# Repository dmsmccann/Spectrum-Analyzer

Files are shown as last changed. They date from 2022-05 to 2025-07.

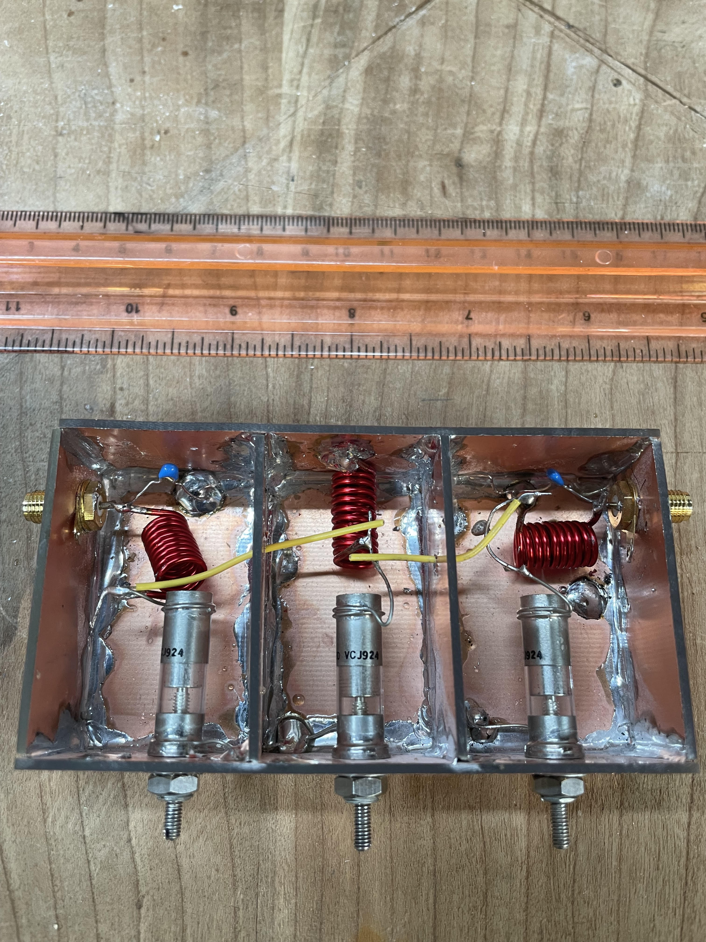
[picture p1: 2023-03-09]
110mhz-filter image.jpg

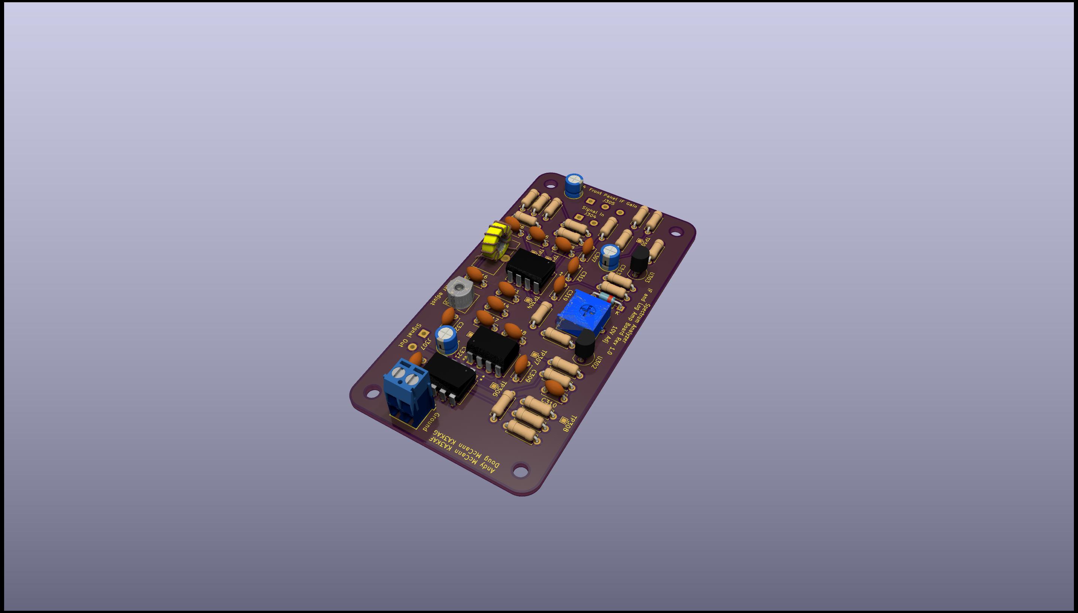
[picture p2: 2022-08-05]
if-and-log-amp/if-and-log-amp/if-and-log-amp.jpg

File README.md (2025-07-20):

# W7ZOI Spectrum Analyzer

## KiCad Implementation with modifications by Andy McCann KA3KAF and Doug McCann KA3KAG

## Overview

This repository contains a complete KiCad implementation of the famous W7ZOI Spectrum Analyzer design, originally published in QST magazine. The W7ZOI spectrum analyzer is a well-regarded amateur radio test instrument design that provides a cost-effective solution for RF spectrum analysis.

## Project Description

The W7ZOI Spectrum Analyzer is a superheterodyne spectrum analyzer designed for amateur radio applications. It provides frequency analysis capabilities across the HF and VHF bands, making it an invaluable tool for antenna analysis, filter characterization, and general RF measurements.

### Key Features

- **Frequency Range**: Covers HF through VHF bands
- **Modular Design**: Hierarchical schematic organization for easy understanding and modification
- **Complete Implementation**: Includes all necessary subsystems:
  - VCO and 1st Mixer
  - 110 MHz / 7 MHz Filter sections
  - IF and Log Amplifier
  - 2nd Mixer and 2nd LO
  - Resolution Filters
  - Timebase circuitry
  - 15V Power Supply
  - 2dB Divider
  - 70 MHz Low-pass Filter

## Repository Structure

```text
├── hierarchical-schematic/     # Main hierarchical schematic files
├── 110mhz/                    # 110 MHz filter module
├── 15v-supply/                # Power supply module
├── 2db-div/                   # 2dB divider module
├── 2ndmixer-2ndlo/           # 2nd mixer and LO module
├── 70mhz-lpf/                # 70 MHz low-pass filter
├── 7mhz-crystal-oscillator/  # 7 MHz crystal oscillator
├── if-and-log-amp/           # IF and log amplifier
├── resolution-filters/        # Resolution filter bank
├── timebase/                 # Timebase generation
├── tracking-generator/        # Tracking generator module
├── vco-1stmixer/             # VCO and 1st mixer
├── literature/               # Reference documentation and articles
├── images/                   # Project images and diagrams
└── experimental-data/        # Test data and measurements
```

## Hardware Modules

### Core RF Path

- **VCO and 1st Mixer**: Frequency conversion front-end
- **110 MHz Filter**: First IF filtering
- **7 MHz Crystal Oscillator**: Local oscillator reference
- **2nd Mixer and LO**: Second frequency conversion
- **IF and Log Amplifier**: Signal conditioning and logarithmic response

### Support Circuits

- **15V Power Supply**: Clean, regulated power for all modules
- **Resolution Filters**: Selectable bandwidth filters
- **70 MHz Low-pass Filter**: Anti-aliasing and spurious suppression
- **2dB Divider**: Signal distribution
- **Timebase**: Sweep generation and timing

### Optional Modules

- **Tracking Generator**: Signal source for swept measurements
- **Two-tone Test**: Distortion analysis capability

## Documentation

The `literature/` directory contains extensive reference material including:

- Original QST articles (September 1998, November 1999, June 2001)
- Construction notes and updates
- Filter design references
- Technical papers on spectrum analysis
- Modification and improvement documentation

## Getting Started

### Prerequisites

- KiCad 6.0 or later
- Basic understanding of RF circuit design
- Amateur radio license (for legal operation)

### Opening the Project

1. Clone this repository
2. Open KiCad
3. Load the main project file: `hierarchical-schematic/W7ZOI Spectrum Analyzer.kicad_pro`

### Project Files

- **Schematic**: Hierarchical design with individual module schematics
- **PCB Layout**: Complete board layout for professional fabrication
- **3D Models**: Custom component models for visualization
- **BOM**: Bill of materials with part specifications

## Modifications and Improvements

This implementation includes several improvements over the original design:

- Updated component selections for current availability
- Improved PCB layout with better ground planes
- Enhanced power supply regulation
- Modernized connector choices
- Detailed silkscreen labeling

## Building the Analyzer

Refer to the documentation in the `literature/` directory for detailed construction information. The original QST articles provide comprehensive building instructions, alignment procedures, and performance specifications.

## Contributing

Contributions are welcome! Please feel free to submit issues, improvements, or additional documentation. When contributing:

1. Follow KiCad best practices for schematic and PCB design
2. Document any changes thoroughly
3. Test modifications before submitting
4. Update relevant documentation

## License

This project is based on the original W7ZOI design published in QST magazine. Please respect copyright and amateur radio regulations in your use of these designs.

## Authors and Acknowledgments

- **Original Design**: Wes Hayward (W7ZOI) and Terry White (VE3DTE)
- **KiCad Implementation**: Andy McCann (KA3KAF) and Doug McCann (KA3KAG)
- **Published in**: QST Magazine, September 1998 and subsequent articles

## References

- QST Magazine, September 1998: "A Spectrum Analyzer for the Radio Amateur"
- QST Magazine, November 1999: Part 2 and updates
- QST Magazine, June 2001: Additional modifications and tracking generator
- Various technical papers in the `literature/` directory

---

*This is an amateur radio project intended for educational and experimental use. Please ensure compliance with your local amateur radio regulations.*

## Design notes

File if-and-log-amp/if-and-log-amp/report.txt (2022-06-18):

Info: Processing symbol 'C304:Capacitor_THT:CP_Axial_L11.0mm_D6.0mm_P18.00mm_Horizontal'.
Info: Processing symbol 'C310:Capacitor_THT:C_Radial_D4.0mm_H5.0mm_P1.50mm'.
Info: Processing symbol 'R306:Resistor_THT:R_Axial_DIN0207_L6.3mm_D2.5mm_P7.62mm_Horizontal'.
Info: Processing symbol 'C315:if-log-amp:BFC280832659'.
Info: Processing symbol 'D301:Diode_THT:D_DO-35_SOD27_P7.62mm_Horizontal'.
Info: Processing symbol 'C313:Capacitor_THT:CP_Axial_L11.0mm_D6.0mm_P18.00mm_Horizontal'.
Info: Processing symbol 'C319:Capacitor_THT:C_Radial_D4.0mm_H5.0mm_P1.50mm'.
Info: Processing symbol 'R305:Resistor_THT:R_Axial_DIN0207_L6.3mm_D2.5mm_P7.62mm_Horizontal'.
Info: Processing symbol 'C322:Capacitor_THT:C_Radial_D4.0mm_H5.0mm_P1.50mm'.
Info: Processing symbol 'C308:Capacitor_THT:C_Radial_D4.0mm_H5.0mm_P1.50mm'.
Info: Processing symbol 'C305:Capacitor_THT:C_Radial_D4.0mm_H5.0mm_P1.50mm'.
Info: Processing symbol 'L301:Inductor_THT:L_Toroid_Horizontal_D12.7mm_P20.00mm_Diameter14-5mm_Amidon-T50'.
Info: Processing symbol 'C311:Capacitor_THT:C_Radial_D4.0mm_H5.0mm_P1.50mm'.
Info: Processing symbol 'R303:Resistor_THT:R_Axial_DIN0207_L6.3mm_D2.5mm_P7.62mm_Horizontal'.
Info: Processing symbol 'C321:Capacitor_THT:C_Radial_D4.0mm_H5.0mm_P1.50mm'.
Info: Processing symbol 'R308:Resistor_THT:R_Axial_DIN0207_L6.3mm_D2.5mm_P7.62mm_Horizontal'.
Info: Processing symbol 'C316:Capacitor_THT:C_Radial_D4.0mm_H5.0mm_P1.50mm'.
Info: Processing symbol 'C314:Capacitor_THT:C_Radial_D4.0mm_H5.0mm_P1.50mm'.
Info: Processing symbol 'C318:Capacitor_THT:C_Radial_D4.0mm_H5.0mm_P1.50mm'.
Info: Processing symbol 'C309:Capacitor_THT:C_Radial_D4.0mm_H5.0mm_P1.50mm'.
Info: Processing symbol 'C306:Capacitor_THT:C_Radial_D4.0mm_H5.0mm_P1.50mm'.
Info: Processing symbol 'R302:Resistor_THT:R_Axial_DIN0207_L6.3mm_D2.5mm_P7.62mm_Horizontal'.
Info: Processing symbol 'R304:Resistor_THT:R_Axial_DIN0207_L6.3mm_D2.5mm_P7.62mm_Horizontal'.
Info: Processing symbol 'C312:Capacitor_THT:C_Radial_D4.0mm_H5.0mm_P1.50mm'.
Info: Processing symbol 'R301:Resistor_THT:R_Axial_DIN0207_L6.3mm_D2.5mm_P7.62mm_Horizontal'.
Info: Processing symbol 'C320:Capacitor_THT:C_Radial_D4.0mm_H5.0mm_P1.50mm'.
Info: Processing symbol 'R307:Resistor_THT:R_Axial_DIN0207_L6.3mm_D2.5mm_P7.62mm_Horizontal'.
Info: Processing symbol 'J301:if-log-amp:TE_5-1634503-1'.
Info: Processing symbol 'C317:Capacitor_THT:C_Radial_D4.0mm_H5.0mm_P1.50mm'.
Info: Processing symbol 'C307:Capacitor_THT:C_Radial_D4.0mm_H5.0mm_P1.50mm'.
Info: Processing symbol 'R309:Resistor_THT:R_Axial_DIN0207_L6.3mm_D2.5mm_P7.62mm_Horizontal'.
Info: Processing symbol 'R310:Resistor_THT:R_Axial_DIN0207_L6.3mm_D2.5mm_P7.62mm_Horizontal'.
Info: Processing symbol 'R311:Resistor_THT:R_Axial_DIN0207_L6.3mm_D2.5mm_P7.62mm_Horizontal'.
Info: Processing symbol 'R312:Resistor_THT:R_Axial_DIN0207_L6.3mm_D2.5mm_P7.62mm_Horizontal'.
Info: Processing symbol 'R313:Resistor_THT:R_Axial_DIN0207_L6.3mm_D2.5mm_P7.62mm_Horizontal'.
Info: Processing symbol 'R314:Resistor_THT:R_Axial_DIN0207_L6.3mm_D2.5mm_P7.62mm_Horizontal'.
Info: Processing symbol 'R315:Resistor_THT:R_Axial_DIN0207_L6.3mm_D2.5mm_P7.62mm_Horizontal'.
Info: Processing symbol 'R316:Resistor_THT:R_Axial_DIN0207_L6.3mm_D2.5mm_P7.62mm_Horizontal'.
Info: Processing symbol 'R317:Resistor_THT:R_Axial_DIN0207_L6.3mm_D2.5mm_P7.62mm_Horizontal'.
Info: Processing symbol 'R318:Resistor_THT:R_Axial_DIN0207_L6.3mm_D2.5mm_P7.62mm_Horizontal'.
Info: Processing symbol 'R319:Resistor_THT:R_Axial_DIN0207_L6.3mm_D2.5mm_P7.62mm_Horizontal'.
Info: Processing symbol 'R320:Resistor_THT:R_Axial_DIN0207_L6.3mm_D2.5mm_P7.62mm_Horizontal'.
Info: Processing symbol 'R321:Resistor_THT:R_Axial_DIN0207_L6.3mm_D2.5mm_P7.62mm_Horizontal'.
Info: Processing symbol 'RV302:Potentiometer_THT:Potentiometer_Bourns_3386X_Horizontal'.
Info: Processing symbol 'U301:if-log-amp:AD603AQ'.
Info: Processing symbol 'U302:Package_TO_SOT_THT:TO-92_Inline'.
Info: Processing symbol 'U303:Package_TO_SOT_THT:TO-92_Inline'.
Info: Processing symbol 'U304:if-log-amp:AD8307AN'.
Info: Processing symbol 'U305:if-log-amp:CA3140EZ'.
Changed REF** reference designator to C306.
Changed C306 value from C_Radial_D4.0mm_H5.0mm_P1.50mm to .1u.
Updated C306 symbol association from  to /9820123e-ee0b-406e-85c4-628830c0a33b.
Updated C306 properties.
Add net Net-(C306-Pad1).
Connected C306 pin 1 to Net-(C306-Pad1).
Connected C306 pin 2 to GND.
Added C307 (footprint 'Capacitor_THT:C_Radial_D4.0mm_H5.0mm_P1.50mm').
Changed REF** reference designator to C307.
Changed C307 value from C_Radial_D4.0mm_H5.0mm_P1.50mm to .1u.
Updated C307 symbol association from  to /5ba19575-6efd-4422-b1e1-564235bc68c0.
Updated C307 properties.
Add net Net-(C307-Pad1).
Connected C307 pin 1 to Net-(C307-Pad1).
Connected C307 pin 2 to GND.
Added C308 (footprint 'Capacitor_THT:C_Radial_D4.0mm_H5.0mm_P1.50mm').
Changed REF** reference designator to C308.
Changed C308 value from C_Radial_D4.0mm_H5.0mm_P1.50mm to .1u.
Updated C308 symbol association from  to /a3178939-5806-4853-8ab0-3b5b0e2adea2.
Updated C308 properties.
Add net Net-(C308-Pad1).
Connected C308 pin 1 to Net-(C308-Pad1).
Connected C308 pin 2 to GND.
Added C309 (footprint 'Capacitor_THT:C_Radial_D4.0mm_H5.0mm_P1.50mm').
Changed REF** reference designator to C309.
Changed C309 value from C_Radial_D4.0mm_H5.0mm_P1.50mm to .1u.
Updated C309 symbol association from  to /5166ee21-16cc-47d4-a438-2c0e2aa8959c.
Updated C309 properties.
Add net +5.
Connected C309 pin 1 to +5.
Connected C309 pin 2 to GND.
Added C310 (footprint 'Capacitor_THT:C_Radial_D4.0mm_H5.0mm_P1.50mm').
Changed REF** reference designator to C310.
Changed C310 value from C_Radial_D4.0mm_H5.0mm_P1.50mm to .22u.
Updated C310 symbol association from  to /51520694-f144-46ec-abc9-3b4b099a121b.
Updated C310 properties.
Add net Net-(C310-Pad1).
Connected C310 pin 1 to Net-(C310-Pad1).
Connected C310 pin 2 to GND.
Added C311 (footprint 'Capacitor_THT:C_Radial_D4.0mm_H5.0mm_P1.50mm').
Changed REF** reference designator to C311.
Changed C311 value from C_Radial_D4.0mm_H5.0mm_P1.50mm to 18u.
Updated C311 symbol association from  to /b12b094c-4aa1-4993-91f7-74934ef5d33a.
Updated C311 properties.
Add net Net-(C311-Pad1).
Connected C311 pin 1 to Net-(C311-Pad1).
Connected C311 pin 2 to GND.
Added C312 (footprint 'Capacitor_THT:C_Radial_D4.0mm_H5.0mm_P1.50mm').
Changed REF** reference designator to C312.
Changed C312 value from C_Radial_D4.0mm_H5.0mm_P1.50mm to .1u.
Updated C312 symbol association from  to /dd6e314d-05ac-4fb8-8556-fc394b83fd81.
Updated C312 properties.
Connected C312 pin 1 to GND.
Add net Net-(C312-Pad2).
Connected C312 pin 2 to Net-(C312-Pad2).
Added C313 (footprint 'Capacitor_THT:CP_Axial_L11.0mm_D6.0mm_P18.00mm_Horizontal').
Changed REF** reference designator to C313.
Changed C313 value from CP_Axial_L11.0mm_D6.0mm_P18.00mm_Horizontal to 22u.
Updated C313 symbol association from  to /bab3fc61-7ffc-43fd-b7e1-a49971a5fd5e.
Updated C313 properties.
Add net +10.
Connected C313 pin 1 to +10.
Connected C313 pin 2 to GND.
Added C314 (footprint 'Capacitor_THT:C_Radial_D4.0mm_H5.0mm_P1.50mm').
Changed REF** reference designator to C314.
Changed C314 value from C_Radial_D4.0mm_H5.0mm_P1.50mm to 5.6p.
Updated C314 symbol association from  to /91d7fb34-034b-427e-b533-f5cd3e05cc45.
Updated C314 properties.
Add net Net-(C314-Pad1).
Connected C314 pin 1 to Net-(C314-Pad1).
Add net Net-(C314-Pad2).
Connected C314 pin 2 to Net-(C314-Pad2).
Added C315 (footprint 'if-log-amp:BFC280832659').
Changed REF** reference designator to C315.
Changed C315 value from BFC280832659_VIS to 50p.
Updated C315 symbol association from  to /6da294e0-d0ea-4520-9eae-214e4e104da5.
Updated C315 properties.
Connected C315 pin 1 to Net-(C314-Pad2).
Connected C315 pin 2 to GND.
Added C316 (footprint 'Capacitor_THT:C_Radial_D4.0mm_H5.0mm_P1.50mm').
Changed REF** reference designator to C316.
Changed C316 value from C_Radial_D4.0mm_H5.0mm_P1.50mm to 220p.
Updated C316 symbol association from  to /aa7337a7-5d79-4c08-a459-a9e6ac935626.
Updated C316 properties.
Connected C316 pin 1 to Net-(C314-Pad2).
Connected C316 pin 2 to GND.
Added C317 (footprint 'Capacitor_THT:C_Radial_D4.0mm_H5.0mm_P1.50mm').
Changed REF** reference designator to C317.
Changed C317 value from C_Radial_D4.0mm_H5.0mm_P1.50mm to 5.6p.
Updated C317 symbol association from  to /78209a31-876f-4c56-841c-74e6cb8fd1d6.
Updated C317 properties.
Connected C317 pin 1 to Net-(C314-Pad2).
Add net Net-(C317-Pad2).
Connected C317 pin 2 to Net-(C317-Pad2).
Added C318 (footprint 'Capacitor_THT:C_Radial_D4.0mm_H5.0mm_P1.50mm').
Changed REF** reference designator to C318.
Changed C318 value from C_Radial_D4.0mm_H5.0mm_P1.50mm to .1u.
Updated C318 symbol association from  to /23123e42-75d0-43b0-9621-e0f69246e803.
Updated C318 properties.
Add net Net-(C318-Pad1).
Connected C318 pin 1 to Net-(C318-Pad1).
Connected C318 pin 2 to GND.
Added C319 (footprint 'Capacitor_THT:C_Radial_D4.0mm_H5.0mm_P1.50mm').
Changed REF** reference designator to C319.
Changed C319 value from C_Radial_D4.0mm_H5.0mm_P1.50mm to .1u.
Updated C319 symbol association from  to /1d204aa6-a518-43b9-a5b1-23f9a215d4d4.
Updated C319 properties.
Add net Net-(C319-Pad1).
Connected C319 pin 1 to Net-(C319-Pad1).
Connected C319 pin 2 to GND.
Added C320 (footprint 'Capacitor_THT:C_Radial_D4.0mm_H5.0mm_P1.50mm').
Changed REF** reference designator to C320.
Changed C320 value from C_Radial_D4.0mm_H5.0mm_P1.50mm to .1u.
Updated C320 symbol association from  to /7d99c491-33ce-40dc-acc4-86f4b22e23c1.
Updated C320 properties.
Connected C320 pin 1 to GND.
Add net Net-(C320-Pad2).
Connected C320 pin 2 to Net-(C320-Pad2).
Added C321 (footprint 'Capacitor_THT:C_Radial_D4.0mm_H5.0mm_P1.50mm').
Changed REF** reference designator to C321.
Changed C321 value from C_Radial_D4.0mm_H5.0mm_P1.50mm to .001u.
Updated C321 symbol association from  to /1d1828e0-ef6a-4d62-86f7-04de80195c59.
Updated C321 properties.
Add net Net-(C321-Pad1).
Connected C321 pin 1 to Net-(C321-Pad1).
Connected C321 pin 2 to GND.
Added C322 (footprint 'Capacitor_THT:C_Radial_D4.0mm_H5.0mm_P1.50mm').
Changed REF** reference designator to C322.
Changed C322 value from C_Radial_D4.0mm_H5.0mm_P1.50mm to .1u.
Updated C322 symbol association from  to /1928ea0f-1556-47b4-a373-051ec2056356.
Updated C322 properties.
Connected C322 pin 1 to GND.
Add net Net-(C322-Pad2).
Connected C322 pin 2 to Net-(C322-Pad2).
Added D301 (footprint 'Diode_THT:D_DO-35_SOD27_P7.62mm_Horizontal').
Changed REF** reference designator to D301.
Changed D301 value from D_DO-35_SOD27_P7.62mm_Horizontal to 1N4152.
Updated D301 symbol association from  to /c2bdd96b-ae16-41e0-9c01-22c8cd929bb9.
Updated D301 properties.
Connected D301 pin 1 to Net-(C319-Pad1).
Connected D301 pin 2 to +10.
Added J301 (footprint 'if-log-amp:TE_5-1634503-1').
Changed REF** reference designator to J301.
Changed J301 value from TE_5-1634503-1 to Conn_Coaxial.
Updated J301 symbol association from  to /6987431d-46da-4786-8718-591cfd165b0a.
Updated J301 properties.
Connected J301 pin 1 to Net-(C305-Pad1).
Connected J301 pin 2 to GND.
Added L301 (footprint 'Inductor_THT:L_Toroid_Horizontal_D12.7mm_P20.00mm_Diameter14-5mm_Amidon-T50').
Changed REF** reference designator to L301.
Changed L301 value from L_Toroid_Horizontal_D12.7mm_P20.00mm_Diameter14-5mm_Amidon-T50 to 1.05u.
Updated L301 symbol association from  to /697a2a42-69fd-436b-8fcf-3eb612b271b7.
Updated L301 properties.
Connected L301 pin 1 to GND.
Connected L301 pin 2 to Net-(C314-Pad2).
Added R301 (footprint 'Resistor_THT:R_Axial_DIN0207_L6.3mm_D2.5mm_P7.62mm_Horizontal').
Changed REF** reference designator to R301.
Changed R301 value from R_Axial_DIN0207_L6.3mm_D2.5mm_P7.62mm_Horizontal to 2.2k.
Updated R301 symbol association from  to /1a9c0a71-bdd3-4d66-8773-86c965feed0c.
Updated R301 properties.
Connected R301 pin 1 to +10.
Connected R301 pin 2 to Net-(C304-Pad1).
Added R302 (footprint 'Resistor_THT:R_Axial_DIN0207_L6.3mm_D2.5mm_P7.62mm_Horizontal').
Changed REF** reference designator to R302.
Changed R302 value from R_Axial_DIN0207_L6.3mm_D2.5mm_P7.62mm_Horizontal to 2.2k.
Updated R302 symbol association from  to /1576052f-7341-4649-961a-6fa44acd4add.
Updated R302 properties.
Connected R302 pin 1 to Net-(C304-Pad1).
Connected R302 pin 2 to GND.
Added R303 (footprint 'Resistor_THT:R_Axial_DIN0207_L6.3mm_D2.5mm_P7.62mm_Horizontal').
Changed REF** reference designator to R303.
Changed R303 value from R_Axial_DIN0207_L6.3mm_D2.5mm_P7.62mm_Horizontal to 100.
Updated R303 symbol association from  to /e2d92c44-d5f1-4abb-8fbb-b5f1dcb76fd8.
Updated R303 properties.
Connected R303 pin 1 to Net-(C305-Pad1).
Connected R303 pin 2 to GND.
Added R304 (footprint 'Resistor_THT:R_Axial_DIN0207_L6.3mm_D2.5mm_P7.62mm_Horizontal').
Changed REF** reference designator to R304.
Changed R304 value from R_Axial_DIN0207_L6.3mm_D2.5mm_P7.62mm_Horizontal to 680.
Updated R304 symbol association from  to /f7ed73da-c6e3-4daa-953c-e3cc3a1f7346.
Updated R304 properties.
Connected R304 pin 1 to +10.
Add net Net-(C301-Pad3).
Connected R304 pin 2 to Net-(C301-Pad3).
Added R305 (footprint 'Resistor_THT:R_Axial_DIN0207_L6.3mm_D2.5mm_P7.62mm_Horizontal').
Changed REF** reference designator to R305.
Changed R305 value from R_Axial_DIN0207_L6.3mm_D2.5mm_P7.62mm_Horizontal to 510.
Updated R305 symbol association from  to /50f57d44-dd7d-4fad-a1cd-c5c75ef37e61.
Updated R305 properties.
Connected R305 pin 1 to Net-(C301-Pad3).
Add net Net-(C303-Pad3).
Connected R305 pin 2 to Net-(C303-Pad3).
Added R306 (footprint 'Resistor_THT:R_Axial_DIN0207_L6.3mm_D2.5mm_P7.62mm_Horizontal').
Changed REF** reference designator to R306.
Changed R306 value from R_Axial_DIN0207_L6.3mm_D2.5mm_P7.62mm_Horizontal to 1k.
Updated R306 symbol association from  to /9a7b9e44-1c46-43e8-8a39-bcc40d29da37.
Updated R306 properties.
Connected R306 pin 1 to Net-(C303-Pad3).
Connected R306 pin 2 to GND.
Added R307 (footprint 'Resistor_THT:R_Axial_DIN0207_L6.3mm_D2.5mm_P7.62mm_Horizontal').
Changed REF** reference designator to R307.
Changed R307 value from R_Axial_DIN0207_L6.3mm_D2.5mm_P7.62mm_Horizontal to 51.
Updated R307 symbol association from  to /ac964def-301e-4952-bb3b-cd9cbd1eebb9.
Updated R307 properties.
Connected R307 pin 1 to Net-(C304-Pad1).
Connected R307 pin 2 to Net-(C306-Pad1).
Added R308 (footprint 'Resistor_THT:R_Axial_DIN0207_L6.3mm_D2.5mm_P7.62mm_Horizontal').
Changed REF** reference designator to R308.
Changed R308 value from R_Axial_DIN0207_L6.3mm_D2.5mm_P7.62mm_Horizontal to 2.2k.
Updated R308 symbol association from  to /bc663e7e-08a9-4a6b-8220-6d0f3194a366.
Updated R308 properties.
Connected R308 pin 1 to Net-(C307-Pad1).
Add net Net-(C302-Pad3).
Connected R308 pin 2 to Net-(C302-Pad3).
Added C304 (footprint 'Capacitor_THT:CP_Axial_L11.0mm_D6.0mm_P18.00mm_Horizontal').
Added R309 (footprint 'Resistor_THT:R_Axial_DIN0207_L6.3mm_D2.5mm_P7.62mm_Horizontal').
Changed REF** reference designator to R309.
Changed R309 value from R_Axial_DIN0207_L6.3mm_D2.5mm_P7.62mm_Horizontal to 4.3k.
Updated R309 symbol association from  to /c254d62d-da71-4878-93ec-01c9a953e41b.
Updated R309 properties.
Connected R309 pin 1 to Net-(C308-Pad1).
Add net V+10.
Connected R309 pin 2 to V+10.
Changed REF** reference designator to C304.
Added R310 (footprint 'Resistor_THT:R_Axial_DIN0207_L6.3mm_D2.5mm_P7.62mm_Horizontal').
Changed REF** reference designator to R310.
Changed R310 value from R_Axial_DIN0207_L6.3mm_D2.5mm_P7.62mm_Horizontal to 5.6k.
Updated R310 symbol association from  to /50f3f762-3ffd-4bea-9880-dd80edaf4b44.
Updated R310 properties.
Connected R310 pin 1 to V+10.
Connected R310 pin 2 to GND.
Changed C304 value from CP_Axial_L11.0mm_D6.0mm_P18.00mm_Horizontal to 100u.
Added R311 (footprint 'Resistor_THT:R_Axial_DIN0207_L6.3mm_D2.5mm_P7.62mm_Horizontal').
Changed REF** reference designator to R311.
Changed R311 value from R_Axial_DIN0207_L6.3mm_D2.5mm_P7.62mm_Horizontal to 10.
Updated R311 symbol association from  to /2807793f-2348-49f9-9dc3-4463159e5569.
Updated R311 properties.
Add net +15.
Connected R311 pin 1 to +15.
Connected R311 pin 2 to Net-(C310-Pad1).
Updated C304 symbol association from  to /64110ddc-ff1e-47ec-ab85-a28e7bae22d6.
Added R312 (footprint 'Resistor_THT:R_Axial_DIN0207_L6.3mm_D2.5mm_P7.62mm_Horizontal').
Changed REF** reference designator to R312.
Changed R312 value from R_Axial_DIN0207_L6.3mm_D2.5mm_P7.62mm_Horizontal to 10.
Updated R312 symbol association from  to /64b3d758-146d-498c-8e36-a7162573fa48.
Updated R312 properties.
Connected R312 pin 1 to +10.
Connected R312 pin 2 to Net-(C312-Pad2).
Updated C304 properties.
Added R313 (footprint 'Resistor_THT:R_Axial_DIN0207_L6.3mm_D2.5mm_P7.62mm_Horizontal').
Changed REF** reference designator to R313.
Changed R313 value from R_Axial_DIN0207_L6.3mm_D2.5mm_P7.62mm_Horizontal to 1k.
Updated R313 symbol association from  to /badbf28d-7dcc-468c-b51f-6cc1547b9546.
Updated R313 properties.
Add net Net-(R313-Pad1).
Connected R313 pin 1 to Net-(R313-Pad1).
Connected R313 pin 2 to Net-(C314-Pad1).
Add net Net-(C304-Pad1).
Added R314 (footprint 'Resistor_THT:R_Axial_DIN0207_L6.3mm_D2.5mm_P7.62mm_Horizontal').
Changed REF** reference designator to R314.
Changed R314 value from R_Axial_DIN0207_L6.3mm_D2.5mm_P7.62mm_Horizontal to 220.
Updated R314 symbol association from  to /c792d8d9-4817-4d6f-a57e-3c117c43a497.
Updated R314 properties.
Connected R314 pin 1 to +10.
Add net Net-(R314-Pad2).
Connected R314 pin 2 to Net-(R314-Pad2).
Connected C304 pin 1 to Net-(C304-Pad1).
Added R315 (footprint 'Resistor_THT:R_Axial_DIN0207_L6.3mm_D2.5mm_P7.62mm_Horizontal').
Changed REF** reference designator to R315.
Changed R315 value from R_Axial_DIN0207_L6.3mm_D2.5mm_P7.62mm_Horizontal to 1.5k.
Updated R315 symbol association from  to /faaa4eb1-3a85-4ffb-8e62-4408e03c107e.
Updated R315 properties.
Connected R315 pin 1 to Net-(R314-Pad2).
Add net Net-(R315-Pad2).
Connected R315 pin 2 to Net-(R315-Pad2).
Add net GND.
Added R316 (footprint 'Resistor_THT:R_Axial_DIN0207_L6.3mm_D2.5mm_P7.62mm_Horizontal').
Changed REF** reference designator to R316.
Changed R316 value from R_Axial_DIN0207_L6.3mm_D2.5mm_P7.62mm_Horizontal to 10.
Updated R316 symbol association from  to /e4b4dd5e-42a4-4627-8586-9eebeb529b8b.
Updated R316 properties.
Connected R316 pin 1 to +15.
Connected R316 pin 2 to Net-(C319-Pad1).
Connected C304 pin 2 to GND.
Added R317 (footprint 'Resistor_THT:R_Axial_DIN0207_L6.3mm_D2.5mm_P7.62mm_Horizontal').
Changed REF** reference designator to R317.
Changed R317 value from R_Axial_DIN0207_L6.3mm_D2.5mm_P7.62mm_Horizontal to 10.
Updated R317 symbol association from  to /9759ad16-ddc1-4e8a-bc93-f83048114bb5.
Updated R317 properties.
Connected R317 pin 1 to +5.
Connected R317 pin 2 to Net-(C318-Pad1).
Added C305 (footprint 'Capacitor_THT:C_Radial_D4.0mm_H5.0mm_P1.50mm').
Added R318 (footprint 'Resistor_THT:R_Axial_DIN0207_L6.3mm_D2.5mm_P7.62mm_Horizontal').
Changed REF** reference designator to R318.
Changed R318 value from R_Axial_DIN0207_L6.3mm_D2.5mm_P7.62mm_Horizontal to 680.
Updated R318 symbol association from  to /9e5623f9-783d-4878-97fe-cbfa33a06396.
Updated R318 properties.
Add net Net-(R318-Pad1).
Connected R318 pin 1 to Net-(R318-Pad1).
Connected R318 pin 2 to GND.
Changed REF** reference designator to C305.
Added R319 (footprint 'Resistor_THT:R_Axial_DIN0207_L6.3mm_D2.5mm_P7.62mm_Horizontal').
Changed REF** reference designator to R319.
Changed R319 value from R_Axial_DIN0207_L6.3mm_D2.5mm_P7.62mm_Horizontal to 51.
Updated R319 symbol association from  to /f31196ed-79cf-40fd-816f-a4b56947f2d0.
Updated R319 properties.
Connected R319 pin 1 to Net-(C322-Pad2).
Add net Net-(C324-Pad1).
Connected R319 pin 2 to Net-(C324-Pad1).
Changed C305 value from C_Radial_D4.0mm_H5.0mm_P1.50mm to .1u.
Added R320 (footprint 'Resistor_THT:R_Axial_DIN0207_L6.3mm_D2.5mm_P7.62mm_Horizontal').
Changed REF** reference designator to R320.
Changed R320 value from R_Axial_DIN0207_L6.3mm_D2.5mm_P7.62mm_Horizontal to 2.2k.
Updated R320 symbol association from  to /1e3aa0e9-23c7-4a4f-8055-3fc31c319208.
Updated R320 properties.
Add net Net-(R320-Pad1).
Connected R320 pin 1 to Net-(R320-Pad1).
Connected R320 pin 2 to Net-(R318-Pad1).
Updated C305 symbol association from  to /bb16a516-4131-4a51-bbea-b711bad6e2cf.
Added R321 (footprint 'Resistor_THT:R_Axial_DIN0207_L6.3mm_D2.5mm_P7.62mm_Horizontal').
Changed REF** reference designator to R321.
Changed R321 value from R_Axial_DIN0207_L6.3mm_D2.5mm_P7.62mm_Horizontal to 1k.
Updated R321 symbol association from  to /7746434b-c9c9-48c3-a08d-6e02730ecb43.
Updated R321 properties.
Connected R321 pin 1 to Net-(R320-Pad1).
Add net Net-(C323-Pad1).
Connected R321 pin 2 to Net-(C323-Pad1).
Updated C305 properties.
Added RV302 (footprint 'Potentiometer_THT:Potentiometer_Bourns_3386X_Horizontal').
Changed REF** reference designator to RV302.
Changed RV302 value from Potentiometer_Bourns_3386X_Horizontal to 100.
Updated RV302 symbol association from  to /0c71b5d8-a695-40fb-820d-59a5cec04f71.
Updated RV302 properties.
Connected RV302 pin 1 to Net-(R315-Pad2).
Connected RV302 pin 2 to GND.
Connected RV302 pin 3 to GND.
Add net Net-(C305-Pad1).
Added U301 (footprint 'if-log-amp:AD603AQ').
Changed REF** reference designator to U301.
Changed U301 value from Q_8_ADI to AD603AQ.
Updated U301 symbol association from  to /ebc7df2e-7b88-42e7-bc28-d43ddb17abe3.
Updated U301 properties.
Connected U301 pin 1 to Net-(C307-Pad1).
Connected U301 pin 2 to Net-(C308-Pad1).
Connected U301 pin 3 to Net-(C305-Pad2).
Connected U301 pin 4 to Net-(C306-Pad1).
Connected U301 pin 5 to Net-(C311-Pad1).
Connected U301 pin 6 to GND.
Connected U301 pin 7 to Net-(R313-Pad1).
Connected U301 pin 8 to Net-(C312-Pad2).
Connected C305 pin 1 to Net-(C305-Pad1).
Added U302 (footprint 'Package_TO_SOT_THT:TO-92_Inline').
Changed REF** reference designator to U302.
Changed U302 value from TO-92_Inline to L78L05_TO92.
Updated U302 symbol association from  to /df898859-dbc3-490a-8ee4-b0eb9fd23504.
Updated U302 properties.
Connected U302 pin 1 to +5.
Connected U302 pin 2 to GND.
Connected U302 pin 3 to Net-(C310-Pad1).
Add net Net-(C305-Pad2).
Added U303 (footprint 'Package_TO_SOT_THT:TO-92_Inline').
Changed REF** reference designator to U303.
Changed U303 value from TO-92_Inline to LM317L_TO92.
Updated U303 symbol association from  to /b5f5179d-051c-4d34-be04-3c4219daac93.
Updated U303 properties.
Connected U303 pin 1 to Net-(R314-Pad2).
Connected U303 pin 2 to +10.
Connected U303 pin 3 to Net-(C319-Pad1).
Connected C305 pin 2 to Net-(C305-Pad2).
Added U304 (footprint 'if-log-amp:AD8307AN').
Changed REF** reference designator to U304.
Changed U304 value from N_8_ADI to AD8307AN.
Updated U304 symbol association from  to /c814aa21-9c46-4566-a094-0e8d80cc6be7.
Updated U304 properties.
Connected U304 pin 1 to Net-(C320-Pad2).
Connected U304 pin 2 to GND.
Add net unconnected-(U304-Pad3).
Connected U304 pin 3 to unconnected-(U304-Pad3).
Connected U304 pin 4 to Net-(C321-Pad1).
Add net unconnected-(U304-Pad5).
Connected U304 pin 5 to unconnected-(U304-Pad5).
Connected U304 pin 6 to Net-(C318-Pad1).
Connected U304 pin 7 to Net-(C318-Pad1).
Connected U304 pin 8 to Net-(C317-Pad2).
Added C306 (footprint 'Capacitor_THT:C_Radial_D4.0mm_H5.0mm_P1.50mm').
Added U305 (footprint 'if-log-amp:CA3140EZ').
Changed REF** reference designator to U305.
Changed U305 value from PDIP8_7P11X10P16_REN to CA3140.
Updated U305 symbol association from  to /136266f2-a71e-4a9b-ac1e-bb1da15a76c1.
Updated U305 properties.
Connected U305 pin 1 to GND.
Connected U305 pin 2 to Net-(R318-Pad1).
Connected U305 pin 3 to Net-(C321-Pad1).
Add net unconnected-(U305-Pad4).
Connected U305 pin 4 to unconnected-(U305-Pad4).
Add net unconnected-(U305-Pad5).
Connected U305 pin 5 to unconnected-(U305-Pad5).
Connected U305 pin 6 to Net-(R320-Pad1).
Connected U305 pin 7 to Net-(C322-Pad2).
Add net unconnected-(U305-Pad8).
Connected U305 pin 8 to unconnected-(U305-Pad8).
Warning: No net found for symbol C315 pin 3.
Warning: No net found for symbol J301 pin 5.
Warning: No net found for symbol J301 pin 3.
Warning: No net found for symbol J301 pin 4.

Info: Total warnings: 0, errors: 0.

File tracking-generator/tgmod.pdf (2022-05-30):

3/18/2021 | tgmod

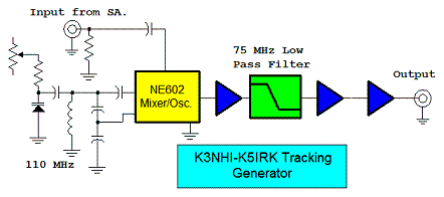
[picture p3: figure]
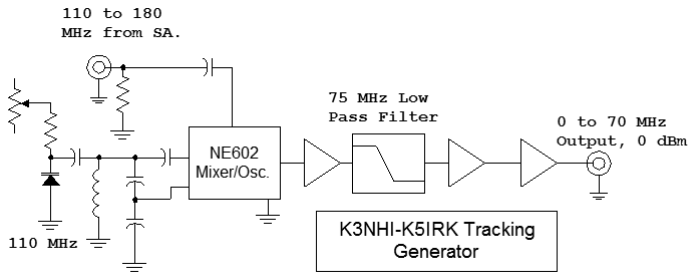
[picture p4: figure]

w7zoi.net/tgmod.html | 1/6

# Tracking Generator Modifications (31August06, 5Jan07, Major Update

### 2April2010 )

w7zoi, April, 2010

Bob Kopski, K3NHI, and John Lawson, K5IRK, have come up with a Simple Tracking Generator (STG) to go with the QST Spectrum Analyzer that K7TAU and I presented in the August/September 1998 issue of QST. Our original tracking generator circuit appeared in the November, 1999 QST. We used a high level mixer for that design. In retrospect, that was not really required. We had generated a power of +6 dBm, but then attenuated it through a pad to reach the desired output level of 0 dBm. A normal diode ring mixer would have done as well. Our original design used a crystal controlled 5th overtone oscillator. Although ideal, crystal control is not mandatory for the wide analyzer bandwidths available in our analyzer. A more detailed block diagram is shown below.

Bob and John did several things to simplify the overall design. First, they eliminated crystal control in the 110 MHz oscillator. Instead, an LC circuit was used. Their mixer was the popular NE602 (or 612) and they employed the built-in oscillator on the chip. A trimmer capacitor sets the frequency. A varactor diode is controlled by a front panel pot for exact adjustment. This is necessary, for there will be some thermal drift, although it is not severe. It is useful to use a high quality trimmer capacitor in the circuit. Bob used a home made one in his version of the TG while John used a commercially available part. Multiple turns for the adjustment are worthwhile.

The mixer in this analyzer is the Gilbert-Cell integral to the NE602. This mixer works with lower levels than are normally used with diode rings, so the signal levels throughout the system are smaller. The signal that is extracted from the SA must be attenuated before it can be used as an input to the Gilbert Cell. The output from the NE602 is applied directly to an amplifier with a very low input impedance. This operates like the upper transistor in a cascode connection, eliminating the attenuation characteristics of the normal NE602 output capacitance, serving to extend bandwidth.

The post mixer amplifier has a 50 Ohm output impedance that serves well to drive the low pass filter that eliminates the image component. The SMT low pass shown below in this note is recommended. If commercial SMT inductors cannot be found, a designer/builder could wind inductors in the threads of a machine screw. A coil winding program to facilitate this is found in the "experiments and designs" section of this web site. The home coils should be small and spaced at least a coil diameter or length from each other. They should be measured before insertion in the circuit.

The amplifier topology that Bob and John used in the STG consists of a common base stage with a cascade follower. This circuit is quite robust with excellent bandwidth.

The low pass filter drives a two stage amplifier with a 50 Ohm input impedance. This provides enough gain to generate an output close to 0 dBm. An exact output power value is not really needed. The detailed schematic for the STG is shown below:

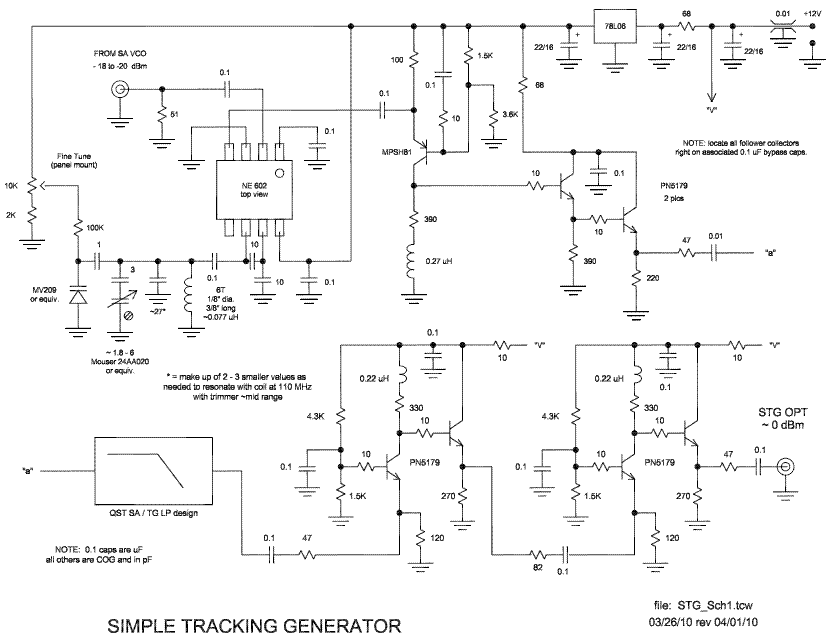
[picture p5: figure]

Although this tracking generator is much simpler than the original, it can still be a challenging project. The tracking generator is much like the transmitter portion of a familiar amateur radio transceiver. When the "receiver" portion of the system tunes, or sweeps to a new frequency, the transmitter tracks right along with it. However, there is one major difference, one that explains the potential difficulty in the measurement project. Unlike the usual communications transceiver, the two parts of a SA/TG pair must both operate at full performance at the same time! Good shielding is mandatory, as is effective bypassing and decoupling. One of the things discovered by Ed, KG4ARN (see info below) was that high quality feed through capacitors are worthwhile. The unit that he suggested is a Spectrum Control model 1201-066. This "bolt in the wall" pi filter is more than a mere capacitor and has a specified attenuation of 68 dB at 100 MHz. The inexpensive parts, like some "good buys" that I got on eBay, are only specified for 45 dB or so. Ed had measured some of the caps he was using as only offering 30 dB attenuation at 100 MHz. The good parts mentioned are available from Mouser for about $6 each. It may be necessary to use these parts in a couple of the VHF parts of the SA as well as in the supply line powering the tracking generator board. A tightly shielded box is mandatory for the TG. Good shielding is equally important for the sections of the spectrum analyzer.

Much more information on the new TG is provided by Bob and John on the EMRFD Yahoo Group in the "files" section as "K3NHI_K5IRK_STG". Bob's analyzer is one that tunes from DC to 100 MHz with a first IF near 150 MHz. John's is more of a carbon copy of the QST design. John found no measurable difference between his STG and the original TG design. But high quality feedthrough capacitors are important in both. Many thanks to both Bob and John for their efforts to generate a great new design.

## Most of the material that follows

applies to the original tracking generator.

Comments that apply to the STG are in red.

An email in 2006 from Ed Milcarsky, KG4ARN, dealt with a couple of problems with the tracking generator. First, he was seeing a "baseline rise" when the tracking generator was powered, but disconnected. Baseline rise is a phenomenon where the normal noise floor at the bottom of the of the screen increases uniformly across the screen. This degrades the minimum signal that can be detected, which then compromises the dynamic range that can be achieved with the spectrum analyzer --tracking generator combination. Baseline rise usually occurs when a non-swept signal at the analyzer IF gets into the IF and eventually to the log detector. In this case, the Baseline rise would come from energy at 10 MHz (unlikely) or at 110 (most probable) MHz. The other problem that Ed saw was excess energy at high frequency (above 70 MHz) coming from the tracking generator output. Ed didn't say how he measured this. He speculated that there may have been problems related to a poor high frequency termination. To fix this, Ed modified the block diagram of the tracking generator.

The figure below shows the changes that Ed made. The top part of the figure (A) shows the original block diagram while the diagram below that in (B) shows the modification that Ed did. He moved the 6 dB pad to directly follow the mixer. This will then guarantee a reasonable termination for all high and low frequency mixer products. The pad is followed by the low pass filter. Ed elected to use a Mini-Circuits PLP-70 filter in this slot. (Hey, why not. Everything else in the TG is from Mini-Circuits.) These details are not nearly as important with Kopski and Lawson's STG, for the Gilbert Cell mixer is not prone to the problems with termination sensitivity and signal reflection that we enjoy with diode rings.

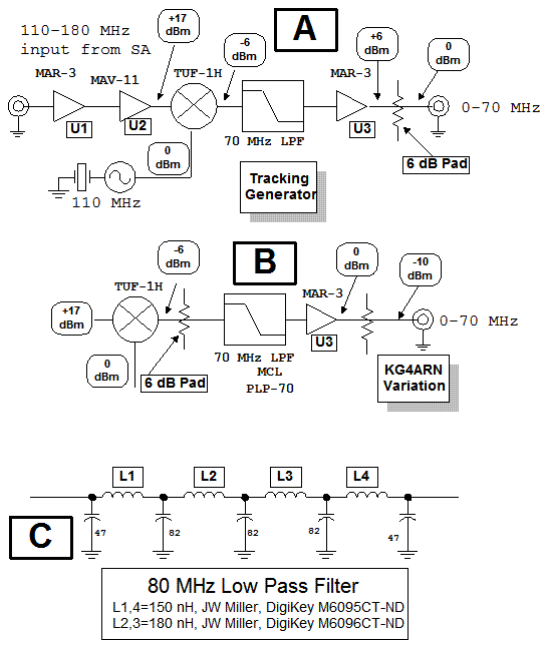
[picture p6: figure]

The note I got from Ed indicated that he pulled the output directly from U3 with no pad at the output. This is probably fine for most applications. The available output power should be around 0 dBm. For critical applications where it is important to have a very clean output impedance, it might be useful to include a 10 dB pad (100 Ohm parallel resistors with 68 Ohms series) in the output as I have shown the part B of the figure above. This is up to the experimenter/builder. The amplifiers used in the STG have well defined impedances at both input and output, without the interactions that are found in amplifiers with heavy parallel feedback.

Ed still had some anomalous behavior after the changes to the block diagram. He finally solved the last baseline rise and related problems by placing the 110 MHz LO in a separate box with high quality feedthrough capacitors. John Lawson had a similar experience.

Part C of the figure shows a SMT filter that should be suitable for the output of the tracking generator or for the front end of the analyzer itself. The inductors are by JW Miller and are 1210 sized parts. A calculated response for this circuit is shown below.

The red curve shows

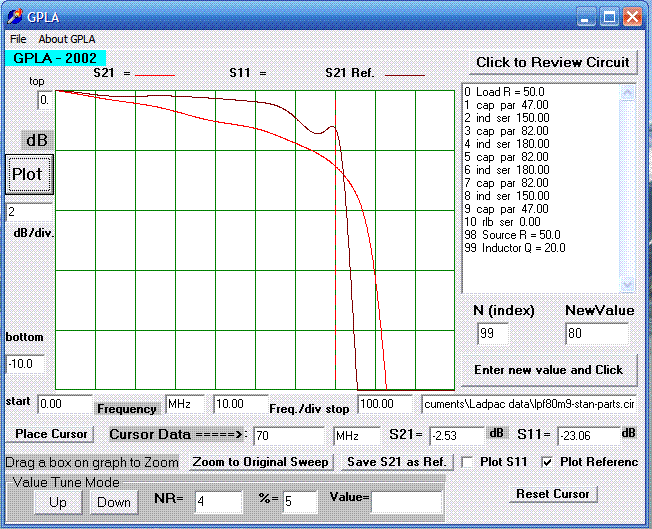
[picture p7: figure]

the response of the filter while the brown line is the response of the original low pass circuit. The new filter is assumed to use inductors with Qu=20 while I assumed Qu=80 for the original filter. The filter used in the spectrum analyzer and then repeated for the tracking generator was designed to use identical inductors, which is the origin of the ripple. There are minor ripples in the new filter, which started as a 0.1 dB Chebyshev design. The present ripples can be observed by setting Q to a very high value instead of the present 20. The Chebyshev passband shape disappeared when the original design values were perturbed so standard values could be used. The ripple is virtually gone in the final filter shape, a result of the loss. The loss is not out of hand though -- it is 2.5 dB at 70 MHz, assuming Qu=20. Note that the plots shown are obtained over a restricted 10 dB range. This SMT design is the filter that I would recommend for use in the STG.

We encourage builders to give some SMT a try. This low pass filter is a place where it really makes sense, for it improves the performance with lower parasitic inductance in the shunt capacitors. The virtues of SMT go beyond component density. It is unfortunate that so many radio amateurs approach SMT with fear, for it is not that difficult once suitable optical enhancements are in place.

Many thanks to Ed, KG4ARN, for telling us about his refinements. -------------------------------------------------------------------------------------------- Update -- January, 2007.

I finally got around to building the SMT low pass filter in 2007. The schematic is that shown above in part C of the figure showing KG4ARN's modifications. (These coils are no longer available from either Mouser or Digi-Key in 2010! Rats! ) I have built similar filters with lower Q inductors. They work, but the filter response drops by a couple of dB near the cutoff.

This is a photo of the completed filter. The above breadboard

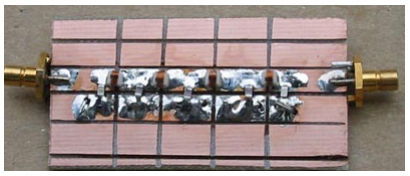
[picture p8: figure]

has two wire vias for each capacitor ground. The capacitors are size 0805, 5% C0G manufactured by AVX. I used SMB coaxial connectors to facilitate measurement.

This photo shows the measured filter response. The gentle passband loss in

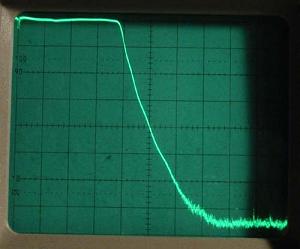
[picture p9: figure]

the simulation above is not evident, suggesting that the inductor Q may be higher than the value of 20 used with the simulation. The vertical divisions are 10 dB per division while the horizontal is 20 MHz per division (total span of 200 MHz.)

A wider 500 MHz total span showed two response peaks above 200 MHz, both still more than 60 dB below the peak low pass response. Modeling suggests that these come from series inductance in the chip capacitors and mutual inductance in the form of long ground leads between the capacitors.

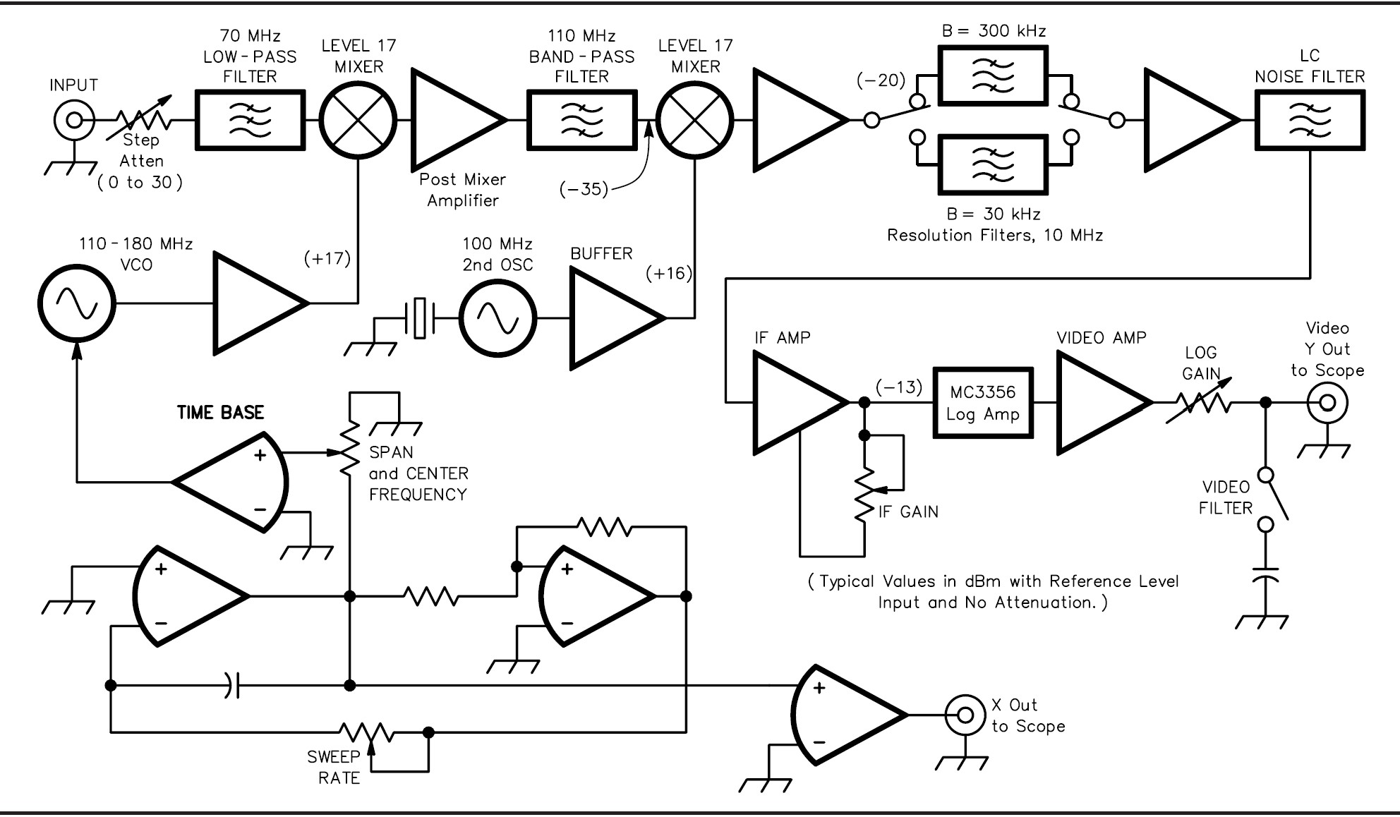
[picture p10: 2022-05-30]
hierarchical-schematic/Block Diagram for Spectrum Analyzer.jpg

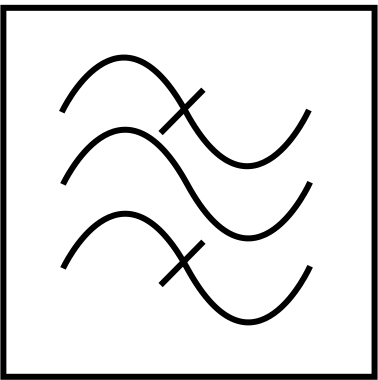
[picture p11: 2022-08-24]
Band-pass_filter_symbol.svg.png

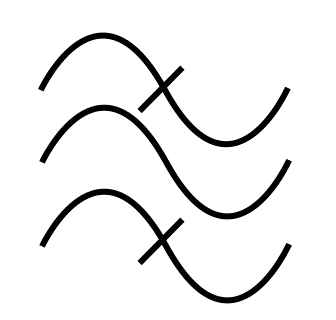
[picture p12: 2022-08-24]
filter.gif

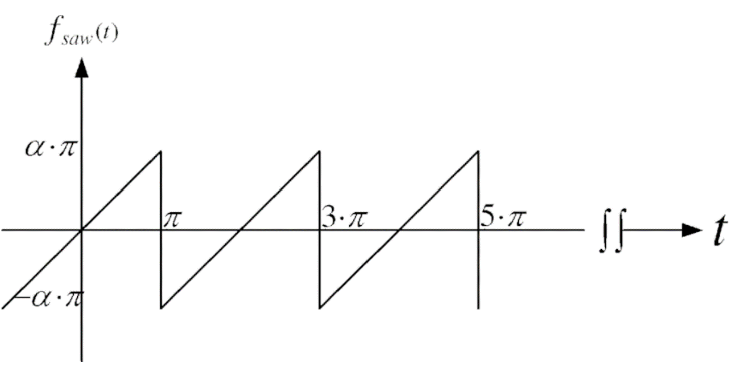
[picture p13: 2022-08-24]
Screenshot 2022-08-23 142335.gif

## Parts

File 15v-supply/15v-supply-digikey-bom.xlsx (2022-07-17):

Index | Manufacturer Part Number | Manufacturer Name | Description | Attrition % | Requested Quantity 1 | Pack Quantity 1 | Pack Type 1 | Digi-Key Part Number 1 | Unit Price 1 | Extended Price 1 | Minimum Order Quantity 1 | Customer Reference
1 | 167K30 | Hammond Manufacturing | PWR XFMR LAMINATED 45VA CHAS MT |  | 1 | 1 | Bulk | HM4466-ND | 43.62000 | $43.62 | 1 | T901
2 | UVR1H682MRD6 | Nichicon | CAP ALUM 6800UF 20% 50V RADIAL |  | 4 | 4 | Bulk | 493-1118-ND | 4.35000 | $17.40 | 1 | C902, C903, C910, C911
3 | 1N5060TR | Vishay General Semiconductor - Diodes Division | DIODE AVALANCHE 400V 2A SOD57 |  | 4 | 4 | Cut Tape (CT) | 1N5060CT-ND | 0.64000 | $2.56 | 1 | D901, D902, D903, D904
4 | 0ADKC0500-BE | Bel Fuse Inc. | FUSE CERAMIC 0.5A 600VAC/500VDC |  | 1 | 1 | Bulk | 507-2106-ND | 1.93000 | $1.93 | 1 | F901
5 | QYX1H103JTP3TA | Nichicon | CAP FILM 10000PF 5% 50VDC RADIAL |  | 4 | 4 | Cut Tape (CT) | 493-14708-1-ND | 0.44000 | $1.76 | 1 | C906, C907, C908, C909
6 | CFR-50JT-52-2K2 | YAGEO | RES 2.2K OHM 5% 1/2W AXIAL |  | 2 | 2 | Cut Tape (CT) | 13-CFR-50JT-52-2K2CT-ND | 0.11000 | $0.22 | 1 | R901, R902
7 | MC7915BTG | onsemi | IC REG LINEAR -15V 1A TO220AB |  | 1 | 1 | Tube | MC7915BTGOS-ND | 0.85000 | $0.85 | 1 | U902
8 | 691103110003 | Würth Elektronik | TERM BLK 3POS SIDE ENT 3.5MM PCB |  | 2 | 2 | Box | 732-2746-ND | 1.17000 | $2.34 | 1 | J901, J902
9 | IEC-A-1 | Adam Tech | RECEPTACLE, INLET POWER OUTLET |  | 1 | 1 | Tray | 2057-IEC-A-1-ND | 1.19000 | $1.19 | 1 | P901
10 | 0031.5001 | SCHURTER Inc. | FUSE BLOCK CART 600V 10A CHASSIS |  | 1 | 1 | Bulk | 486-1988-ND | 1.96000 | $1.96 | 1 | F901
11 | V5629G | Assmann WSW Components | HEATSINK ALUM ANOD |  | 2 | 2 | Bulk | AE10822-ND | 0.69000 | $1.38 | 1 | U901, U902
12 | 199D685X9035DYV1E3 | Vishay Sprague | CAP TANT 6.8UF 10% 35V RADIAL |  | 2 | 2 | Bulk | 199D685X9035DYV1E3-ND | 2.23000 | $4.46 | 1 | C904, C905
13 | LM7815CT/NOPB | Texas Instruments | IC REG LINEAR 15V 1A TO220-3 |  | 1 | 1 | Tube | 296-44418-5-ND | 1.97000 | $1.97 | 1 | U901
14 | FK20X7R2E224K | TDK Corporation | CAP CER 0.22UF 250V X7R RADIAL |  | 1 | 1 | Bulk | 445-FK20X7R2E224K-ND | 0.70000 | $0.70 | 1 | C901
15 | LM7915CT/NOPB | Texas Instruments | IC REG LINEAR -15V 1.5A TO220-3 |  | 1 | 1 | Tube | LM7915CT/NOPB-ND | 1.64000 | $1.64 | 1 | U902
16 | 471NS03268540 | Würth Elektronik | WS-RSTV ROCKER SWITCH ILLUMINATE |  | 1 | 1 | Tray | 732-471NS03268540-ND | 4.75000 | $4.75 | 1 | SW901
17 | 4708 | Keystone Electronics | HEX NUT 0.217" STEEL M3 |  | 2 | 2 | Bulk | 36-4708-ND | 0.18000 | $0.36 | 1
18 | MPMS 003 0020 PH | B&F Fastener Supply | MACH SCREW PAN HEAD PHILLIPS M3 |  | 100 | 100 | Bulk | H745-ND | 0.12590 | $12.59 | 100

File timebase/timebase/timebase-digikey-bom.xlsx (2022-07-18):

Index | Manufacturer Part Number | Manufacturer Name | Description | Attrition % | Requested Quantity 1 | Pack Quantity 1 | Pack Type 1 | Digi-Key Part Number 1 | Unit Price 1 | Extended Price 1 | Minimum Order Quantity 1 | Customer Reference
1 | CK06BX105K | KEMET | CAP CER 1UF 50V BX RADIAL |  | 1 | 1 | Bag | 1001-2031-ND | 4.91000 | $4.91 | 1 | C401
2 | LM358P | Texas Instruments | IC OPAMP GP 2 CIRCUIT 8DIP |  | 3 | 3 | Tube | 296-1395-5-ND | 0.49000 | $1.47 | 1 | U401, 402, 403
3 | 1N4735A | onsemi | DIODE ZENER 6.2V 1W DO41 |  | 2 | 2 | Bulk | 1N4735AFS-ND | 0.30000 | $0.60 | 1 | D403, 406
4 | CFR-25JT-52-390R | YAGEO | RES 390 OHM 5% 1/4W AXIAL |  | 1 | 1 | Cut Tape (CT) | 13-CFR-25JT-52-390RCT-ND | 0.10000 | $0.10 | 1 | R416
5 | CFR-25JB-52-12K | YAGEO | RES 12K OHM 5% 1/4W AXIAL |  | 1 | 1 | Bulk | 12KQBK-ND | 0.10000 | $0.10 | 1 | R411
6 | CFR-25JB-52-15K | YAGEO | RES 15K OHM 5% 1/4W AXIAL |  | 3 | 3 | Bulk | 15KQBK-ND | 0.10000 | $0.30 | 1 | R412, 415, 426
7 | CFR-25JB-52-22R | YAGEO | RES 22 OHM 5% 1/4W AXIAL |  | 2 | 2 | Bulk | 22QBK-ND | 0.10000 | $0.20 | 1 | R427, R428
8 | 3296W-1-502RLF | Bourns Inc. | TRIMMER 5K OHM 0.5W PC PIN TOP |  | 2 | 2 | Cut Tape (CT) | 3296W-1-502RLFCT-ND | 3.78000 | $7.56 | 1 | R420, 424
9 | CFR-25JB-52-56K | YAGEO | RES 56K OHM 5% 1/4W AXIAL |  | 1 | 1 | Bulk | 56KQBK-ND | 0.10000 | $0.10 | 1 | R401
10 | CFR-25JB-52-240K | YAGEO | RES 240K OHM 5% 1/4W AXIAL |  | 25 | 25 | Bulk | 240KQBK-ND | 0.04680 | $1.17 | 1 | R422
11 | 691137710002 | Würth Elektronik | TERM BLK 2POS SIDE ENTRY 5MM PCB |  | 2 | 2 | Box | 732-10955-ND | 0.41000 | $0.82 | 1 | J402, J404
12 | 226CKH050M | Cornell Dubilier / Illinois Capacitor | CAP ALUM 22UF 20% 50V RADIAL |  | 1 | 1 | Bulk | 1572-1383-ND | 0.26000 | $0.26 | 1 | C402, 403
13 | 107CKE025MEM | Cornell Dubilier / Illinois Capacitor | CAP ALUM 100UF 20% 25V RADIAL |  | 1 | 1 | Bulk | 1572-1039-ND | 0.38000 | $0.38 | 1 | C404, 405, 406
14 | 1N4148 | SMC Diode Solutions | DIODE GEN PURP 75V 300MA DO35 |  | 1 | 1 | Cut Tape (CT) | 1655-1N4148CT-ND | 0.13000 | $0.13 | 1 | D401, 402, 404, 405, 408
15 | 0733910060 | Molex | CONN SMA RCPT STR 50 OHM PCB |  | 2 | 2 | Tray | WM5543-ND | 3.88000 | $7.76 | 1 | J402, 404
16 | 502-0308 | NTE Electronics, Inc | POT 10K OHM 1/5W LINEAR |  | 3 | 3 | Bag | 2368-502-0308-ND | 1.44000 | $4.32 | 1 | R3, R4, R6
17 | 502-0305 | NTE Electronics, Inc | POT 5K OHM 1/5W LINEAR |  | 1 | 1 | Bag | 2368-502-0305-ND | 1.08000 | $1.08 | 1 | R5
18 | CFR-25JT-52-680K | YAGEO | RES 680K OHM 5% 1/4W AXIAL |  | 1 | 1 | Cut Tape (CT) | 13-CFR-25JT-52-680KCT-ND | 0.10000 | $0.10 | 1 | R402
19 | CFR-25JB-52-100R | YAGEO | RES 100 OHM 5% 1/4W AXIAL |  | 2 | 2 | Bulk | 100QBK-ND | 0.10000 | $0.20 | 1 | R403, 404
20 | CFR-25JB-52-2K2 | YAGEO | RES 2.2K OHM 5% 1/4W AXIAL |  | 4 | 4 | Bulk | 2.2KQBK-ND | 0.10000 | $0.40 | 1 | R405, 406, 409, 410
21 | CFR-25JB-52-4K7 | YAGEO | RES 4.7K OHM 5% 1/4W AXIAL |  | 1 | 1 | Bulk | 4.7KQBK-ND | 0.10000 | $0.10 | 1 | R407
22 | CFR-25JB-52-1K | YAGEO | RES 1K OHM 5% 1/4W AXIAL |  | 1 | 1 | Bulk | 1.0KQBK-ND | 0.10000 | $0.10 | 1 | R408
23 | CFR-25JB-52-10K | YAGEO | RES 10K OHM 5% 1/4W AXIAL |  | 6 | 6 | Bulk | 10KQBK-ND | 0.10000 | $0.60 | 1 | R413, 414, 418, 419, 423, 425
24 | CFR-25JB-52-51R | YAGEO | RES 51 OHM 5% 1/4W AXIAL |  | 1 | 1 | Bulk | 51QBK-ND | 0.10000 | $0.10 | 1 | R417
25 | CFR-25JB-52-6K8 | YAGEO | RES 6.8K OHM 5% 1/4W AXIAL |  | 1 | 1 | Bulk | 6.8KQBK-ND | 0.10000 | $0.10 | 1 | R421
26 | CFR-25JB-52-470R | YAGEO | RES 470 OHM 5% 1/4W AXIAL |  | 1 | 1 | Bulk | 470QBK-ND | 0.10000 | $0.10 | 1 | R429

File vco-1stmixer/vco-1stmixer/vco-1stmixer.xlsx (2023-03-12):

Index | Manufacturer Part Number | Manufacturer Name | Description | Attrition % | Requested Quantity 1 | Pack Quantity 1 | Pack Type 1 | Digi-Key Part Number 1 | Unit Price 1 | Extended Price 1 | Minimum Order Quantity 1 | Customer Reference
1 | 0022284028 | Molex | CONN HEADER VERT 2POS 2.54MM |  | 1 | 1 | Bulk | 900-0022284028-ND | 0.29000 | $0.29 | 1 | JP105
2 | DSS1NB32A102Q91A | Murata Electronics | FILTER LC(T) 1000PF TH |  | 6 | 6 | Cut Tape (CT) | 490-9795-1-ND | 0.28000 | $1.68 | 1 | C104, C105, C106, C108, C109, C110,
3 | 691137710002 | Würth Elektronik | TERM BLK 2POS SIDE ENTRY 5MM PCB |  | 1 | 1 | Box | 732-10955-ND | 0.41000 | $0.41 | 1 | J105
4 | C315C103K5R5TA | KEMET | CAP CER 10000PF 50V X7R RADIAL |  | 2 | 2 | Bulk | 399-4148-ND | 0.24000 | $0.48 | 1 | C101, C107,
5 | C315C104M5U5TA7301 | KEMET | CAP CER 0.1UF 50V Z5U RADIAL |  | 1 | 1 | Cut Tape (CT) | 399-14010-1-ND | 0.22000 | $0.22 | 1 | C102,
6 | CFR-25JB-52-150R | YAGEO | RES 150 OHM 5% 1/4W AXIAL |  | 5 | 5 | Bulk | 150QBK-ND | 0.10000 | $0.50 | 1 | R101, R102, R104, R106, R110,
7 | CFR-25JB-52-36R | YAGEO | RES 36 OHM 5% 1/4W AXIAL |  | 2 | 2 | Bulk | 36QBK-ND | 0.10000 | $0.20 | 1 | R103, R108,
8 | CFR-25JB-52-220R | YAGEO | RES 220 OHM 5% 1/4W AXIAL |  | 4 | 4 | Bulk | 220QBK-ND | 0.10000 | $0.40 | 1 | R107, R109, R114, R116,
9 | CFR-25JB-52-47R | YAGEO | RES 47 OHM 5% 1/4W AXIAL |  | 1 | 1 | Bulk | 47QBK-ND | 0.10000 | $0.10 | 1 | R113,
10 | CFR-25JB-52-1K5 | YAGEO | RES 1.5K OHM 5% 1/4W AXIAL |  | 1 | 1 | Bulk | 1.5KQBK-ND | 0.10000 | $0.10 | 1 | R105,
11 | CFR-25JB-52-33R | YAGEO | RES 33 OHM 5% 1/4W AXIAL |  | 1 | 1 | Bulk | 33QBK-ND | 0.10000 | $0.10 | 1 | R111,
12 | CFR-25JB-52-22R | YAGEO | RES 22 OHM 5% 1/4W AXIAL |  | 1 | 1 | Bulk | 22QBK-ND | 0.10000 | $0.10 | 1 | R112,
13 | CFR-25JB-52-470R | YAGEO | RES 470 OHM 5% 1/4W AXIAL |  | 1 | 1 | Bulk | 470QBK-ND | 0.10000 | $0.10 | 1 | R115,

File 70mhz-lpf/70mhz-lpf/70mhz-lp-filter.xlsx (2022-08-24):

Index | Manufacturer Part Number | Manufacturer Name | Description | Attrition % | Requested Quantity 1 | Pack Quantity 1 | Pack Type 1 | Digi-Key Part Number 1 | Unit Price 1 | Extended Price 1 | Minimum Order Quantity 1 | Customer Reference
1 | LQW18ANR15J00D | Murata Electronics | FIXED IND 150NH 160MA 1.5OHM SMD |  | 2 | 2 | Cut Tape (CT) | 490-6924-1-ND | 0.16000 | $0.32 | 1 | L701, L704
2 | LQW18ANR18J00D | Murata Electronics | FIXED IND 180NH 140MA 2.2OHM SMD |  | 2 | 2 | Cut Tape (CT) | 490-6928-1-ND | 0.16000 | $0.32 | 1 | L702, L703
3 | 500X14N470MV4T | Johanson Dielectrics Inc. | CAP CER 47PF 50V C0G/NP0 0603 |  | 2 | 2 | Cut Tape (CT) | 709-1003-1-ND | 0.36000 | $0.72 | 1 | C701, C705
4 | 0603N820J500CT | Walsin Technology Corporation | CAP CER 82PF 50V C0G/NP0 0603 |  | 2 | 2 | Cut Tape (CT) | 1292-1547-1-ND | 0.10000 | $0.20 | 1 | C702, C703

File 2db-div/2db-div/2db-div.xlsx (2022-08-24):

Index | Manufacturer Part Number | Manufacturer Name | Description | Attrition % | Requested Quantity 1 | Pack Quantity 1 | Pack Type 1 | Digi-Key Part Number 1 | Unit Price 1 | Extended Price 1 | Minimum Order Quantity 1 | Customer Reference
1 | 3362P-1-103LF | Bourns Inc. | TRIMMER 10K OHM 0.5W PC PIN TOP |  | 2 | 2 | Tube | 3362P-103LF-ND | 1.03000 | $2.06 | 1 | R1006, R012
2 | 691137710002 | Würth Elektronik | TERM BLK 2POS SIDE ENTRY 5MM PCB |  | 2 | 2 | Box | 732-10955-ND | 0.41000 | $0.82 | 1 | J1001, J1003
3 | MC1458P | Texas Instruments | IC OPAMP GP 2 CIRCUIT 8DIP |  | 1 | 1 | Tube | 296-1403-5-ND | 0.60000 | $0.60 | 1 | U1001
4 | 35ZLH100MEFC6.3X11 | Rubycon | CAP ALUM 100UF 20% 35V RADIAL |  | 1 | 1 | Bulk | 1189-1300-ND | 0.38000 | $0.38 | 1 | C1001, C1002
5 | 1N4148TA | onsemi | DIODE GEN PURP 100V 200MA DO35 |  | 1 | 1 | Cut Tape (CT) | 1N4148TACT-ND | 0.10000 | $0.10 | 1 | D1001
6 | C320C104K5R5TA | KEMET | CAP CER 0.1UF 50V X7R RADIAL |  | 1 | 1 | Bulk | 399-4264-ND | 0.23000 | $0.23 | 1 | C1003
7 | FG26X7S2A335KRT00 | TDK Corporation | CAP CER 3.3UF 100V X7S RADIAL |  | 1 | 1 | Bulk | 445-FG26X7S2A335KRT00-ND | 0.86000 | $0.86 | 1 | C1004
8 | ANT11SECQE | CIT Relay and Switch | SWITCH TOGGLE SPDT PC MNT SEAL |  | 1 | 1 | Bulk | 2449-ANT11SECQE-ND | 1.69000 | $1.69 | 1 | SW1
9 | ANT13SECQE | CIT Relay and Switch | SWITCH TOGGLE SPDT, ON-OFF-ON FU |  | 1 | 1 | Bulk | 2449-ANT13SECQE-ND | 1.81000 | $1.81 | 1 | SW2
10 | CFR-25JB-52-43R | YAGEO | RES 43 OHM 5% 1/4W AXIAL |  | 2 | 2 | Bulk | 43QBK-ND | 0.10000 | $0.20 | 1 | R1001, R1002
11 | CFR-25JT-52-20K | YAGEO | RES 20K OHM 5% 1/4W AXIAL |  | 4 | 4 | Cut Tape (CT) | 13-CFR-25JT-52-20KCT-ND | 0.10000 | $0.40 | 1 | R1003, R1004, R1008, R1009
12 | CFR-25JB-52-10K | YAGEO | RES 10K OHM 5% 1/4W AXIAL |  | 1 | 1 | Bulk | 10KQBK-ND | 0.10000 | $0.10 | 1 | R1007
13 | MFR-25FBF52-249K | YAGEO | RES 249K OHM 1% 1/4W AXIAL |  | 1 | 1 | Bulk | 249KXBK-ND | 0.10000 | $0.10 | 1 | R1010
14 | MFR-25FBF52-4K99 | YAGEO | RES 4.99K OHM 1% 1/4W AXIAL |  | 1 | 1 | Bulk | 4.99KXBK-ND | 0.10000 | $0.10 | 1 | R1011
15 | CFR-25JB-52-1K | YAGEO | RES 1K OHM 5% 1/4W AXIAL |  | 1 | 1 | Bulk | 1.0KQBK-ND | 0.10000 | $0.10 | 1 | R1013
16 | MFR-25FBF52-40K2 | YAGEO | RES 40.2K OHM 1% 1/4W AXIAL |  | 1 | 1 | Bulk | 40.2KXBK-ND | 0.10000 | $0.10 | 1 | R1005

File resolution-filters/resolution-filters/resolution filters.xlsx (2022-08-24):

Index | Manufacturer Part Number | Manufacturer Name | Description | Attrition % | Requested Quantity 1 | Pack Quantity 1 | Pack Type 1 | Digi-Key Part Number 1 | Unit Price 1 | Extended Price 1 | Minimum Order Quantity 1 | Customer Reference
1 | 691137710002 | Würth Elektronik | TERM BLK 2POS SIDE ENTRY 5MM PCB |  | 1 | 1 | Box | 732-10955-ND | 0.41000 | $0.41 | 1 | J502
2 | GKG10015 | EW Electronics | CAP TRIMMER 3-10PF 100V TH |  | 6 | 6 | Bulk | 2447-GKG10015-ND | 0.92000 | $5.52 | 1 | C505, C508, C511, C513, C516, C518
3 | GKG60015 | EW Electronics | CAP TRIMMER 12-60PF 100V TH |  | 4 | 4 | Bulk | 2447-GKG60015-ND | 0.92000 | $3.68 | 1 | C504, C510, C515, C520
4 | ECS-10.7-7.5B | ECS Inc. | MONO XTAL 10.7MHZ 4P 2PC 2.5DB |  | 2 | 2 | Bulk | X702-ND | 10.09000 | $20.18 | 1 | Y501, 502, 503, 504
5 | DSS1NB32A472Q91A | Murata Electronics | FILTER LC(T) 4700PF TH |  | 1 | 1 | Cut Tape (CT) | 490-9799-1-ND | 0.28000 | $0.28 | 1 | C503
6 | FG28C0G1H3R3CNT06 | TDK Corporation | CAP CER 3.3PF 50V C0G RADIAL |  | 1 | 1 | Cut Tape (CT) | 445-173498-1-ND | 0.28000 | $0.28 | 1 | C514
7 | K181J15C0GF5TL2 | Vishay Beyschlag/Draloric/BC Components | CAP CER 180PF 50V C0G/NP0 RADIAL |  | 1 | 1 | Cut Tape (CT) | BC1016CT-ND | 0.27000 | $0.27 | 1 | C512, C517
8 | C317C569D5G5TA | KEMET | CAP CER 5.6PF 50V C0G/NP0 RADIAL |  | 2 | 2 | Bulk | 399-C317C569D5G5TA-ND | 0.54000 | $1.08 | 1 | C509, C519
9 | K104K15X7RF5TL2 | Vishay Beyschlag/Draloric/BC Components | CAP CER 0.1UF 50V X7R RADIAL |  | 2 | 2 | Cut Tape (CT) | BC1084CT-ND | 0.24000 | $0.48 | 1 | C506, C521
10 | K121J15C0GF5TL2 | Vishay Beyschlag/Draloric/BC Components | CAP CER 120PF 50V C0G/NP0 RADIAL |  | 1 | 1 | Cut Tape (CT) | BC1014CT-ND | 0.27000 | $0.27 | 1 | C502, C507, C522, C524
11 | K560J15C0GF5TL2 | Vishay Beyschlag/Draloric/BC Components | CAP CER 56PF 50V C0G/NP0 RADIAL |  | 2 | 2 | Cut Tape (CT) | BC1010CT-ND | 0.28000 | $0.56 | 1 | C501, C523
12 | G5V-1-2 DC12 | Omron Electronics Inc-EMC Div | RELAY GEN PURPOSE SPDT 1A 12VDC |  | 2 | 2 | Tube | Z3823-ND | 2.95000 | $5.90 | 1 | K501, K502
13 | CFR-25JB-52-150R | YAGEO | RES 150 OHM 5% 1/4W AXIAL |  | 2 | 2 | Bulk | 150QBK-ND | 0.10000 | $0.20 | 1 | R501, R503
14 | CFR-25JB-52-270R | YAGEO | RES 270 OHM 5% 1/4W AXIAL |  | 2 | 2 | Bulk | 270QBK-ND | 0.10000 | $0.20 | 1 | R504, R508
15 | CFR-25JB-52-2K2 | YAGEO | RES 2.2K OHM 5% 1/4W AXIAL |  | 1 | 1 | Bulk | 2.2KQBK-ND | 0.10000 | $0.10 | 1 | R506
16 | CFR-25JB-52-9K1 | YAGEO | RES 9.1K OHM 5% 1/4W AXIAL |  | 2 | 2 | Bulk | 9.1KQBK-ND | 0.10000 | $0.20 | 1 | R505, R507
17 | CFR-25JB-52-36R | YAGEO | RES 36 OHM 5% 1/4W AXIAL |  | 1 | 1 | Bulk | 36QBK-ND | 0.10000 | $0.10 | 1 | R502
18 | M2011S3A1W03 | NKK Switches | SWITCH TOGGLE SPST 6A 125V |  | 1 | 1 | Bulk | M2011S3A1W03-ND | 3.76000 | $3.76 | 1 | SW501
19 | 22SNSP.125 | Remington Industries | 22SNSP.125 MAGNET WIRE, ENAMELED |  | 1 | 1 | Bag | 2328-22SNSP.125-ND | 11.16000 | $11.16 | 1
20 | 30SNSP.125 | Remington Industries | 30SNSP.125 MAGNET WIRE, ENAMELED |  | 1 | 1 | Bag | 2328-30SNSP.125-ND | 11.26000 | $11.26 | 1
21 | 1N4148 | onsemi | DIODE GEN PURP 100V 200MA DO35 |  | 2 | 2 | Bulk | 1N4148FS-ND | 0.10000 | $0.20 | 1 | D501, D502
22 | ZOR-25-B-52-0R | YAGEO | RES 0 OHM JUMPER 1/4W AXIAL |  | 1 | 1 | Bulk | 0.0QBK-ND | 0.15000 | $0.15 | 1 | R510
23 | CFR-25JB-52-10M | YAGEO | RES 10M OHM 5% 1/4W AXIAL |  | 2 | 2 | Bulk | 10MQBK-ND | 0.10000 | $0.20 | 1 | R509, R511

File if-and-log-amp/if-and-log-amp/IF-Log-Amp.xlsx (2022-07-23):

Index | Manufacturer Part Number | Manufacturer Name | Description | Attrition % | Requested Quantity 1 | Pack Quantity 1 | Pack Type 1 | Digi-Key Part Number 1 | Unit Price 1 | Extended Price 1 | Minimum Order Quantity 1 | Customer Reference
1 | CA3140EZ | Renesas Electronics America Inc | IC OPAMP GP 1 CIRCUIT 8DIP |  | 1 | 1 | Tube | CA3140EZ-ND | 3.46000 | $3.46 | 1 | U305
2 | AD8307ANZ | Analog Devices Inc. | IC LOGARITHMIC AMPLIFIER 8DIP |  | 1 | 1 | Tube | AD8307ANZ-ND | 15.12000 | $15.12 | 1 | U304
3 | L78L05ACZTR | STMicroelectronics | IC REG LINEAR 5V 100MA TO92-3 |  | 1 | 1 | Cut Tape (CT) | 497-1184-1-ND | 0.52000 | $0.52 | 1 | U302
4 | 3386G-1-101LF | Bourns Inc. | TRIMMER 100 OHM 0.5W PC PIN TOP |  | 1 | 1 | Tube | 3386G-1-101LF-ND | 1.73000 | $1.73 | 1 | RV302
5 | GKG60015 | EW Electronics | CAP TRIMMER 12-60PF 100V TH |  | 10 | 10 | Bulk | 2447-GKG60015-ND | 0.80400 | $8.04 | 1 | C315
6 | 0733910060 | Molex | CONN SMA RCPT STR 50 OHM PCB |  | 2 | 2 | Tray | WM5543-ND | 3.88000 | $7.76 | 1 | J301, 306
7 | LM317LBZRPG | onsemi | IC REG LINEAR POS ADJ 100MA TO92 |  | 1 | 1 | Cut Tape (CT) | LM317LBZRPGOSCT-ND | 0.67000 | $0.67 | 1 | U303
8 | C317C569D5G5TA | KEMET | CAP CER 5.6PF 50V C0G/NP0 RADIAL |  | 2 | 2 | Bulk | 399-C317C569D5G5TA-ND | 0.54000 | $1.08 | 1 | C314, C317
9 | 107CKE025MEM | Cornell Dubilier / Illinois Capacitor | CAP ALUM 100UF 20% 25V RADIAL |  | 1 | 1 | Bulk | 1572-1039-ND | 0.38000 | $0.38 | 1 | C304
10 | C315C103J3G5TA | KEMET | CAP CER 10000PF 25V C0G/NP0 RAD |  | 1 | 1 | Bulk | C315C103J3G5TA-ND | 0.56000 | $0.56 | 1 | C305
11 | FK18X5R1E224K | TDK Corporation | CAP CER 0.22UF 25V X5R RADIAL |  | 1 | 1 | Bulk | 445-8411-ND | 0.37000 | $0.37 | 1 | C310
12 | 25MS722MEFC5X7 | Rubycon | CAP ALUM 22UF 20% 25V RADIAL |  | 1 | 1 | Bulk | 25MS722MEFC5X7-ND | 0.27000 | $0.27 | 1 | C313
13 | FK18C0G1H181J | TDK Corporation | CAP CER 180PF 50V C0G RADIAL |  | 1 | 1 | Bulk | 445-4774-ND | 0.32000 | $0.32 | 1 | C316
14 | C320C102K3G5TA | KEMET | CAP CER RAD 1NF 25V C0G 10% |  | 1 | 1 | Bulk | C320C102K3G5TA-ND | 0.41000 | $0.41 | 1 | C321
15 | 1N4150-1 | Microchip Technology | DIODE GEN PURP 50V 200MA DO35 |  | 1 | 1 | Bulk | 1N4150-1-ND | 0.96000 | $0.96 | 1 | D301
16 | FK24X5R1E335KR000 | TDK Corporation | CAP CER 3.3UF 25V X5R RADIAL |  | 1 | 1 | Bulk | 445-FK24X5R1E335KR000-ND | 0.54000 | $0.54 | 1 | C326
17 | C315C104M5U5TA | KEMET | CAP CER 0.1UF 50V Z5U RADIAL |  | 1 | 1 | Bulk | 399-4151-ND | 0.22000 | $0.22 | 1 | C325
18 | 502-0308 | NTE Electronics, Inc | POT 10K OHM 1/5W LINEAR |  | 1 | 1 | Bag | 2368-502-0308-ND | 1.44000 | $1.44 | 1 | RV301, 303
19 | FG18C0G1H180JNT00 | TDK Corporation | CAP CER 18PF 50V C0G RADIAL |  | 1 | 1 | Bulk | 445-181734-ND | 0.28000 | $0.28 | 1 | C311
20 | C315C104M5U5TA | KEMET | CAP CER 0.1UF 50V Z5U RADIAL |  | 1 | 1 | Bulk | 399-4151-ND | 0.22000 | $0.22 | 1 | > C306-C309, C312, C318-C320, C322
21 | CFR-25JB-52-100R | YAGEO | RES 100 OHM 5% 1/4W AXIAL |  | 1 | 1 | Bulk | 100QBK-ND | 0.10000 | $0.10 | 1 | R303
22 | CFR-25JB-52-680R | YAGEO | RES 680 OHM 5% 1/4W AXIAL |  | 1 | 1 | Bulk | 680QBK-ND | 0.10000 | $0.10 | 1 | R304, 318
23 | CFR-25JB-52-510R | YAGEO | RES 510 OHM 5% 1/4W AXIAL |  | 1 | 1 | Bulk | 510QBK-ND | 0.10000 | $0.10 | 1 | R305
24 | CFR-25JB-52-1K | YAGEO | RES 1K OHM 5% 1/4W AXIAL |  | 1 | 1 | Bulk | 1.0KQBK-ND | 0.10000 | $0.10 | 1 | R306, 313, 321
25 | RC14JT51R0 | Stackpole Electronics Inc | RES 51 OHM 5% 1/4W AXIAL |  | 1 | 1 | Cut Tape (CT) | RC14JT51R0CT-ND | 0.54000 | $0.54 | 1 | R307, 319
26 | CFR-25JB-52-2K2 | YAGEO | RES 2.2K OHM 5% 1/4W AXIAL |  | 1 | 1 | Bulk | 2.2KQBK-ND | 0.10000 | $0.10 | 1 | R301, 302, 308, 320
27 | CFR-25JB-52-4K3 | YAGEO | RES 4.3K OHM 5% 1/4W AXIAL |  | 1 | 1 | Bulk | 4.3KQBK-ND | 0.10000 | $0.10 | 1 | R309
28 | CFR-25JB-52-5K6 | YAGEO | RES 5.6K OHM 5% 1/4W AXIAL |  | 1 | 1 | Bulk | 5.6KQBK-ND | 0.10000 | $0.10 | 1 | R310
29 | CFR-25JB-52-10R | YAGEO | RES 10 OHM 5% 1/4W AXIAL |  | 1 | 1 | Bulk | 10QBK-ND | 0.10000 | $0.10 | 1 | R311, 312, 316, 317
30 | CFR-25JB-52-220R | YAGEO | RES 220 OHM 5% 1/4W AXIAL |  | 1 | 1 | Bulk | 220QBK-ND | 0.10000 | $0.10 | 1 | R314
31 | CFR-25JB-52-1K5 | YAGEO | RES 1.5K OHM 5% 1/4W AXIAL |  | 1 | 1 | Bulk | 1.5KQBK-ND | 0.10000 | $0.10 | 1 | R315

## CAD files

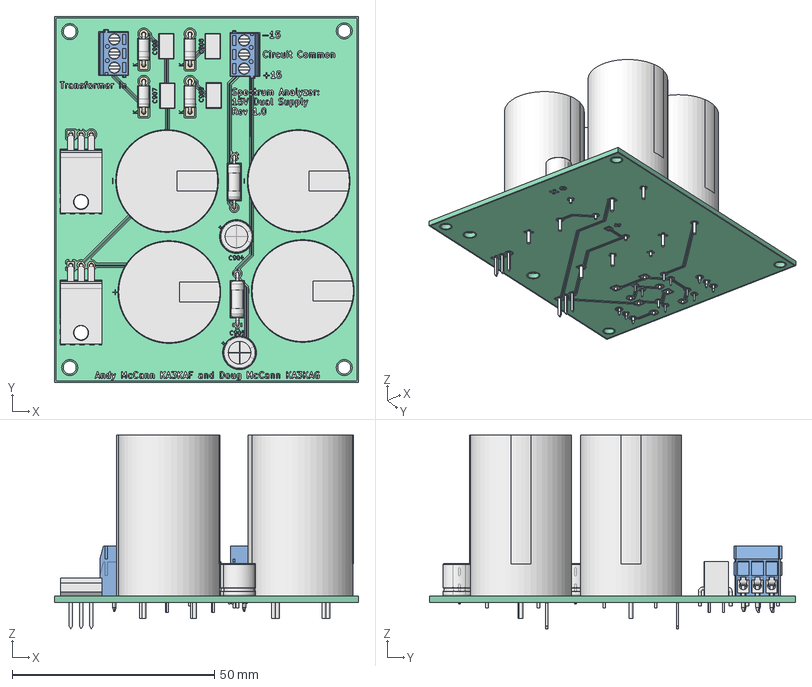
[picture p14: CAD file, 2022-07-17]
15v-supply/15v-supply-models/15v-supply-3D/15v-supply-board.FCStd
75.2 x 90.4 x 47.9 mm
Pcb_7b02
topPads_7b02
topTracks_7b02
topZones_7b02
botPads_7b02
botTracks_7b02
botZones_7b02
topSilks_5a83
D901_D_DO-41_SOD81_P7.62mm_Horizontal_0f7420698e15 x 4
R902_R_Axial_DIN0309_L90mm_D32mm_P1270mm_Horizontal_656395d6a1e4 x 2
C904_CP_Radial_D80mm_P350mm_be9362f17a2f x 2
U902_TO-220-3_Horizontal_TabUp_336c31f2f8c4 x 4

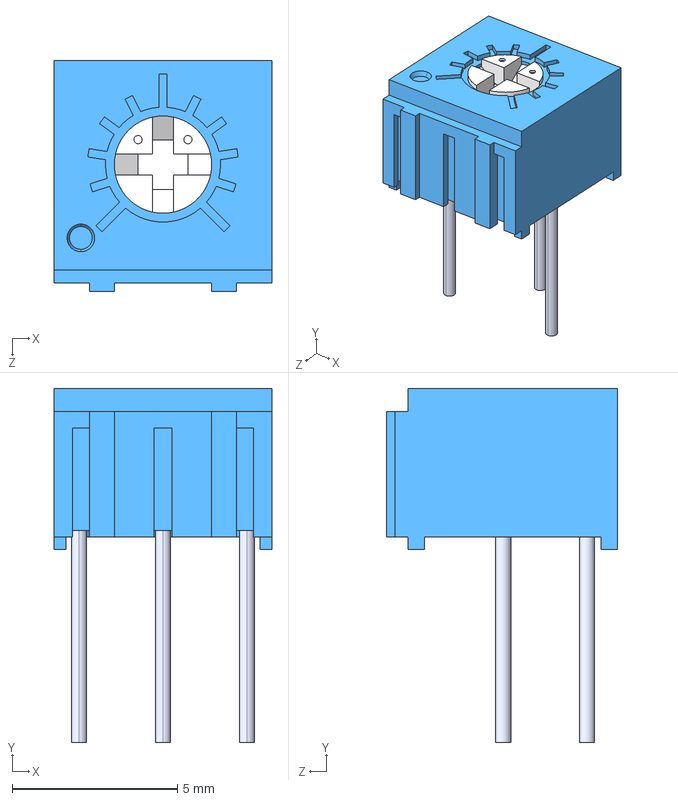
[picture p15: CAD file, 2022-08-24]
2db-div/2db-div/2db-div-models/2db-div-3D/3362P-1-103LF.step
6.60 x 10.7 x 6.99 mm

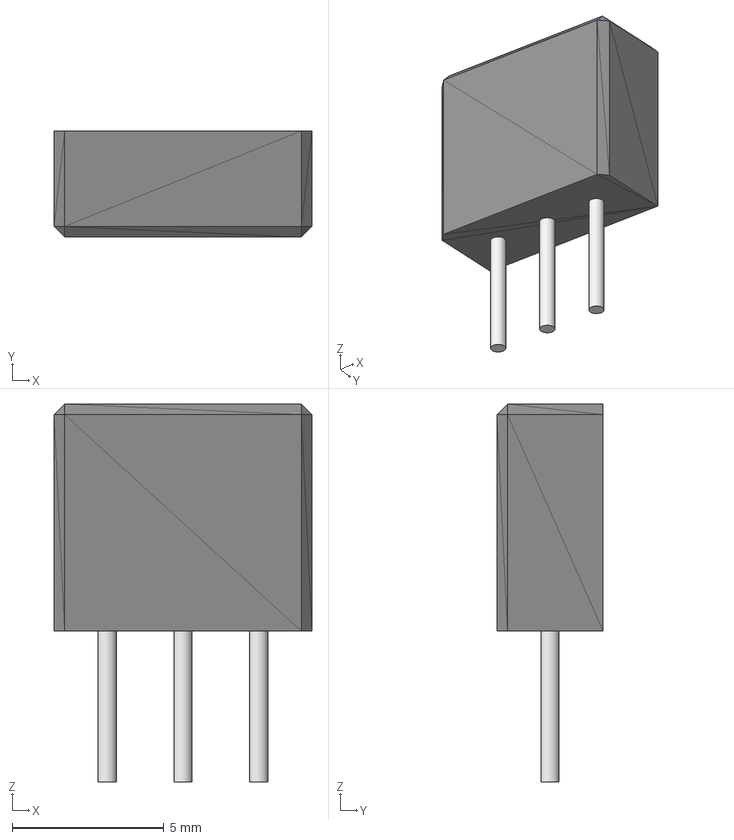
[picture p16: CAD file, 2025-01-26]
hierarchical-schematic/spectrum-analyzer-models/DSS1N_MUR.step
8.51 x 3.51 x 12.5 mm

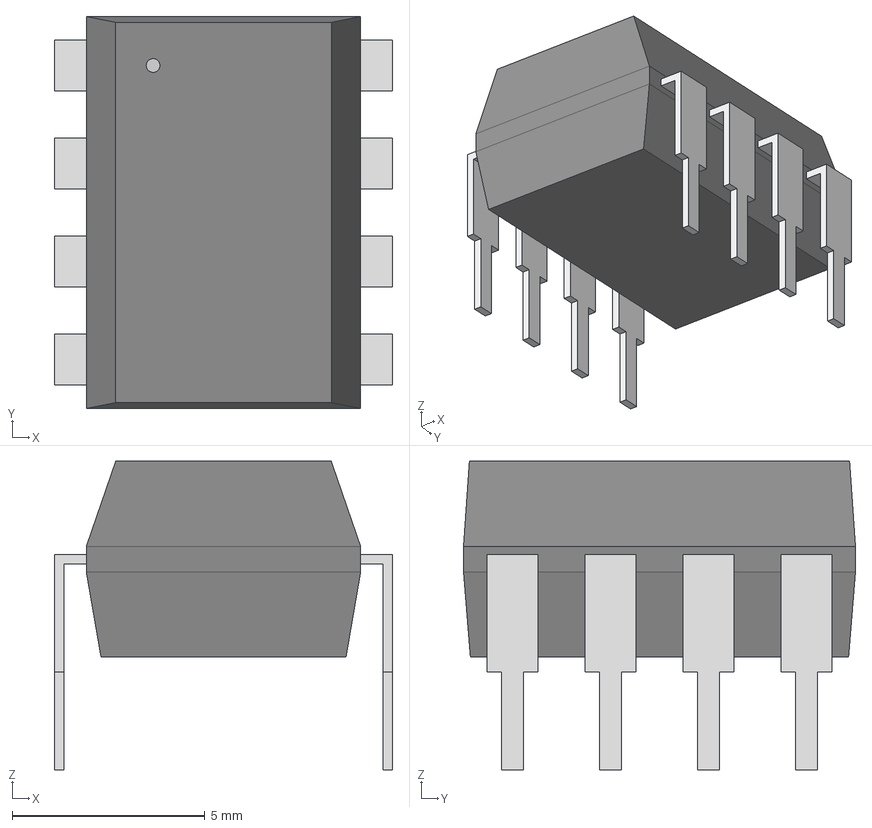
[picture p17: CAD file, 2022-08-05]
if-and-log-amp/if-and-log-amp/if-log-amp-models/if-log-amp-3D/CA3140EZ.step
8.76 x 10.2 x 8.00 mm

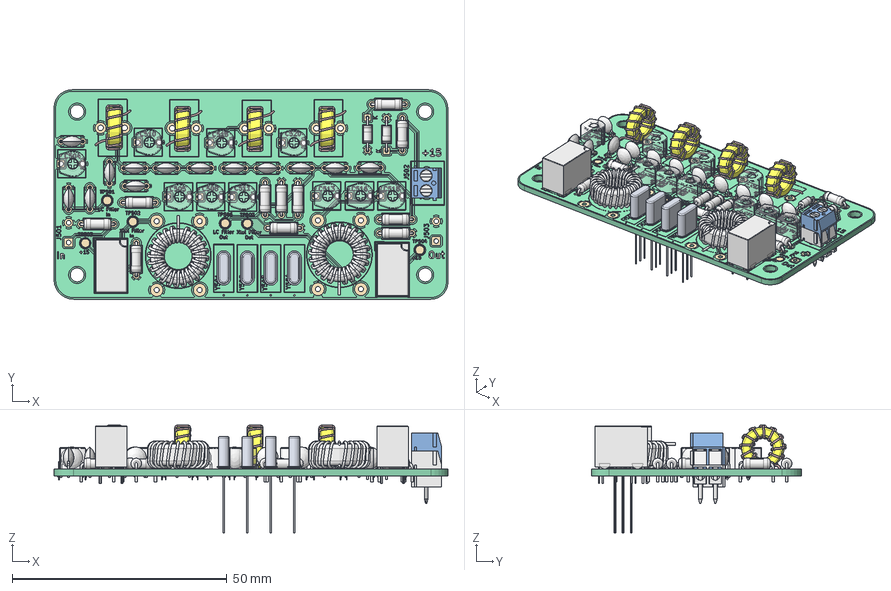
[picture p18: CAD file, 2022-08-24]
resolution-filters/resolution-filters/resolution-filters-models/resolution-filters-3D/resolution-filters.FCStd
91.7 x 48.8 x 25.1 mm
Pcb_9a4e
topPads_9a4e
topTracks_9a4e
topZones_9a4e
botPads_9a4e
botTracks_9a4e
botZones_9a4e
botSilks_1b10
topSilks_16c4
C513_Trimmer Cap - Brown_fa101f9de910 x 20
T37-6 IND x 8
T37-6 IND001 x 8
T37-6 IND002 x 8
T37-6 IND003 x 8
R509_R_Axial_DIN0207_L63mm_D25mm_P762mm_Horizontal_29629d9bf234 x 11
C506_C_Disc_D50mm_W25mm_P500mm_f2b36a464e24 x 13
UM-1 x 8
UM-002 x 8
UM-003 x 8
UM-004 x 8
UM-005 x 8
UM-006 x 8
L_Tor_13x8x5_3a_cp x 4
L_Tor_13x8x5_3a_cp001 x 4
D_DO-35_SOD27_P7.62mm_Horizontal x 2
D_DO-35_SOD27_P7.62mm_Horizontal001 x 2
K501_Relay_SPDT_Omron_G5V-1_adee48805411 x 2

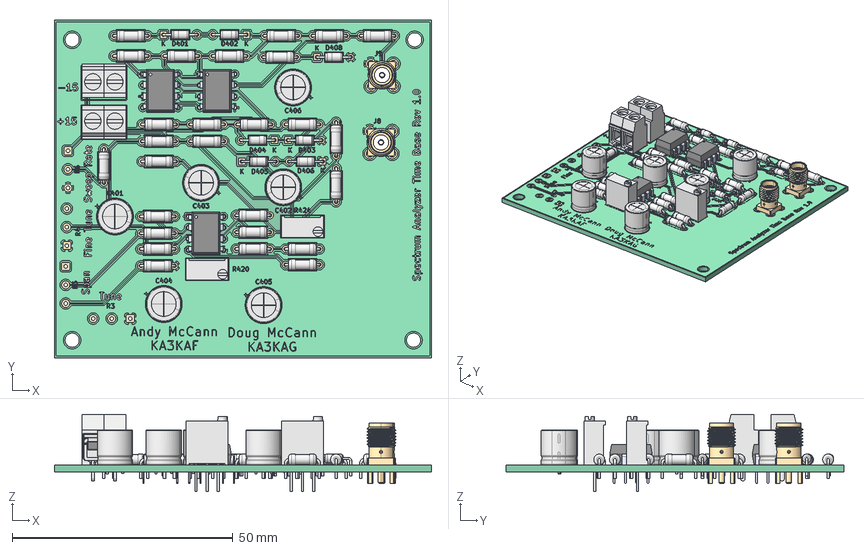
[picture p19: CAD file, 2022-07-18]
timebase/timebase/timebase-models/timebase-3D/Timebase.FCStd
85.3 x 76.5 x 17.5 mm
Pcb_758f
topPads_758f
topTracks_758f
topZones_758f
botPads_758f
botTracks_758f
botZones_758f
topSilks_611a
R426_R_Axial_DIN0207_L63mm_D25mm_P762mm_Horizontal_96b38c16849e x 27
D_DO-35_SOD27_P7.62mm_Horizontal x 7
D_DO-35_SOD27_P7.62mm_Horizontal001 x 7
C405_CP_Radial_D80mm_P350mm_98bf3544fc31 x 6
OPA347PA x 3
OPA347PA001 x 3
OPA347PA002 x 3
OPA347PA003 x 3
OPA347PA004 x 3
OPA347PA005 x 3
OPA347PA006 x 3
OPA347PA007 x 3
OPA347PA008 x 3
OPA347PA009 x 3
R424_Potentiometer_Bourns_3296W_Vertical_5014a80db3f9 x 2

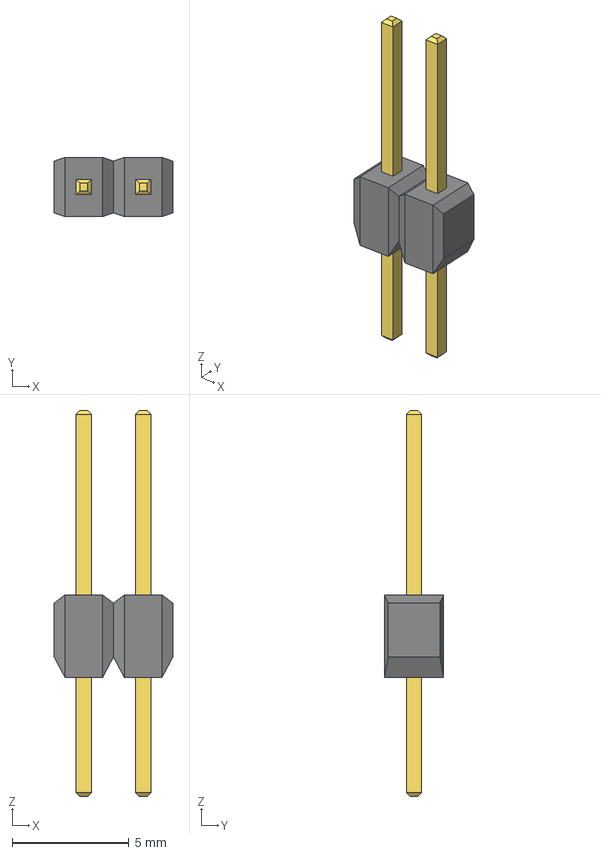
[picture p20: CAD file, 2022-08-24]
vco-1stmixer/vco-1stmixer/vco-1stmixer-models/vco-1stmixer-3D/22-28-4028_MOL.step
5.08 x 2.54 x 16.5 mm

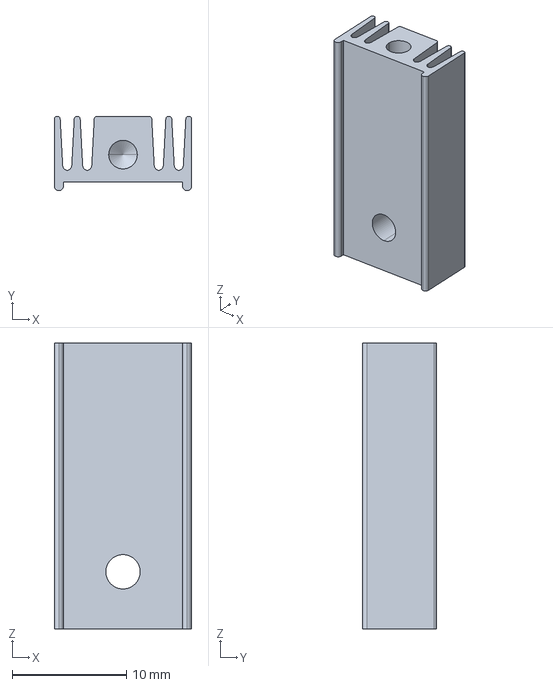
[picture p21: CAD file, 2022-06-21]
15v-supply/15v-supply-models/15v-supply-3D/v5629g.stp
12.0 x 6.50 x 25.0 mm

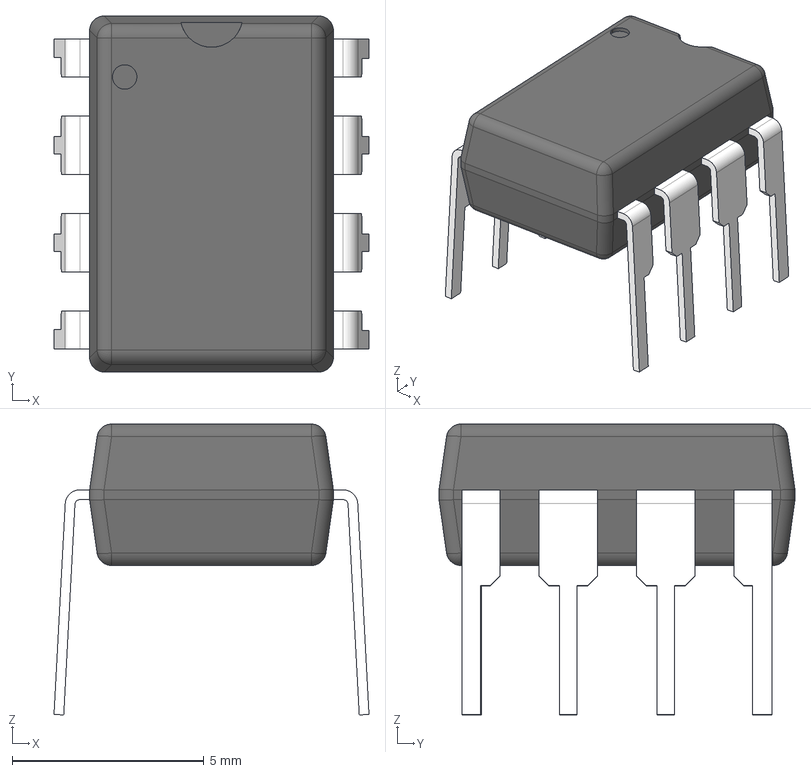
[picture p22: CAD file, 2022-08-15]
2db-div/2db-div/2db-div-models/2db-div-3D/P0008A.stp
8.20 x 9.27 x 7.58 mm
BODY_P0008A
LEAD_P0008A x 4
LD_LHALF_P0008A x 2
LD_RHALF_P0008A x 2

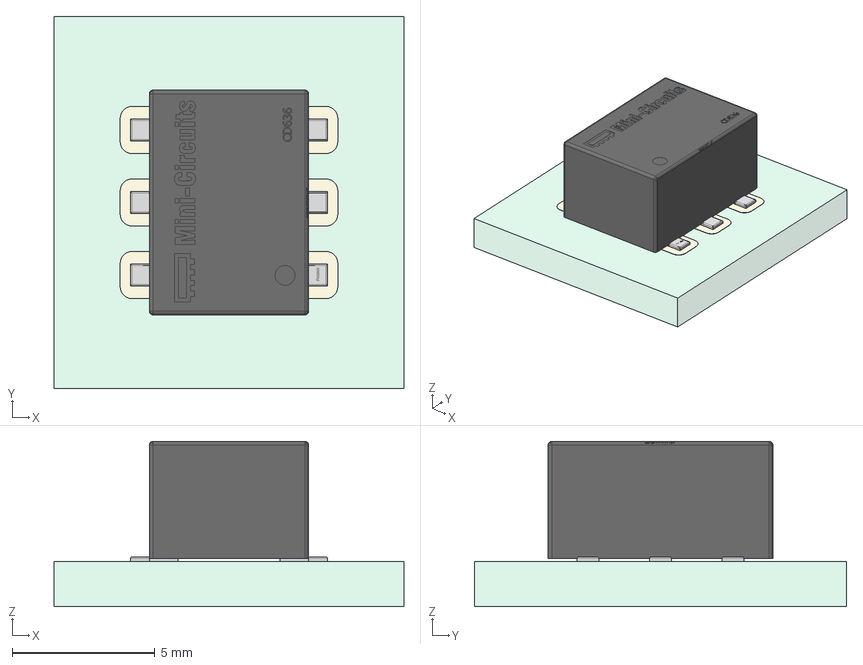
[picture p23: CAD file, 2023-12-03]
hierarchical-schematic/spectrum-analyzer-models/ADE-1H.FCStd
12.3 x 13.0 x 5.79 mm
topPads
PCB
03D4CB5E-4555-4F52-902A-12C7E0F8DAF3
03D4CB5E-4555-4F52-902A-12C7E0F8DAF004
03D4CB5E-4555-4F52-902A-12C7E0F8DAF005
03D4CB5E-4555-4F52-902A-12C7E0F8DAF006
03D4CB5E-4555-4F52-902A-12C7E0F8DAF007
03D4CB5E-4555-4F52-902A-12C7E0F8DAF008
03D4CB5E-4555-4F52-902A-12C7E0F8DAF009
03D4CB5E-4555-4F52-902A-12C7E0F8DAF010
03D4CB5E-4555-4F52-902A-12C7E0F8DAF011
03D4CB5E-4555-4F52-902A-12C7E0F8DAF012
03D4CB5E-4555-4F52-902A-12C7E0F8DAF013

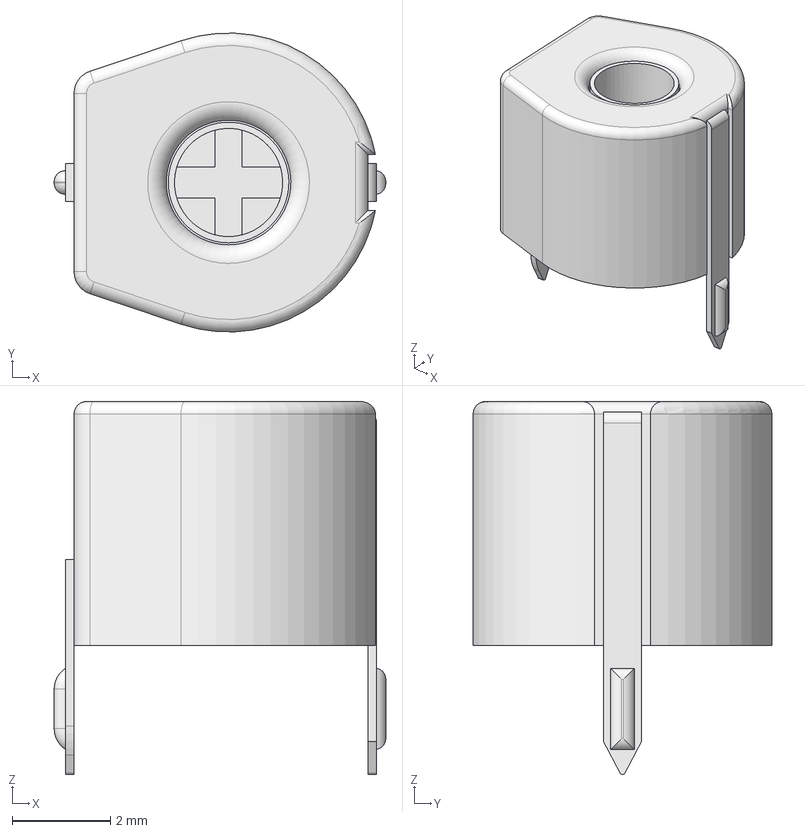
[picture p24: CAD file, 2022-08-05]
if-and-log-amp/if-and-log-amp/if-log-amp-models/if-log-amp-3D/Trimmer Cap - Brown.step
6.76 x 6.09 x 7.61 mm

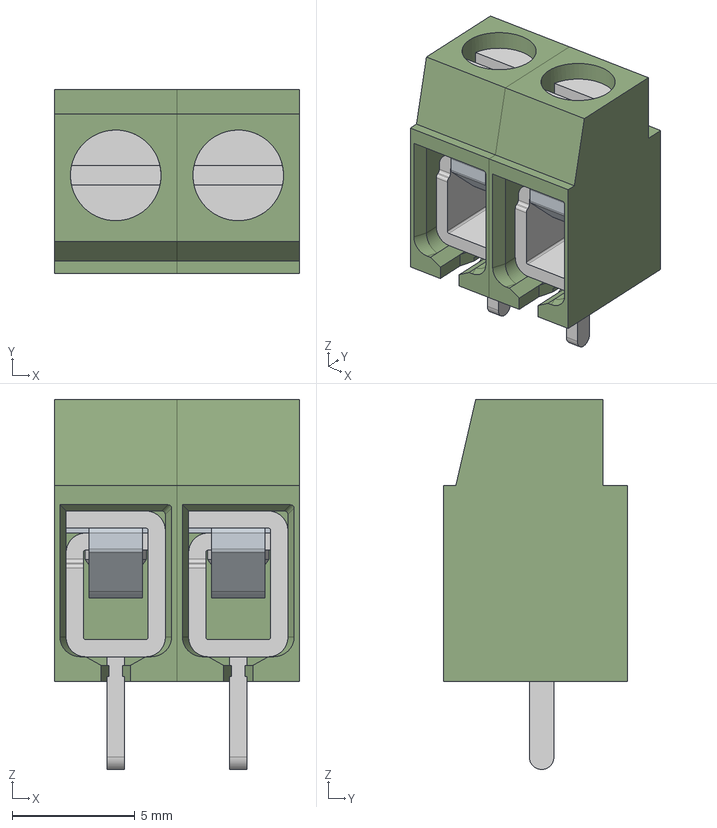
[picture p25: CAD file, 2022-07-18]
timebase/timebase/timebase-models/timebase-3D/terminal-block.step
10.00 x 7.50 x 15.1 mm

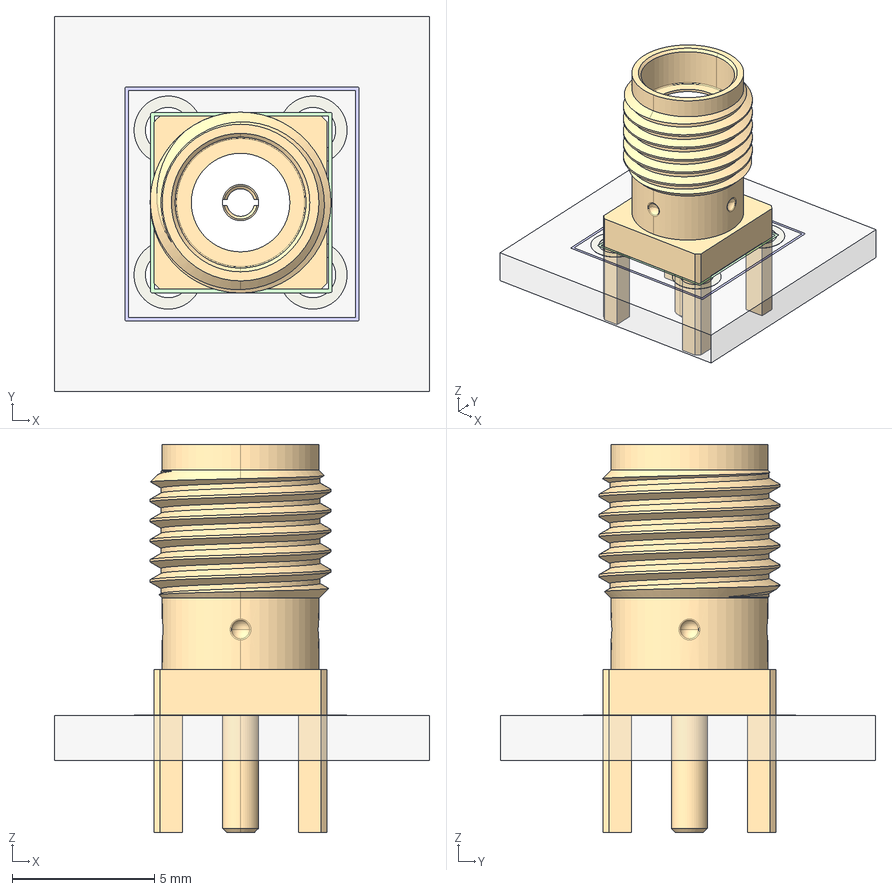
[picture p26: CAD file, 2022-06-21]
15v-supply/15v-supply-models/15v-supply-3D/molex-sma.FCStd
13.2 x 13.2 x 13.6 mm
FCrtYd
FFab
TopPads
BotPads
PTHs
Pcb

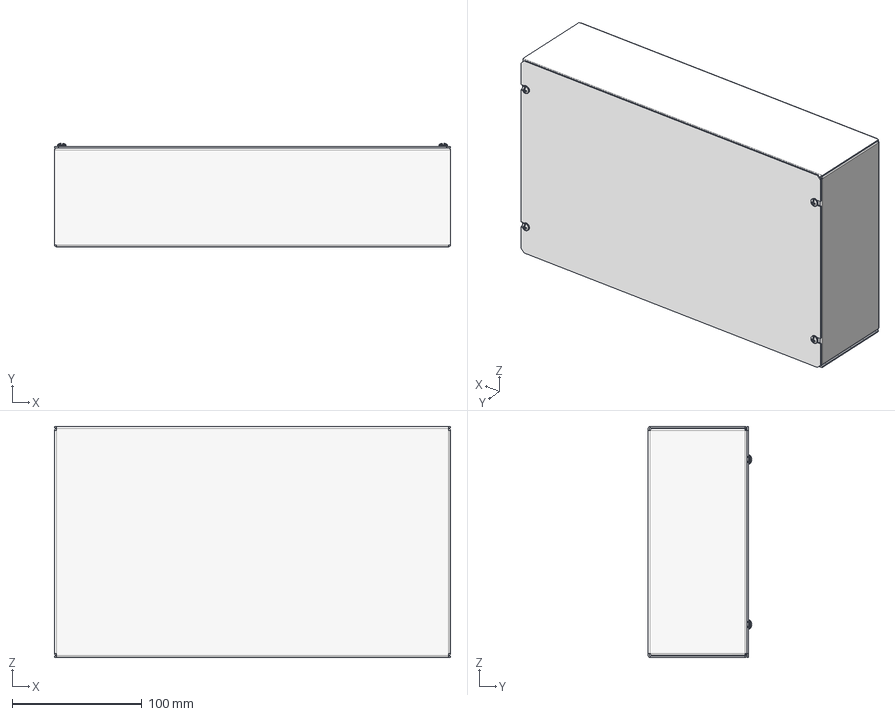
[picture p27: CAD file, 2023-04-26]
hierarchical-schematic/spectrum-analyzer-models/1444-1273.stp
304.8 x 79.7 x 177.8 mm
6-32 (SC18394) x 4

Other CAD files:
resolution-filters/resolution-filters/resolution-filters-models/resolution-filters-3D/Trimmer Cap - Brown.step
if-and-log-amp/if-and-log-amp/if-log-amp-models/if-log-amp-3D/terminal-block.FCStd
resolution-filters/resolution-filters/resolution-filters-models/resolution-filters-3D/UM-007.step
15v-supply/15v-supply-models/15v-supply-3D/CAP_QYX_3P5X6X8P5_NCH.step
15v-supply/15v-supply-F_Silkscreen.dxf
15v-supply/15v-supply-models/15v-supply-3D/1N5060-SOD-57_BYT62-BY203.stp
15v-supply/15v-supply-models/15v-supply-3D/6800u-U1-BBB_NCH.step
15v-supply/15v-supply-models/15v-supply-3D/691103110003_1.step
15v-supply/15v-supply-models/15v-supply-3D/7915-TO220-3_ONS.step
15v-supply/15v-supply-models/15v-supply-3D/fuse-holder.stp
15v-supply/15v-supply-models/15v-supply-3D/panel switch.stp
15v-supply/15v-supply-models/15v-supply-3D/terminal-block-691103110003.step
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

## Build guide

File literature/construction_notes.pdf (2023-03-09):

General Notes Regarding Construction of the Kanga US Spectrum Analyzer

This kit is really more of a “Parts for a Project” than a “Heathkit Style” step by step kit. If that is not what you were expecting, pack the kit right back up and send it back to me for a refund!

The kit as provided only includes the PC boards and board mounted parts along with the pots and feedthru capacitors. A block diagram of the SA along with schematics, Board layouts, and a parts list for each module is included. No detailed instructions are provided. You will need to provide the hookup wire, connectors that are used between the modules and on the front panel, hardware, +/- 15 volts, and the knobs for the front panel. You will also need to provide the inter-stage shielding that is necessary for good performance of the Spectrum Analyzer. That is critical to the final overall performance of the Analyzer.

Several hundred Spectrum Analyzer “kits” were sold several years ago before the flood that shut Kanga down for a period of time, and there are probably several hundred different versions that have been built. There is no “correct” way to build it. You will need to lay it out, construct it, test it a stage at a time, and get it all going as a system. Shielding and proper interconnections are critical to the final overall performance of the unit. Kanga supplies an optional set of die cast boxes that can be used to shield each of the modules, or you can supply your own, or build your own from materials as different as PC board or aluminum sheet.

The SA requires plus and minus 15 volts dc to operate. I bought a couple of cheap 15 volt open frame supplies form MPJA: http://www.mpja.com/Power-Supplies/departments/1/
and used them to provide the power. They mounted internally in the finished SA. You will need an ON/OFF switch – mine had no ON/OFF switch – it was unplugged when I wanted to turn it off!

W7ZOI's web page ( http://W7ZOI.net/tech.html )provides a lot of background material that is useful when you are building the SA, and will be useful if you decide to modify it when you are done building. SA's using this basic design have been built that go up to 1 GHz or more.

I have set up a Yahoo group to provide tech support for anyone building the SA. It is moderated (to keep out the spammers), so you will need to get “approval” before you can start posting to the group. Go to yahoogroups.com and search on KangaSA.

Other links that will be helpful when building the SA include:

http://www.kangaus.com/spectrum_analyzer.htm
http://www.minicircuits.com

A few notes on the individual modules are below.

Time Base Generator -

When completed check that the wave forms produced by the module are as expected. Check out W7ZOI's web page (http://w7zoi.net/SA_Oct08.pdf) if you are unsure of what to expect. It is the one board that does not have to be shielded in the final unit. As you can see from my photos, I mounted it on the top of the box that contains the IF/LOG Amp.

VCO -

The POS-200 is mounted so that the letters “MCL” stamped on the case are above the ”MCL” printed on the PC Board. The dots stamped on the top of the MAV-11 mmic's are mounted towards the dots printed on the PC Board. The ADE1- H mixer is mounted so that the dot on the top of the chip goes over the dot printed on the PC Board.

When completed you can connect the Time Base Generator to it and be sure the frequency output is in the correct range and has the correct amplitude.

IF/Log Amp -

The Toroidal transformer in the first stage is mounted on the PC Board so that the wires from the 8 turn winding go into the square pads. The two turn winding wires are soldered in the round pads.

The IF/Log amp should be built and tested in stages. The final amplifier (CA3140) can be built and tested with a dc signal fed into the input. The gain of the stage should be about 4.25, that is, if a 1 volt signal is applied to the input, 4.25 volts should appear at the output. Then the AD8307 stage should be built and tested. You should apply a 10.7 MHz signal to the input and vary it between +10dBm and -70dBm. The output of the 8307 should vary between about 2.3 volts (+10dBm in) and .25 volts (-70 dBm in). The output of the CA3140 stage should be between a bit less that 10 volts (+10dBm in) and 1 volt (-70dBm in). Peak the LC filter at the input of the 8307 at 10.7 Mhz.

The AD603 should have about 5.5 volts on Pin 2. The DC voltage on pin 1 should vary between about 4.5 and 6.8 volts giving a gain range of about -10 db to about +30 db through the stage at 10.7 MHz. The single transistor amplifier at the front end of the board will have a gain of about 9 db at 10.7 MHz.

Resolution Bandwidth Filter -

The large winding on the two toroidal transformers goes in the two pads farthest from the relays on the board. The small winding uses the two holes closest to the relays.

The Resolution BW Filter should be fairly straight forward – peak the trim caps with a 10.7 MHz signal.

Second Mixer and Second Local Oscillator -

There have been some circuit changes to the Second LO since the original article was written, but alignment is still the same. Replace the 100 MHz crystal with a 100 ohm resistor (tack solder it in place) and peak the trim cap for 100 MHz. The pull out the resistor and put in the crystal, and assuming the voltage levels are right, you will be good to go!

The dot stamped on the top of the MAV-11 mmic is mounted towards the dots printed on the PC Board. The ADE1- H mixer is mounted so that the dot on the top of the chip goes over the dot printed on the PC Board.

110.7 MHz Band Pass Filter -

The 110.7 MHz BP Filter has been changed since the original article was published. Check out the W7ZOI Web page for details on the upgrade. No PC board is supplied for the 110.7 MHz BP filter. It is constructed on scraps of un-etched copper-clad PC board. The PC board material can be used to make the shields between the sections of the filter, or brass flashing purchase from a local hobby shop can be used. Once it is constructed and aligned, a top cover of PC material or brass can be soldered in place. Good shielding is needed here. Go to: http://w7zoi.net/mixed-bag/mixed_bag.html for details on building the filter.

### 70 MHz Low Pass Filter -

The 70 MHz LPF has been re-designed to use a PC board and SMT parts. Be sure you get the right SMT parts in the right places on the PC board, button it up in a shielded box, and run a quick check to be sure it is working as expected – i.e. a flat response below 70 MHz and roll off above 70 MHz.

Interconnection Between the Modules -

The first SA I built several years ago (before the flood!) used RCA Phono Plugs just to prove it could be done. It worked just fine. W7ZOI's web page has a good writeup on

their use.

The second SA I built used BNC connectors for interconnections. They worked fairly well, but took up a lot of room in the SA. The next one I build will use SMA connectors and smaller coax.

You could even build the SA using no connectors. W7ZOI has info on his web page about feeding the signals thru the shields between the modules to the correct signals (and only the correct signals) get to the right place!

Enough feedthru capacitors are provided so that all the power connections to each module can be properly bypassed. The Pot connected to the IF/LOG Amp should also use three feedthru caps to get the leads in and out of the module.

Final Assembly -

It can not be stressed enough that the SA needs to be built in stages, and each stage aligned and tested separately before it is placed in the final unit. Be sure each stage is working properly before connecting the next stage!

Final Comments -

When you decided to build the SA, you committed to doing a big project. The Kanga US kit is not a kit in the Heathkit tradition, but is more of a “project” that you will be building. Each one built will be different from all the others, but the design is solid and has been proven by several hundred successful builds already out there. Many people have modified and expanded/improved on the design. It is hoped that you will also do the same and incorporate your own improvements to the design based on the parts and materials you have available when you do the project.

If you have trouble, questions, or suggestions, post them to the Yahoo Group, or send me an e-mail directly (n8et@woh.rr.com) and I will do my best to help you. Keep in mind that this summer I will be gone from about July 1 through August 15 on our sailboat in the Northern Great Lakes. If you are really need to talk with me during that time – check 40 cw in the evenings!

Sometime this fall I hope to have a Tracking Generator Kit available to go with the SA. The prototype has been built and is working.

Have fun building!

73 – Bill – N8ET – Kanga US

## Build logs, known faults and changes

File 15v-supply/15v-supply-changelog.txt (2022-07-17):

confirm c10 and c11 are c904 and 905 and then update the annotation - done
digikey bom uses 25V rated caps - schematic says 35V - conform - done
account for the heat sink in the layout - done

c904 and c905 footprints indicate polarized caps - they are, so done
determine proper fuse rating - done
re-route board due to error in diode pin outs
use larger footprints for passives
Indiate on silkscreen which output on terminal block is +15 out

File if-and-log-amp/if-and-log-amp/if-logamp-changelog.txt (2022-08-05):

change footprints for polar caps - done
L301 vertical? - done
ft caps need ground point - done
eliminate coax pcb [do same timebase] - done
ground hole to ground box to board - done ** RECONSIDER THIS ** - removed
move the silkscreen pin 1 markers to outsie of the footprint body so visible after IC mounting - done
pin 4 of CA3140 must be grounded. - done
pin 1 of CA3140 should be a no-connect - done
J305 will be a little better if flipped so that the ground is toward outside of the board - removed and replaced with feedthrough cap fp 
cap leads should be 5mm apart -done 
changer "j" solder holes to "C" to reflect connection of feedthrough caps - label to indicate hot is not connected - done except silkscreen - might eliminate hole
make c311 polarized, negative terminal to ground - done
schematic - switched output coax and feedthrough cap so feedthrough cap is before ouput connector - done
doublecheck order of pot caps to make sure pin 2 is in middle
fix footprints for non polar caps

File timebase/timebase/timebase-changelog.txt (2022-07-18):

Add asterisks to indicate location of pin 1 for op amps - done
Replace J401 and J402 with wire solder points - or screw terminal - done
Add board name and revision to silk - done
Star pin 1 for leads to pots? - no need
Switch capacitor footprints to be vertical - or orient all with "+" the same way - done
Update coax connector to be amphenol 112404 - done
change board mounting holes - done
switch diode footprints to be all the same way - no need

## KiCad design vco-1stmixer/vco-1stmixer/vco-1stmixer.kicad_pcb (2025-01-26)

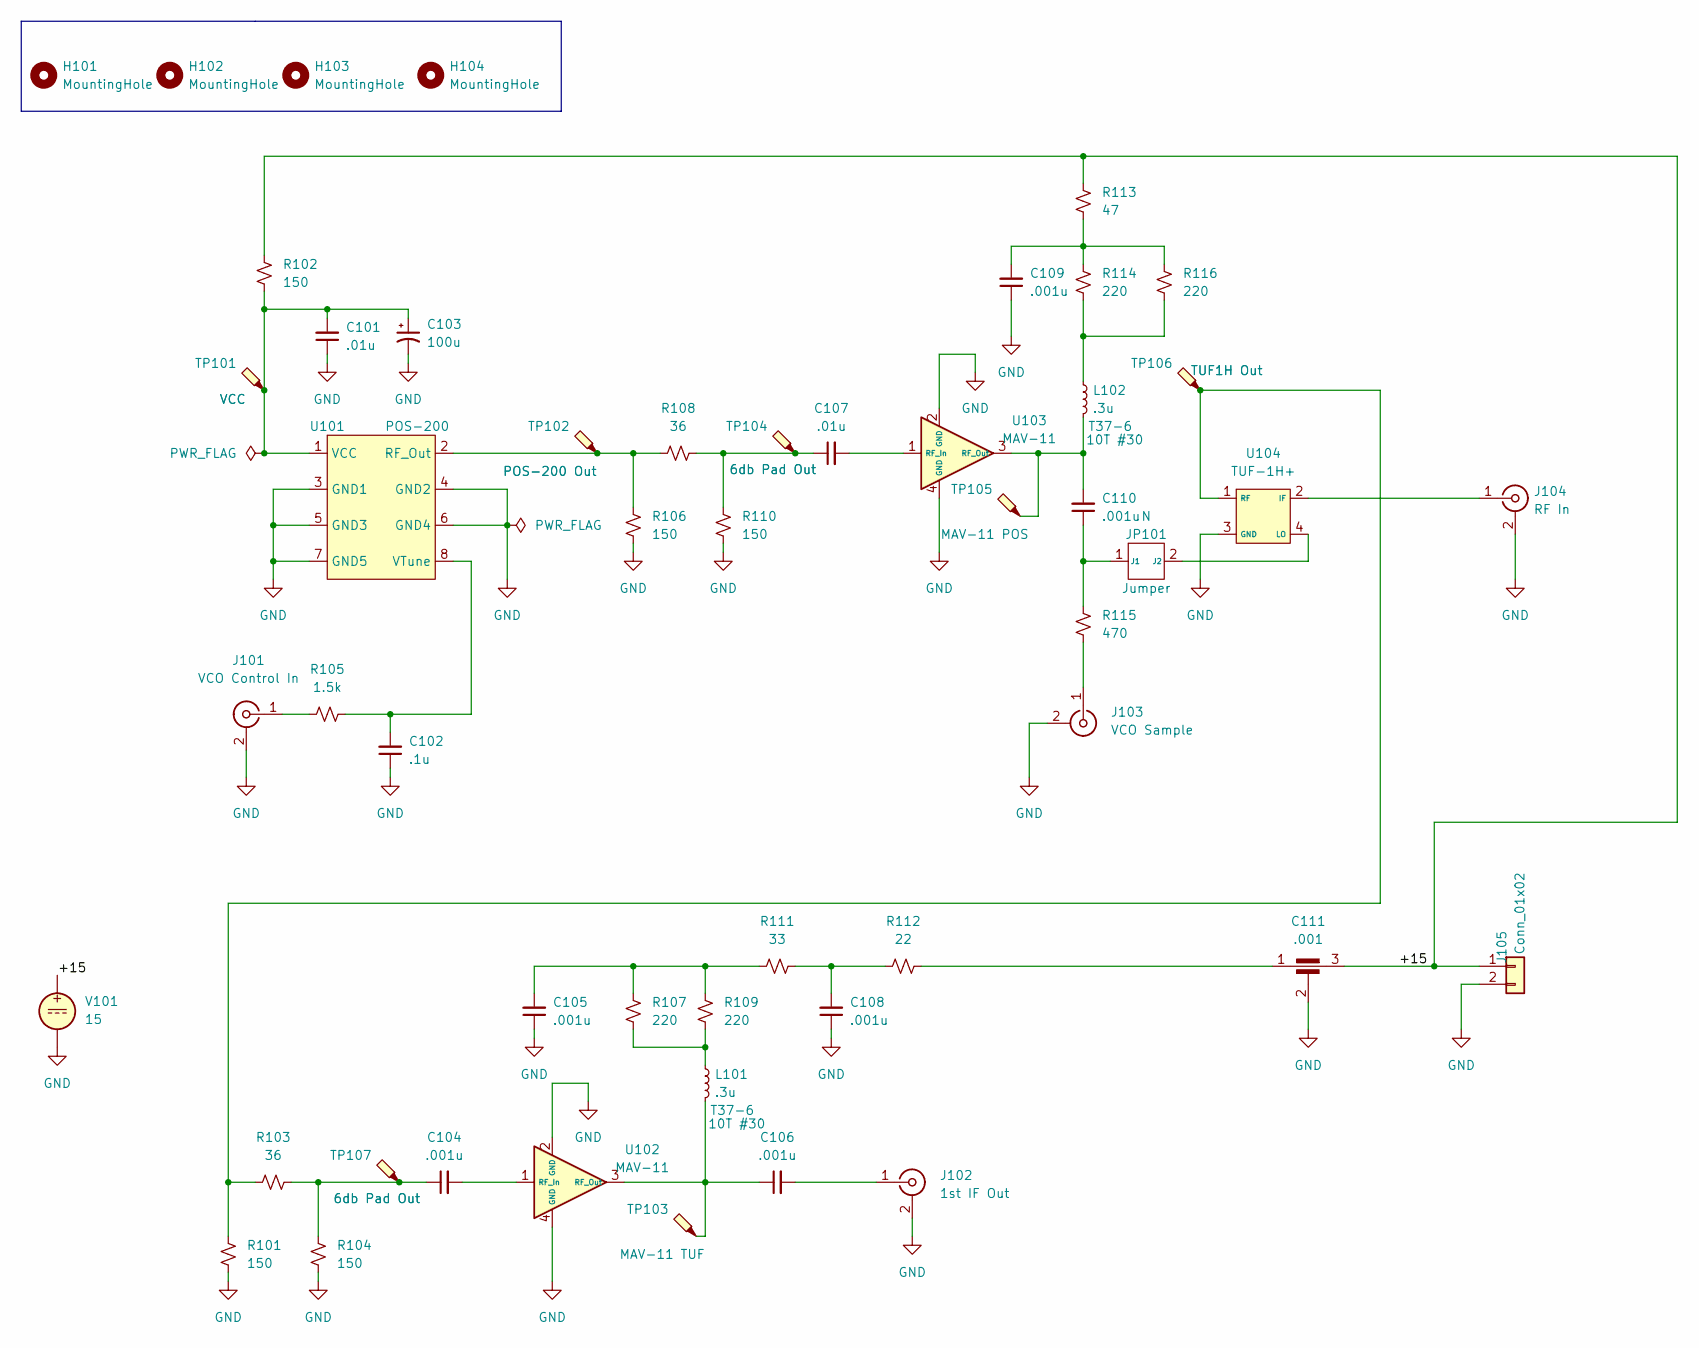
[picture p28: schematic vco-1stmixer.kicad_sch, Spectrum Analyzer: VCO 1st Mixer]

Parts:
C101, C107: .01u; C_Disc_D5.0mm_W2.5mm_P5.00mm
C102: .1u; C_Disc_D5.0mm_W2.5mm_P5.00mm
C103: 100u; CP_Radial_D8.0mm_P3.50mm
C104, C105, C106, C108, C109, C110: .001u; C_Disc_D5.0mm_W2.5mm_P5.00mm
C111: .001; DSS1N_MUR
H101, H102, H103, H104: MountingHole; MountingHole_3.2mm_M3
J101: VCO Control In; SolderWire-0.5sqmm_1x02_P4.6mm_D0.9mm_OD2.1mm
J102: 1st IF Out; SolderWire-0.5sqmm_1x02_P4.6mm_D0.9mm_OD2.1mm
J103: VCO Sample; PinHeader_1x02_P2.54mm_Vertical
J104: RF In; SolderWire-0.5sqmm_1x02_P4.6mm_D0.9mm_OD2.1mm
J105: Conn_01x02; SolderWire-0.5sqmm_1x02_P4.6mm_D0.9mm_OD2.1mm
JP101: Jumper; 22284028
L101, L102: .3u; L_Toroid_Vertical_L13.0mm_W6.5mm_P5.60mm
R101, R102, R104, R106, R110: 150; R_Axial_DIN0207_L6.3mm_D2.5mm_P7.62mm_Horizontal
R103, R108: 36; R_Axial_DIN0207_L6.3mm_D2.5mm_P7.62mm_Horizontal
R105: 1.5k; R_Axial_DIN0207_L6.3mm_D2.5mm_P7.62mm_Horizontal
R107, R109, R114, R116: 220; R_Axial_DIN0207_L6.3mm_D2.5mm_P7.62mm_Horizontal
R111: 33; R_Axial_DIN0207_L6.3mm_D2.5mm_P7.62mm_Horizontal
R112: 22; R_Axial_DIN0207_L6.3mm_D2.5mm_P7.62mm_Horizontal
R113: 47; R_Axial_DIN0207_L6.3mm_D2.5mm_P7.62mm_Horizontal
R115: 470; R_Axial_DIN0207_L6.3mm_D2.5mm_P7.62mm_Horizontal
TP101: VCC; TestPoint_Pad_1.0x1.0mm
TP102: POS-200 Out; TestPoint_Pad_1.0x1.0mm
TP103: MAV-11 TUF; TestPoint_Pad_1.0x1.0mm
TP104, TP107: 6db Pad Out; TestPoint_Pad_1.0x1.0mm
TP105: MAV-11 POS; TestPoint_Pad_1.0x1.0mm
TP106: TUF1H Out; TestPoint_Pad_1.0x1.0mm
U101: POS-200
U102, U103: MAV-11; MAV-11BSM&plus_
U104: TUF-1H+; TUF-1H
V101: 15

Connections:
/+15: C111.3, J105.1, R102.2, R113.2, V101.1
GND: C101.1, C102.1, C103.2, C105.1, C108.1, C109.1, C111.2, J101.2 (Ext), J102.2 (Ext), J103.2 (Ext), J104.2 (Ext), J105.2, R101.1, R104.1, R106.1, R110.1, U101.3 (GND1), U101.4 (GND2), U101.5 (GND3), U101.6 (GND4), U101.7 (GND5), U102.2 (GND), U102.4 (GND), U103.2 (GND), U103.4 (GND), U104.3 (GND), V101.2
unnamed: C104.1, R103.2, R104.2, TP107.1
unnamed: C105.2, R107.2, R109.2, R111.1
unnamed: C107.1, R108.2, R110.2, TP104.1
unnamed: C108.2, R111.2, R112.1
unnamed: C109.2, R113.1, R114.2, R116.2
unnamed: C111.1, R112.2
unnamed: J101.1 (In), R105.1
unnamed: C106.2, J102.1 (In)
unnamed: J103.1 (In), R115.1
unnamed: J104.1 (In), U104.2 (IF)
unnamed: C110.1, JP101.1 (J1), R115.2
unnamed: JP101.2 (J2), U104.4 (LO)
unnamed: L101.1, R107.1, R109.1
unnamed: L102.1, R114.1, R116.1
unnamed: R106.2, R108.1, TP102.1, U101.2 (RF_Out)
unnamed: C101.2, C103.1, R102.1, TP101.1, U101.1 (VCC)
unnamed: C102.2, R105.2, U101.8 (VTune)
unnamed: C104.2, U102.1 (RF_In)
unnamed: C106.1, L101.2, TP103.1, U102.3 (RF_Out)
unnamed: C107.2, U103.1 (RF_In)
unnamed: C110.2, L102.2, TP105.1, U103.3 (RF_Out)
unnamed: R101.2, R103.1, TP106.1, U104.1 (RF)

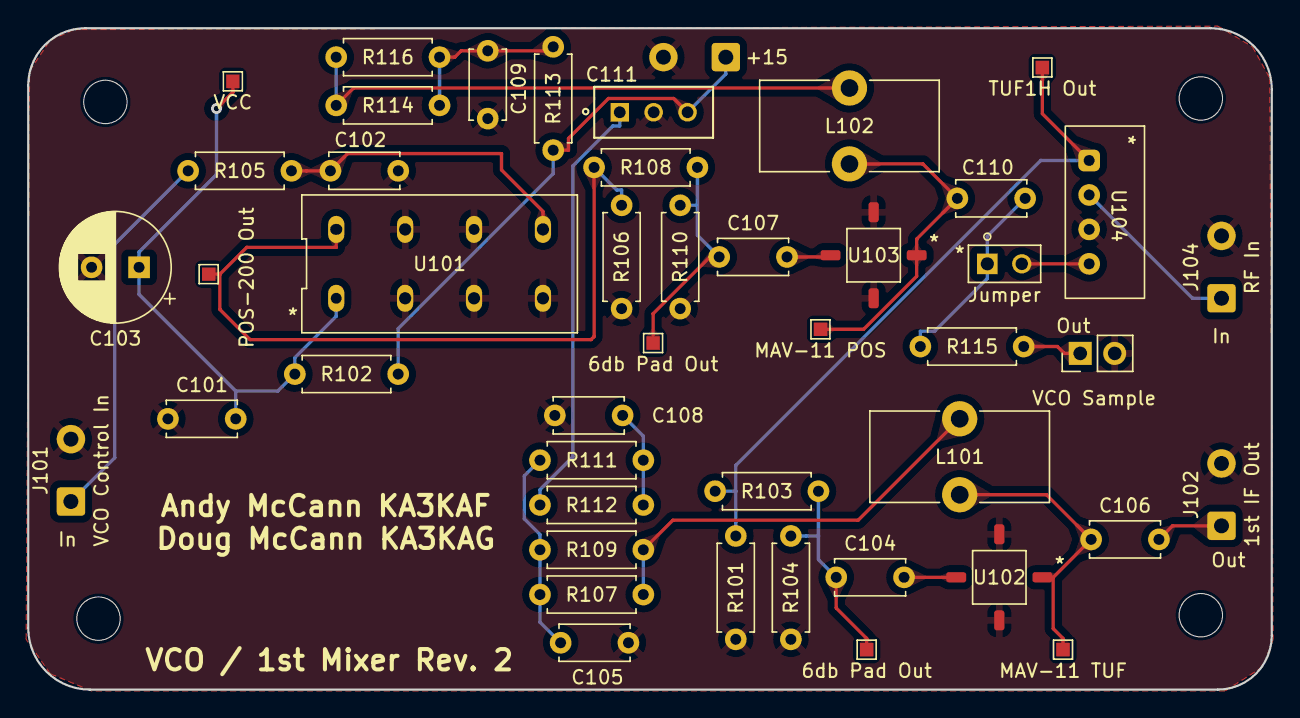
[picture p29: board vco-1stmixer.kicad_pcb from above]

Board: 2 copper layers, 91.7 x 48.8 mm, 50 parts (0 on the bottom side), 24 nets.

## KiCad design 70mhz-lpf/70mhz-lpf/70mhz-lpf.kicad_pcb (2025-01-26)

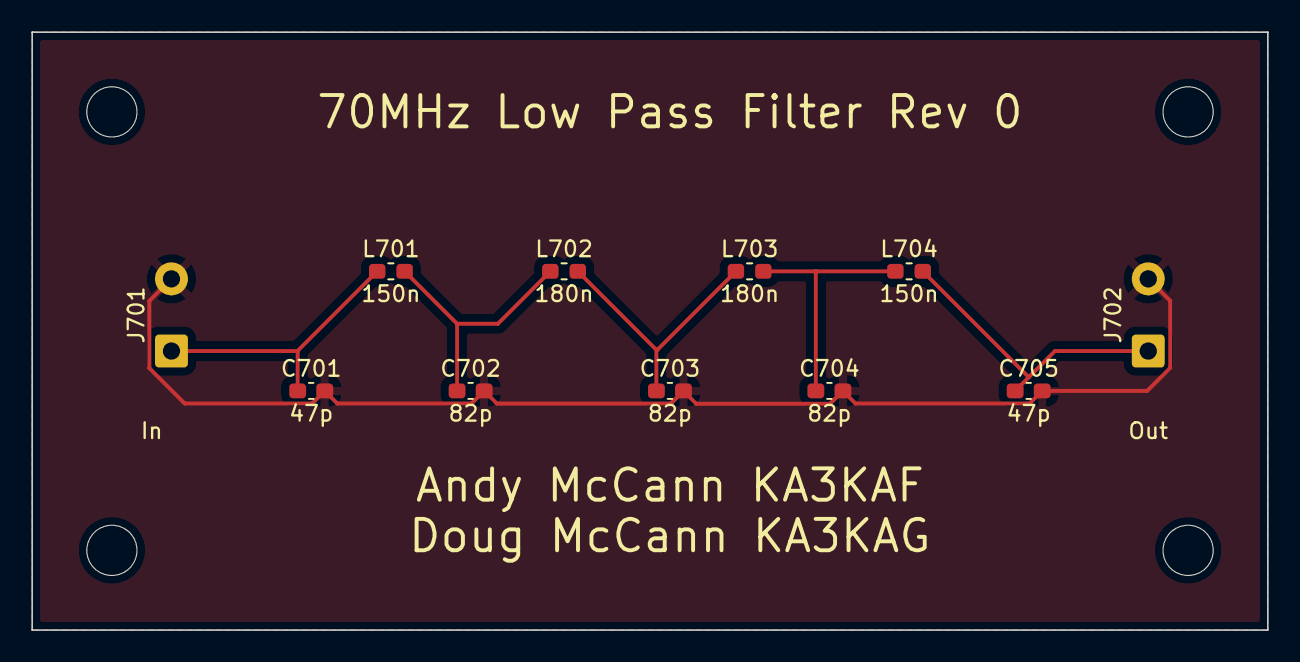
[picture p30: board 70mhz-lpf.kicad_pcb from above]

Board: 2 copper layers, 78.7 x 38.1 mm, 15 parts (0 on the bottom side), 6 nets.

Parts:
C701, C705: 47p; C_0603_1608Metric_Pad1.08x0.95mm_HandSolder
C702, C703, C704: 82p; C_0603_1608Metric_Pad1.08x0.95mm_HandSolder
H701, H702, H703, H704: MountingHole; MountingHole_3.2mm_M3
J701, J702: Coax Solder Point; SolderWire-0.5sqmm_1x02_P4.6mm_D0.9mm_OD2.1mm
L701, L704: 150n; L_0603_1608Metric_Pad1.05x0.95mm_HandSolder
L702, L703: 180n; L_0603_1608Metric_Pad1.05x0.95mm_HandSolder

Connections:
/In: C701.1, J701.1 (In), L701.1
/Out: C705.1, J702.1 (In), L704.2
GND: C701.2, C702.2, C703.2, C704.2, C705.2, J701.2 (Ext), J702.2 (Ext)
unnamed: C702.1, L701.2, L702.1
unnamed: C703.1, L702.2, L703.1
unnamed: C704.1, L703.2, L704.1

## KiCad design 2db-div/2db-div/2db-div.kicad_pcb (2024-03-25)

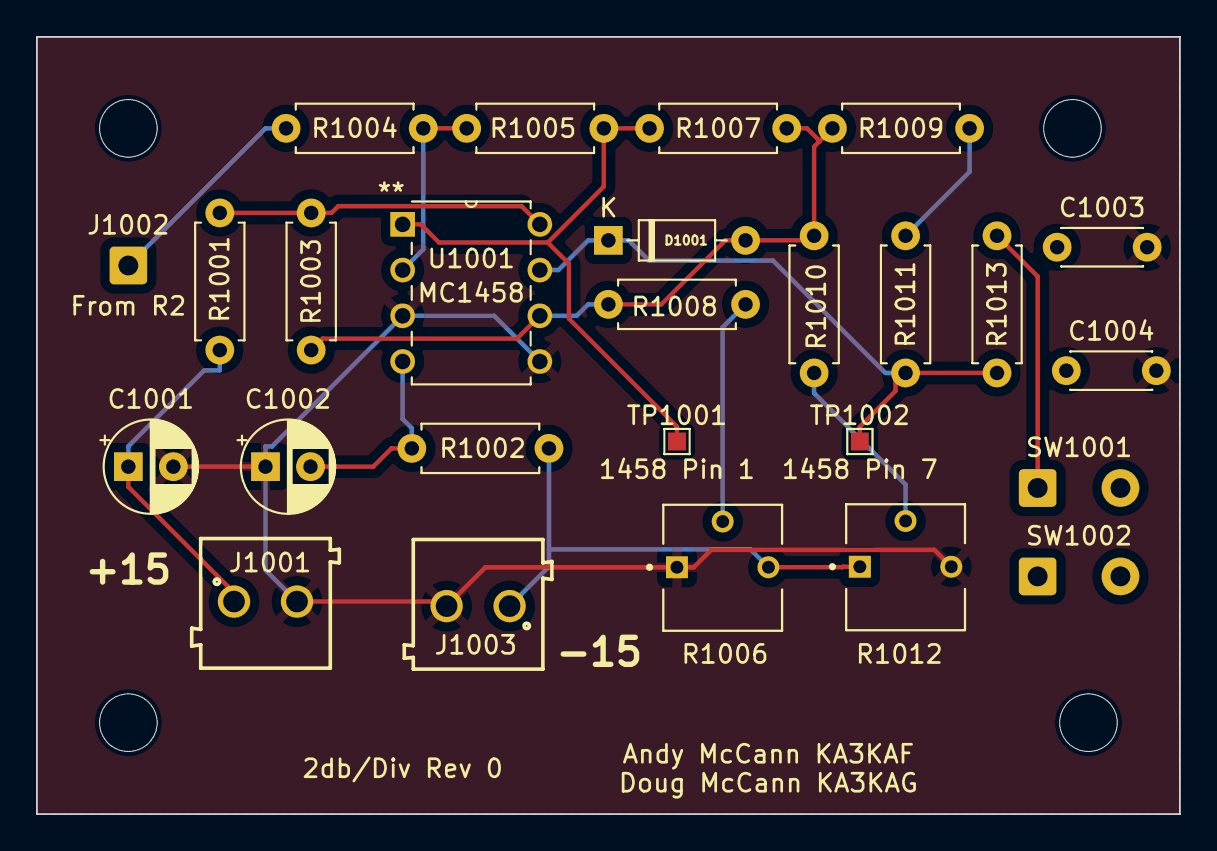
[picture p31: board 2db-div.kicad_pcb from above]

Board: 2 copper layers, 63.5 x 43.2 mm, 30 parts (0 on the bottom side), 16 nets.

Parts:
C1001, C1002: 100u; CP_Radial_D5.0mm_P2.50mm
C1003: .1u; C_Disc_D4.3mm_W1.9mm_P5.00mm
C1004: 3.3u; C_Disc_D4.3mm_W1.9mm_P5.00mm
D1001: 1N4148; D_DO-35_SOD27_P7.62mm_Horizontal
H1001, H1002, H1003, H1004: type="R" model="MountingHole" lib=""; MountingHole_3.2mm_M3
J1001, J1003: Conn_01x02; 691103110002
J1002: From R2; SolderWire-0.5sqmm_1x01_D0.9mm_OD2.1mm
R1001, R1002: 43; R_Axial_DIN0207_L6.3mm_D2.5mm_P7.62mm_Horizontal
R1003, R1004, R1008, R1009: 20k; R_Axial_DIN0207_L6.3mm_D2.5mm_P7.62mm_Horizontal
R1005: 40k; R_Axial_DIN0207_L6.3mm_D2.5mm_P7.62mm_Horizontal
R1006, R1012: 10k; TRIM_3362P-1-103LF
R1007: 10k; R_Axial_DIN0207_L6.3mm_D2.5mm_P7.62mm_Horizontal
R1010: 249k; R_Axial_DIN0207_L6.3mm_D2.5mm_P7.62mm_Horizontal
R1011: 4.99k; R_Axial_DIN0207_L6.3mm_D2.5mm_P7.62mm_Horizontal
R1013: 1k; R_Axial_DIN0207_L6.3mm_D2.5mm_P7.62mm_Horizontal
SW1001: 2dB; SolderWire-0.5sqmm_1x02_P4.6mm_D0.9mm_OD2.1mm
SW1002: type="R" model="Video" lib=""; SolderWire-0.5sqmm_1x02_P4.6mm_D0.9mm_OD2.1mm
TP1001: 1458 Pin 1; TestPoint_Pad_1.0x1.0mm
TP1002: 1458 Pin 7; TestPoint_Pad_1.0x1.0mm
U1001: MC1458; MC1458P

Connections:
/+15: C1001.1, J1001.1, R1001.2
/-15: J1003.1, R1002.1, R1006.3, R1012.1
/In: J1002.1, R1004.1
GND: C1001.2, C1002.1, C1003.2, C1004.2, J1001.2, J1003.2, R1006.1, R1012.3, U1001.3 (+), U1001.5 (+)
unnamed: C1003.1, SW1002.2
unnamed: C1004.1, SW1002.1
unnamed: D1001.2 (A), R1003.1, R1007.2, R1008.2, R1009.1, R1010.1, U1001.6 (-)
unnamed: D1001.1 (K), R1011.2, R1013.1, TP1002.1, U1001.7
unnamed: R1005.2, R1007.1, TP1001.1, U1001.1
unnamed: R1006.2, R1008.1
unnamed: R1009.2, R1011.1
unnamed: R1010.2, R1012.2
unnamed: R1013.2, SW1001.1 (A)
unnamed: R1004.2, R1005.1, U1001.2 (-)
unnamed: R1001.1, R1003.2, U1001.8 (V+)
unnamed: C1002.2, R1002.2, U1001.4 (V-)

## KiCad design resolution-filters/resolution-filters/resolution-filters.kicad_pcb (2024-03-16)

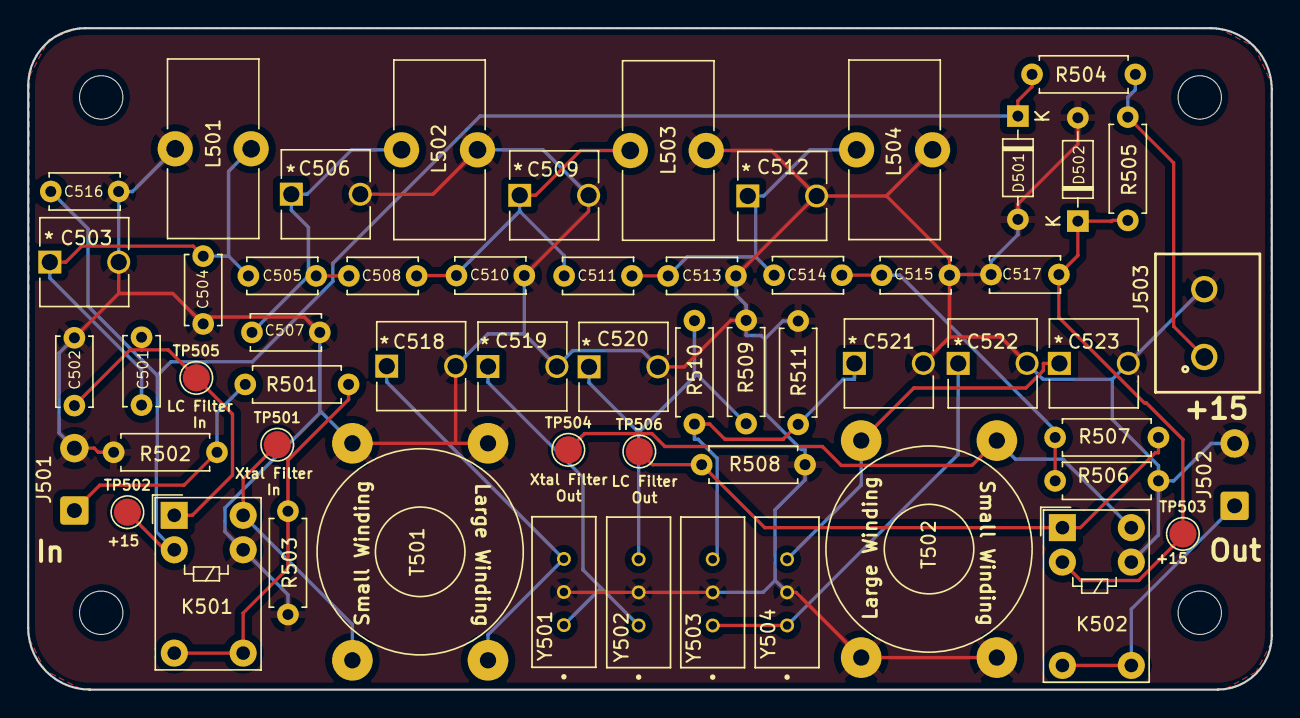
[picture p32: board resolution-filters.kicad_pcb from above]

Board: 2 copper layers, 91.7 x 48.8 mm, 61 parts (0 on the bottom side), 22 nets.

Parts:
C501, C514: 56p; C_Disc_D5.0mm_W2.5mm_P5.00mm
C502, C515: 120p; C_Disc_D5.0mm_W2.5mm_P5.00mm
C503, C506, C509, C512: 12p-60p; GKG60015
C504, C513: 100p; C_Disc_D5.0mm_W2.5mm_P5.00mm
C505, C511: 5.6p; C_Disc_D5.0mm_W2.5mm_P5.00mm
C507, C510: 150p; C_Disc_D5.0mm_W2.5mm_P5.00mm
C508: 3.3p; C_Disc_D5.0mm_W2.5mm_P5.00mm
C516, C517: .1u; C_Disc_D5.0mm_W2.5mm_P5.00mm
C518, C519, C520, C521, C522, C523: 1.8p-10p; GKG60015
D501, D502: 1N4148; D_DO-35_SOD27_P7.62mm_Horizontal
H501, H502, H503, H504: MountingHole; MountingHole_3.2mm_M3
J501, J502: Conn_Coaxial; SolderWire-0.5sqmm_1x02_P4.6mm_D0.9mm_OD2.1mm
J503: Terminal Block; 691137710002
K501, K502: G5V-1; Relay_SPDT_Omron_G5V-1
L501, L502, L503, L504: 1.15u; L_Toroid_Vertical_L13.0mm_W6.5mm_P5.60mm
R501: 36; R_Axial_DIN0207_L6.3mm_D2.5mm_P7.62mm_Horizontal
R502, R503: 150; R_Axial_DIN0207_L6.3mm_D2.5mm_P7.62mm_Horizontal
R504, R505: 270; R_Axial_DIN0207_L6.3mm_D2.5mm_P7.62mm_Horizontal
R506, R508: 10M; R_Axial_DIN0207_L6.3mm_D2.5mm_P7.62mm_Horizontal
R507: 0; R_Axial_DIN0207_L6.3mm_D2.5mm_P7.62mm_Horizontal
R509, R511: 9.1k; R_Axial_DIN0207_L6.3mm_D2.5mm_P7.62mm_Horizontal
R510: 2.2k; R_Axial_DIN0207_L6.3mm_D2.5mm_P7.62mm_Horizontal
T501, T502: Transformer_1P_1S; Transformer_Toroid_Horizontal_D14.0mm_Amidon-T50
TP501, TP502, TP503, TP504, TP505, TP506: TestPoint; TestPoint_Pad_D2.0mm
Y501, Y502, Y503, Y504: 10.7MHz; XTAL_ECS-10.7-7.5B

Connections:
/30Khz Out: K502.10, T502.2 (AA), TP504.1
/30kHz In: K501.10, T501.2 (AA), TP501.1
/300kHz In: C501.1, C502.1, K501.1, TP505.1
/300kHz Out: K502.1, R507.2, R508.1, TP506.1
/501-in: C516.1, D501.1 (K), K501.2, R504.1, TP502.1
/502-in: C517.1, D502.1 (K), K502.2, R505.2, TP503.1
/VIn: J501.1 (In), R501.1, R502.1
GND: C502.2, C503.2, C504.2, C506.2, C507.2, C509.2, C510.2, C512.2, C513.2, C515.2, C516.2, C517.2, C518.2, C519.2, C520.2, C521.2, C522.2, C523.2, D501.2 (A), D502.2 (A), J501.2 (Ext), J502.2 (Ext), J503.2, K501.9, K502.9, L501.2, L502.2, L503.2, L504.2, R502.2, R503.2, R506.2, R508.2, R509.2, R511.2, T501.1 (AB), T501.3 (SA), T502.1 (AB), T502.3 (SA), Y501.2, Y502.2, Y503.2, Y504.2
unnamed: C501.2, C503.1, C504.1, C505.1, L501.1
unnamed: C505.2, C506.1, C507.1, C508.1, L502.1
unnamed: C508.2, C509.1, C510.1, C511.1, L503.1
unnamed: C511.2, C512.1, C513.1, C514.1, L504.1
unnamed: C514.2, C515.1, R506.1, R507.1
unnamed: C518.1, T501.4 (SB), Y501.3
unnamed: C519.1, Y501.1, Y502.1
unnamed: C520.1, R509.1, R510.1, Y502.3
unnamed: C521.1, R510.2, R511.1, Y503.3
unnamed: C522.1, Y503.1, Y504.1
unnamed: C523.1, T502.4 (SB), Y504.3
unnamed: J503.1, R504.2, R505.1
unnamed: J502.1 (In), K502.5, K502.6
unnamed: K501.5, K501.6, R501.2, R503.1

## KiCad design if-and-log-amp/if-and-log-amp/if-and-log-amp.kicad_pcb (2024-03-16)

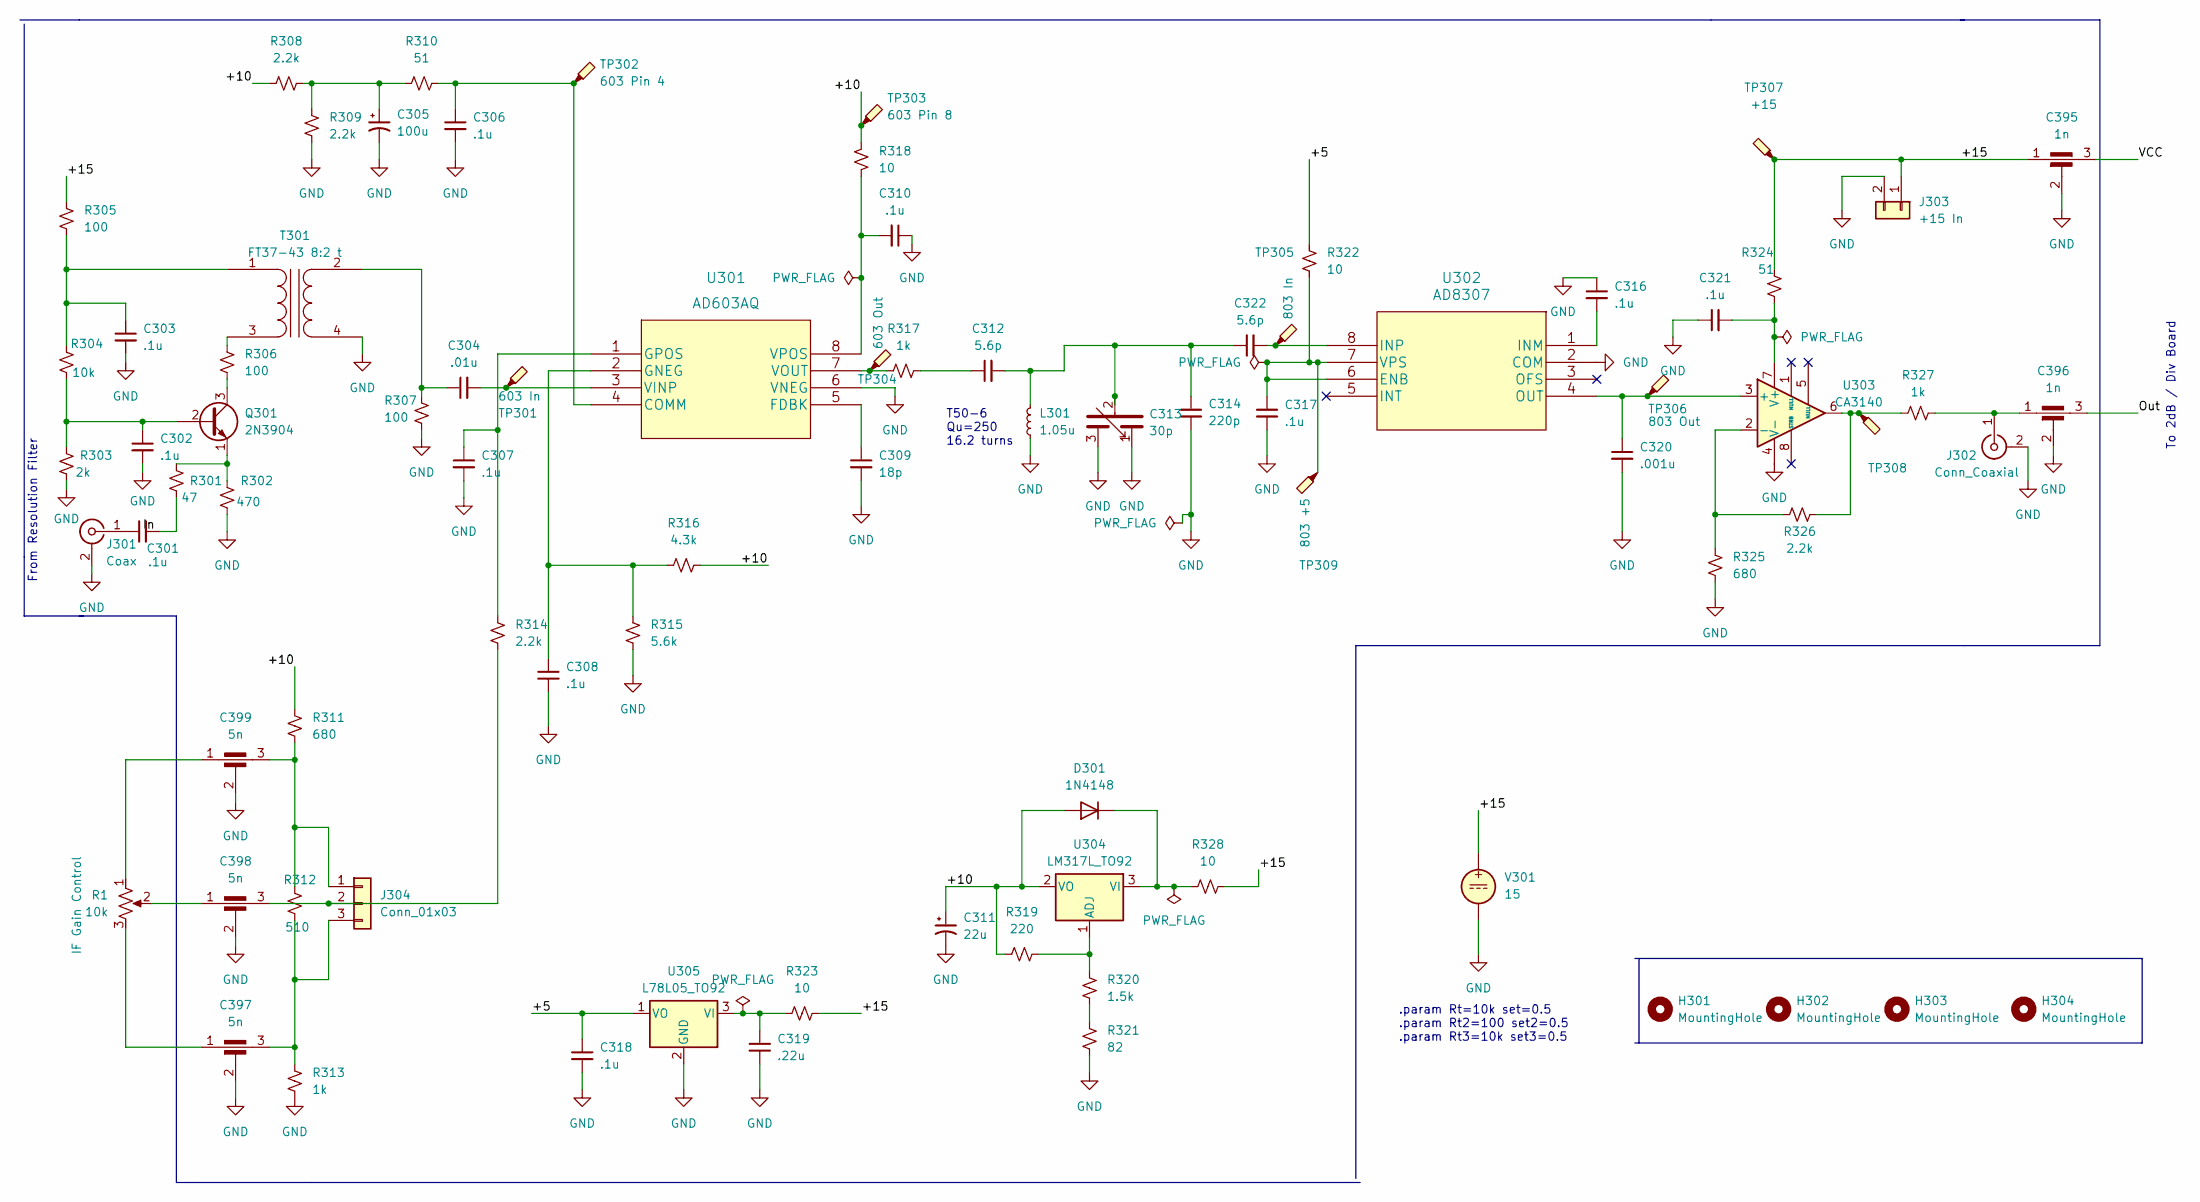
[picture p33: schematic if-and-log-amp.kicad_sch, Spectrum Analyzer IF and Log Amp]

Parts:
C301, C302, C303, C306, C307, C308, C310, C316, C317, C318, C321: .1u; C_Disc_D5.0mm_W2.5mm_P5.00mm
C304: .01u; C_Disc_D5.0mm_W2.5mm_P5.00mm
C305: 100u; CP_Radial_D5.0mm_P2.50mm
C309: 18p; C_Disc_D5.0mm_W2.5mm_P5.00mm
C311: 22u; CP_Radial_D5.0mm_P2.50mm
C312, C322: 5.6p; C_Disc_D5.0mm_W2.5mm_P5.00mm
C313: 30p; BFC280831659
C314: 220p; C_Disc_D5.0mm_W2.5mm_P5.00mm
C319: .22u; C_Disc_D5.0mm_W2.5mm_P5.00mm
C320: .001u; C_Disc_D5.0mm_W2.5mm_P5.00mm
C395, C396: 1n; DSS1NB32A102Q91A
C397, C398, C399: 5n; DSS1NB32A102Q91A
D301: 1N4148; D_DO-35_SOD27_P7.62mm_Horizontal
H301, H302, H303, H304: MountingHole; MountingHole_3.2mm_M3
J301: Coax; SolderWire-0.5sqmm_1x02_P4.6mm_D0.9mm_OD2.1mm
J302: Conn_Coaxial; SolderWire-0.5sqmm_1x02_P4.6mm_D0.9mm_OD2.1mm
J303: +15 In; 691103110002
J304: Conn_01x03; SolderWire-0.5sqmm_1x03_P4.6mm_D0.9mm_OD2.1mm
L301: 1.05u; L_Toroid_Vertical_L13.0mm_W6.5mm_P5.60mm
Q301: 2N3904; TO-92_Inline
R1: 10k
R301: 47; R_Axial_DIN0207_L6.3mm_D2.5mm_P7.62mm_Horizontal
R302: 470; R_Axial_DIN0207_L6.3mm_D2.5mm_P7.62mm_Horizontal
R303: 2k; R_Axial_DIN0207_L6.3mm_D2.5mm_P7.62mm_Horizontal
R304: 10k; R_Axial_DIN0207_L6.3mm_D2.5mm_P7.62mm_Horizontal
R305, R306, R307: 100; R_Axial_DIN0207_L6.3mm_D2.5mm_P7.62mm_Horizontal
R308, R309, R314, R326: 2.2k; R_Axial_DIN0207_L6.3mm_D2.5mm_P7.62mm_Horizontal
R310, R324: 51; R_Axial_DIN0207_L6.3mm_D2.5mm_P7.62mm_Horizontal
R311, R325: 680; R_Axial_DIN0207_L6.3mm_D2.5mm_P7.62mm_Horizontal
R312: 510; R_Axial_DIN0207_L6.3mm_D2.5mm_P7.62mm_Horizontal
R313, R317, R327: 1k; R_Axial_DIN0207_L6.3mm_D2.5mm_P7.62mm_Horizontal
R315: 5.6k; R_Axial_DIN0207_L6.3mm_D2.5mm_P7.62mm_Horizontal
R316: 4.3k; R_Axial_DIN0207_L6.3mm_D2.5mm_P7.62mm_Horizontal
R318, R322, R323, R328: 10; R_Axial_DIN0207_L6.3mm_D2.5mm_P7.62mm_Horizontal
R319: 220; R_Axial_DIN0207_L6.3mm_D2.5mm_P7.62mm_Horizontal
R320: 1.5k; R_Axial_DIN0207_L6.3mm_D2.5mm_P7.62mm_Horizontal
R321: 82; R_Axial_DIN0207_L6.3mm_D2.5mm_P7.62mm_Horizontal
T301: FT37-43 8:2 t; Transformer Vertical 1P 1S
TP301: 603 In; TestPoint_Pad_1.0x1.0mm
TP302: 603 Pin 4; TestPoint_Pad_1.0x1.0mm
TP303: 603 Pin 8; TestPoint_Pad_1.0x1.0mm
TP304: 603 Out; TestPoint_Pad_1.0x1.0mm
TP305: 803 In; TestPoint_Pad_1.0x1.0mm
TP306: 803 Out; TestPoint_Pad_1.0x1.0mm
TP307: +15; TestPoint_Pad_1.0x1.0mm
TP308: CA3140 Out; TestPoint_Pad_1.0x1.0mm
TP309: 803 +5; TestPoint_Pad_1.0x1.0mm
U301: AD603AQ
U302: AD8307; AD8307AN
U303: CA3140; CA3140EZ
U304: LM317L_TO92; TO-92_Inline
U305: L78L05_TO92; TO-92_Inline
V301: 15

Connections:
/+5: C318.1, R322.1, U305.1 (VO)
/+10: C311.1, D301.2 (A), R308.1, R311.1, R316.2, R318.1, R319.1, TP303.1, U304.2 (VO)
/+15: C395.1, J303.1, R305.1, R323.1, R324.2, R328.2, TP307.1, V301.1
GND: C302.2, C303.2, C305.2, C306.2, C307.2, C308.2, C309.2, C310.1, C311.2, C313.1, C313.3, C314.2, C316.1, C317.2, C318.2, C319.2, C320.2, C321.1, C395.2, C396.2, C397.2, C398.2, C399.2, J301.2 (Ext), J302.2 (Ext), J303.2, L301.1, R302.2, R303.2, R307.2, R309.2, R313.2, R315.2, R321.2, R325.2, T301.4 (SA), U301.6 (VNEG), U302.2 (COM), U303.4 (V-), U305.2 (GND), V301.2
unnamed: C301.2, R301.2
unnamed: C305.1, R308.2, R309.1, R310.1
unnamed: C312.1, R317.2
unnamed: C312.2, C313.2, C314.1, C322.1, L301.2
unnamed: C397.1, R1.3
unnamed: C398.1, R1.2
unnamed: C399.1, R1.1
unnamed: D301.1 (K), R328.1, U304.3 (VI)
unnamed: C301.1, J301.1 (In)
unnamed: C396.1, J302.1 (In), R327.2
unnamed: C399.3, J304.1, R311.2, R312.1
unnamed: C398.3, J304.2, R314.2
unnamed: C397.3, J304.3, R312.2, R313.1
unnamed: C302.1, Q301.2 (B), R303.1, R304.2
unnamed: Q301.3 (C), R306.2
unnamed: Q301.1 (E), R301.1, R302.1
unnamed: R320.2, R321.1
unnamed: R326.1, R327.1, TP308.1, U303.6
unnamed: C303.1, R304.1, R305.2, T301.1 (AA)
unnamed: R306.1, T301.3 (AB)
unnamed: C304.1, R307.1, T301.2 (SB)
unnamed: C306.1, R310.2, TP302.1, U301.4 (COMM)
unnamed: C309.1, U301.5 (FDBK)
unnamed: C308.1, R315.1, R316.1, U301.2 (GNEG)
unnamed: C307.1, R314.1, U301.1 (GPOS)
unnamed: C304.2, TP301.1, U301.3 (VINP)
unnamed: R317.1, TP304.1, U301.7 (VOUT)
unnamed: C310.2, R318.2, U301.8 (VPOS)
unnamed: C317.1, R322.2, TP309.1, U302.6 (ENB), U302.7 (VPS)
unnamed: C316.2, U302.1 (INM)
unnamed: C322.2, TP305.1, U302.8 (INP)
unnamed: C320.1, TP306.1, U302.4 (OUT), U303.3 (+)
unnamed: R325.1, R326.2, U303.2 (-)
unnamed: C321.2, R324.1, U303.7 (V+)
unnamed: R319.2, R320.1, U304.1 (ADJ)
unnamed: C319.1, R323.2, U305.3 (VI)

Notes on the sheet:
T50-6 Qu=250 16.2 turns
From Resolution Filter
To 2dB / Div Board
.param Rt=10k set=0.5 .param Rt2=100 set2=0.5 .param Rt3=10k set3=0.5

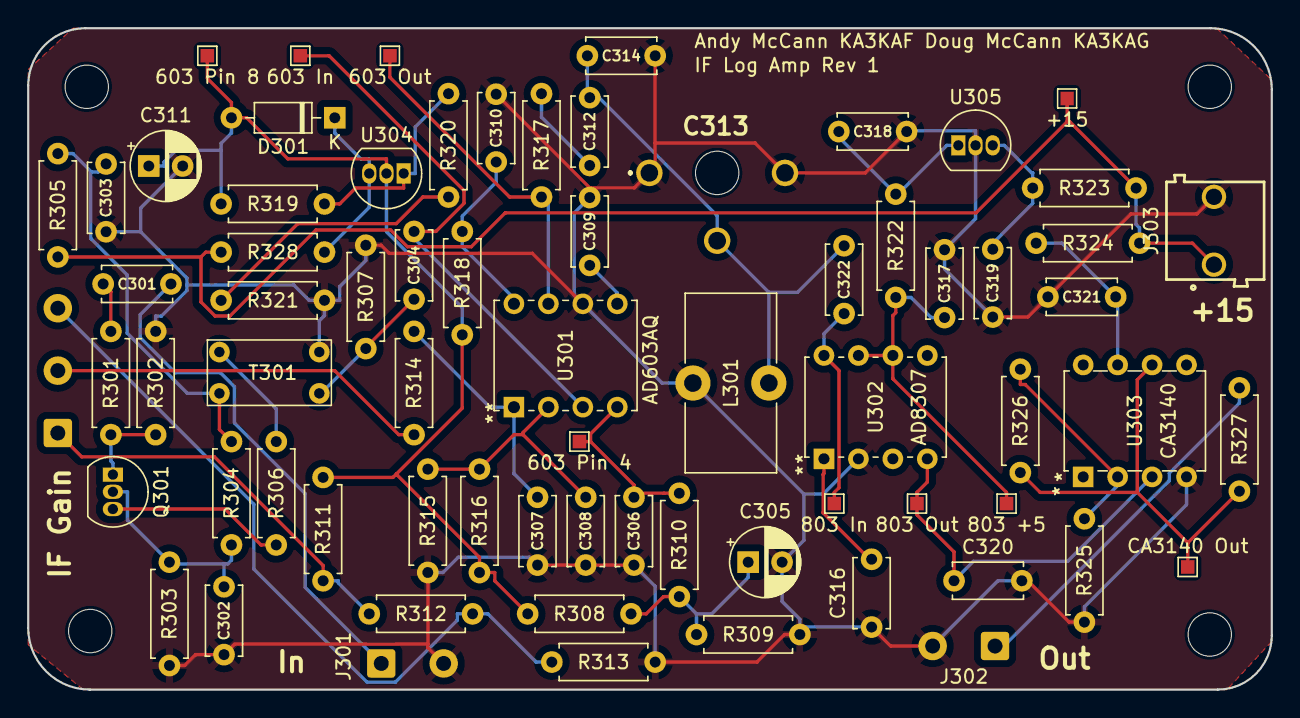
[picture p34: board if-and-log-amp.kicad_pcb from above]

Board: 2 copper layers, 91.7 x 48.8 mm, 75 parts (0 on the bottom side), 37 nets.

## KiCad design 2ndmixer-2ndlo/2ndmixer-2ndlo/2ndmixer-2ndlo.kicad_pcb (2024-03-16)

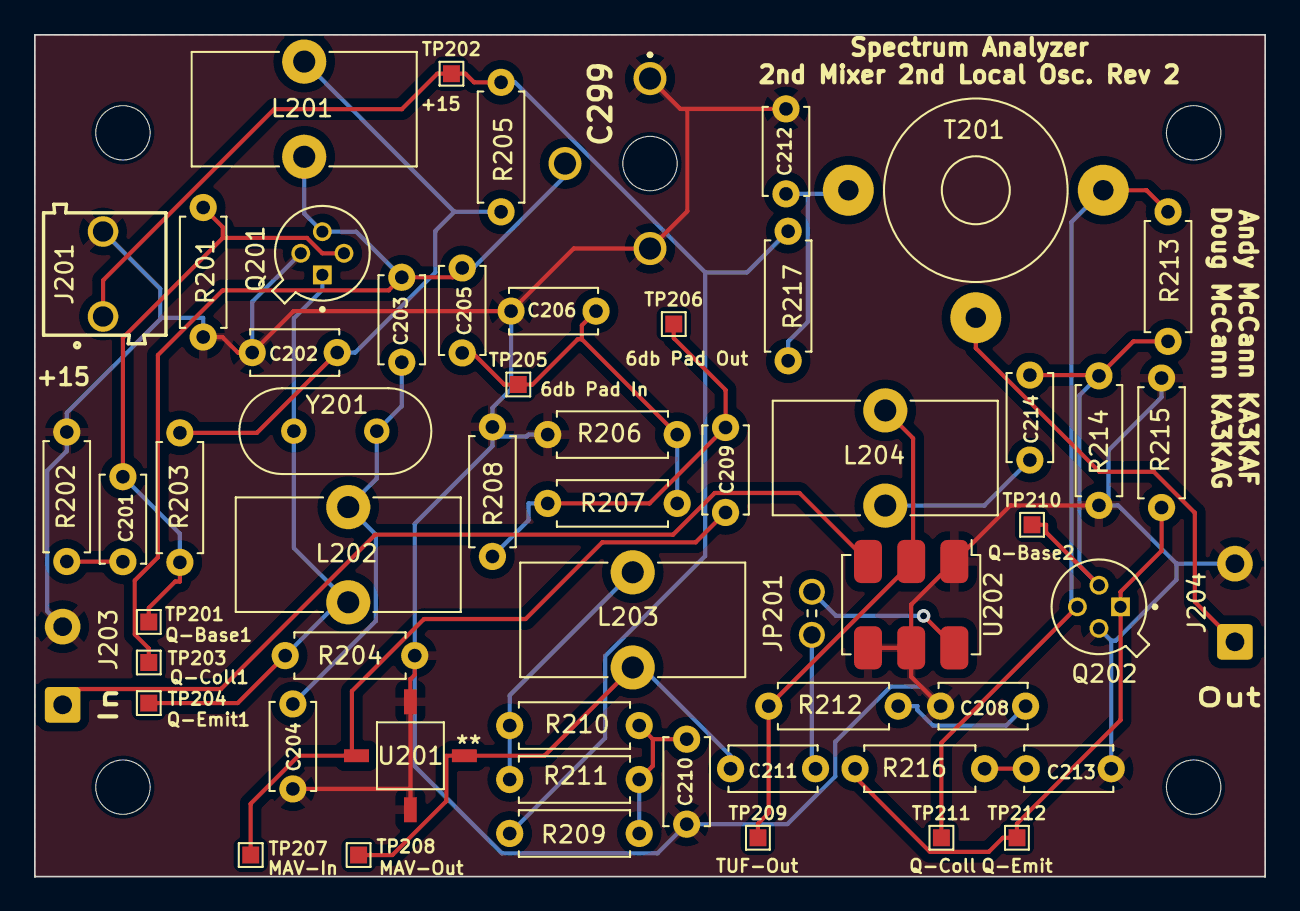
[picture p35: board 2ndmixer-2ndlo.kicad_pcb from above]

Board: 2 copper layers, 72.4 x 49.5 mm, 61 parts (0 on the bottom side), 26 nets.

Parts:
C201, C202: 470p; C_Disc_D5.0mm_W2.5mm_P5.00mm
C203, C204: 33p; C_Disc_D5.0mm_W2.5mm_P5.00mm
C205: 15p; C_Disc_D5.0mm_W2.5mm_P5.00mm
C206: 82p; C_Disc_D5.0mm_W2.5mm_P5.00mm
C208: 120p; C_Disc_D5.0mm_W2.5mm_P5.00mm
C209, C210, C211: .01u; C_Disc_D5.0mm_W2.5mm_P5.00mm
C212, C213, C214: .1u; C_Disc_D5.0mm_W2.5mm_P5.00mm
C299: 12p-60p; BFC280831659
H201, H202, H203, H204: MountingHole; MountingHole_3.2mm_M3
J201: Conn_01x02; 691103110002
J203: 110 MHz In; SolderWire-0.5sqmm_1x02_P4.6mm_D0.9mm_OD2.1mm
J204: 2nd IF Out; SolderWire-0.5sqmm_1x02_P4.6mm_D0.9mm_OD2.1mm
JP201: 5025; KEYSTONE_5025
L201: 40n; L_Toroid_Vertical_L13.0mm_W6.5mm_P5.60mm
L202: 420n; L_Toroid_Vertical_L13.0mm_W6.5mm_P5.60mm
L203, L204: 1u; L_Toroid_Vertical_L13.0mm_W6.5mm_P5.60mm
Q201, Q202: 2N5179; TO127P584H533-4N
R201, R213: 2k; R_Axial_DIN0207_L6.3mm_D2.5mm_P7.62mm_Horizontal
R202: 39; R_Axial_DIN0207_L6.3mm_D2.5mm_P7.62mm_Horizontal
R203: 3.3k; R_Axial_DIN0207_L6.3mm_D2.5mm_P7.62mm_Horizontal
R204: 510; R_Axial_DIN0207_L6.3mm_D2.5mm_P7.62mm_Horizontal
R205: 100; R_Axial_DIN0207_L6.3mm_D2.5mm_P7.62mm_Horizontal
R206, R208: 150; R_Axial_DIN0207_L6.3mm_D2.5mm_P7.62mm_Horizontal
R207: 36; R_Axial_DIN0207_L6.3mm_D2.5mm_P7.62mm_Horizontal
R209: 47; R_Axial_DIN0207_L6.3mm_D2.5mm_P7.62mm_Horizontal
R210, R211: 220; R_Axial_DIN0207_L6.3mm_D2.5mm_P7.62mm_Horizontal
R212: 51; R_Axial_DIN0207_L6.3mm_D2.5mm_P7.62mm_Horizontal
R214: 390; R_Axial_DIN0207_L6.3mm_D2.5mm_P7.62mm_Horizontal
R215, R217: 27; R_Axial_DIN0207_L6.3mm_D2.5mm_P7.62mm_Horizontal
R216: 5.1; R_Axial_DIN0207_L6.3mm_D2.5mm_P7.62mm_Horizontal
T201: Bifilar_Transformer; Autotransformer_Toroid_1Tap_Horizontal_D10.5mm_Amidon-T37
TP201: Q-Base1; TestPoint_Pad_1.0x1.0mm
TP202: +15; TestPoint_Pad_1.0x1.0mm
TP203: Q-Coll1; TestPoint_Pad_1.0x1.0mm
TP204: Q-Emit1; TestPoint_Pad_1.0x1.0mm
TP205: 6db Pad In; TestPoint_Pad_1.0x1.0mm
TP206: 6db Pad Out; TestPoint_Pad_1.0x1.0mm
TP207: MAV-In; TestPoint_Pad_1.0x1.0mm
TP208: MAV-Out; TestPoint_Pad_1.0x1.0mm
TP209: ADE-Out; TestPoint_Pad_1.0x1.0mm
TP210: Q-Base2; TestPoint_Pad_1.0x1.0mm
TP211: Q-Coll2; TestPoint_Pad_1.0x1.0mm
TP212: Q-Emit2; TestPoint_Pad_1.0x1.0mm
U201: MAV-11; MAV-11BSM&plus_
U202: ADE-1HW+; Mini-Circuits_CD636_H4.11mm
Y201: 100MHz; Crystal_HC49-U_Vertical

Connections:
/+15: J201.1, R205.1, R209.1, R217.1, TP202.1
GND: C202.2, C204.2, C206.2, C208.2, C210.2, C212.1, C213.1, C299.1 (R_1), C299.3 (R_2), J201.2, J203.2 (Ext), J204.2 (Ext), Q201.4 (SHIELD), Q202.4 (SHIELD), R201.2, R202.2, R204.2, R206.2, R208.2, R214.2, R215.2, U201.2 (GND), U201.4 (GND), U202.1 (GND), U202.4 (GND), U202.5 (GND)
unnamed: C201.1, Q201.2, R201.1, R203.2, TP201.1
unnamed: C201.2, R202.1
unnamed: C202.1, L201.1, R203.1, R205.2
unnamed: C203.2, C204.1, L202.1, Y201.2
unnamed: C205.2, C206.1, R206.1, R207.1, TP205.1
unnamed: C208.1, R212.2
unnamed: C209.1, R207.2, R208.1, TP206.1
unnamed: C210.1, R209.2, R210.1, R211.1
unnamed: C211.2, JP201.1
unnamed: C212.2, R217.2, T201.1
unnamed: C213.2, R216.2
unnamed: C214.1, L204.2
unnamed: C214.2, Q202.2, R213.2, R214.1, TP210.1
unnamed: C203.1, C205.1, C299.2 (S), L201.2, Q201.3, TP203.1
unnamed: J203.1 (In), U202.3 (RF)
unnamed: J204.1 (In), T201.2
unnamed: L202.2, Q201.1, R204.1, TP204.1, Y201.1
unnamed: L203.1, R210.2, R211.2
unnamed: Q202.1, R215.1, R216.1, TP212.1
unnamed: Q202.3, R213.1, T201.3, TP211.1
unnamed: C209.2, TP207.1, U201.1 (RF_In)
unnamed: C211.1, L203.2, TP208.1, U201.3 (RF_Out)
unnamed: L204.1, R212.1, TP209.1, U202.2 (IF)
unnamed: JP201.2, U202.6 (LO)

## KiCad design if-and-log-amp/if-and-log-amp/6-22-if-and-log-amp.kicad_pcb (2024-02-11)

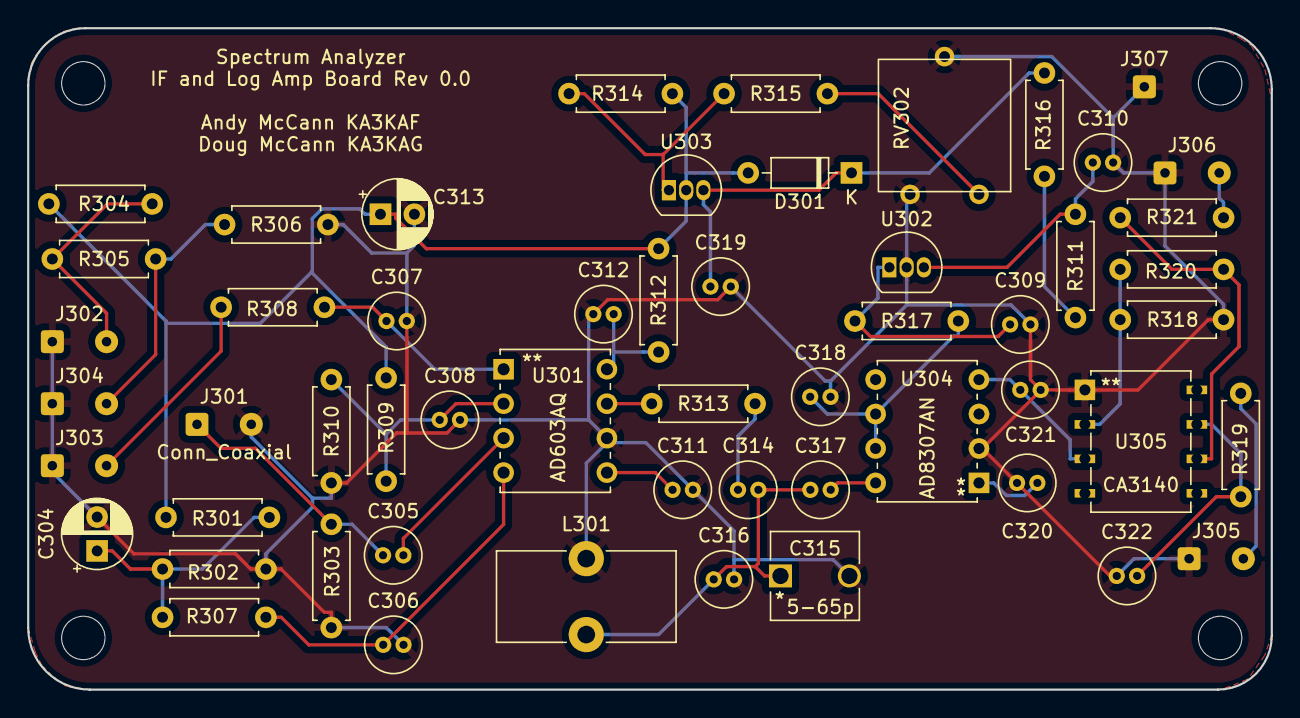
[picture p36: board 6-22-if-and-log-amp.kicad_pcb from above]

Board: 2 copper layers, 91.7 x 48.8 mm, 59 parts (0 on the bottom side), 31 nets.

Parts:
C304: 100u; CP_Radial_D5.0mm_P2.50mm
C305: .01u; C_Radial_D4.0mm_H5.0mm_P1.50mm
C306, C307, C308, C309, C312, C318, C319, C320, C322: .1u; C_Radial_D4.0mm_H5.0mm_P1.50mm
C310: .22u; C_Radial_D4.0mm_H5.0mm_P1.50mm
C311: 18u; C_Radial_D4.0mm_H5.0mm_P1.50mm
C313: 22u; CP_Radial_D5.0mm_P2.50mm
C314, C317: 5.6p; C_Radial_D4.0mm_H5.0mm_P1.50mm
C315: 5-65p; GKG60015
C316: 220p; C_Radial_D4.0mm_H5.0mm_P1.50mm
C321: .001u; C_Radial_D4.0mm_H5.0mm_P1.50mm
D301: 1N4152; D_DO-35_SOD27_P7.62mm_Horizontal
H301, H302, H303, H304: MountingHole; MountingHole_3.2mm_M3
J301: Conn_Coaxial; SolderWire-0.15sqmm_1x02_P4mm_D0.5mm_OD1.5mm
J302, J303, J304, J305, J306: Conn_01x02_Male; SolderWire-0.15sqmm_1x02_P4mm_D0.5mm_OD1.5mm
J307: Board to Box Ground; SolderWire-0.15sqmm_1x01_D0.5mm_OD1.5mm
L301: 1.05u; L_Toroid_Vertical_L13.0mm_W6.5mm_P5.60mm
R301, R302, R308, R320: 2.2k; R_Axial_DIN0207_L6.3mm_D2.5mm_P7.62mm_Horizontal
R303: 100; R_Axial_DIN0207_L6.3mm_D2.5mm_P7.62mm_Horizontal
R304, R318: 680; R_Axial_DIN0207_L6.3mm_D2.5mm_P7.62mm_Horizontal
R305: 510; R_Axial_DIN0207_L6.3mm_D2.5mm_P7.62mm_Horizontal
R306, R313, R321: 1k; R_Axial_DIN0207_L6.3mm_D2.5mm_P7.62mm_Horizontal
R307, R319: 51; R_Axial_DIN0207_L6.3mm_D2.5mm_P7.62mm_Horizontal
R309: 4.3k; R_Axial_DIN0207_L6.3mm_D2.5mm_P7.62mm_Horizontal
R310: 5.6k; R_Axial_DIN0207_L6.3mm_D2.5mm_P7.62mm_Horizontal
R311, R312, R316, R317: 10; R_Axial_DIN0207_L6.3mm_D2.5mm_P7.62mm_Horizontal
R314: 220; R_Axial_DIN0207_L6.3mm_D2.5mm_P7.62mm_Horizontal
R315: 1.5k; R_Axial_DIN0207_L6.3mm_D2.5mm_P7.62mm_Horizontal
RV302: 100; Potentiometer_Bourns_3386G_Vertical
U301: AD603AQ
U302: L78L05_TO92; TO-92_Inline
U303: LM317L_TO92; TO-92_Inline
U304: AD8307AN
U305: CA3140; CA3140EZ

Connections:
+5: C309.1, R317.1, U302.1 (VO)
+10: C313.1, D301.2 (A), R301.1, R304.1, R309.2, R312.1, R314.1, U303.2 (VO)
+15: R311.1, R316.1
GND: C304.2, C306.2, C307.2, C308.2, C309.2, C310.2, C311.2, C312.1, C313.2, C315.2, C316.2, C318.2, C319.2, C320.1, C321.2, C322.1, J301.2 (Ext), J302.1, J303.1, J304.1, J305.1, J306.1, J307.1, L301.1, R302.2, R303.2, R306.2, R310.2, R318.2, RV302.2, RV302.3, U301.6 (VNEG), U302.2 (GND), U304.2 (COM), U305.1 (NULL)
unnamed: J302.2, R304.2, R305.1
unnamed: J303.2, R308.2
unnamed: J304.2, R305.2, R306.1
unnamed: C304.1, R301.2, R302.1, R307.1
unnamed: C305.1, J301.1 (In), R303.1
unnamed: C305.2, U301.3 (VINP)
unnamed: C306.1, R307.2, U301.4 (COMM)
unnamed: C307.1, R308.1, U301.1 (GPOS)
unnamed: C308.1, R309.1, R310.1, U301.2 (GNEG)
unnamed: C310.1, R311.2, U302.3 (VI)
unnamed: C311.1, U301.5 (FDBK)
unnamed: C312.2, R312.2, U301.8 (VPOS)
unnamed: C314.1, R313.2
unnamed: C314.2, C315.1, C316.1, C317.1, L301.2
unnamed: C317.2, U304.8 (INP)
unnamed: C318.1, R317.2, U304.6 (ENB), U304.7 (VPS)
unnamed: C319.1, D301.1 (K), R316.2, U303.3 (VI)
unnamed: C320.2, U304.1 (INM)
unnamed: C321.1, U304.4 (OUT), U305.3 (+)
unnamed: C322.2, R319.1, U305.7 (V+)
unnamed: J305.2, R319.2
unnamed: R313.1, U301.7 (VOUT)
unnamed: R314.2, R315.1, U303.1 (ADJ)
unnamed: R315.2, RV302.1
unnamed: R318.1, R320.2, U305.2 (-)
unnamed: R320.1, R321.1, U305.6
unnamed: J306.2, R321.2

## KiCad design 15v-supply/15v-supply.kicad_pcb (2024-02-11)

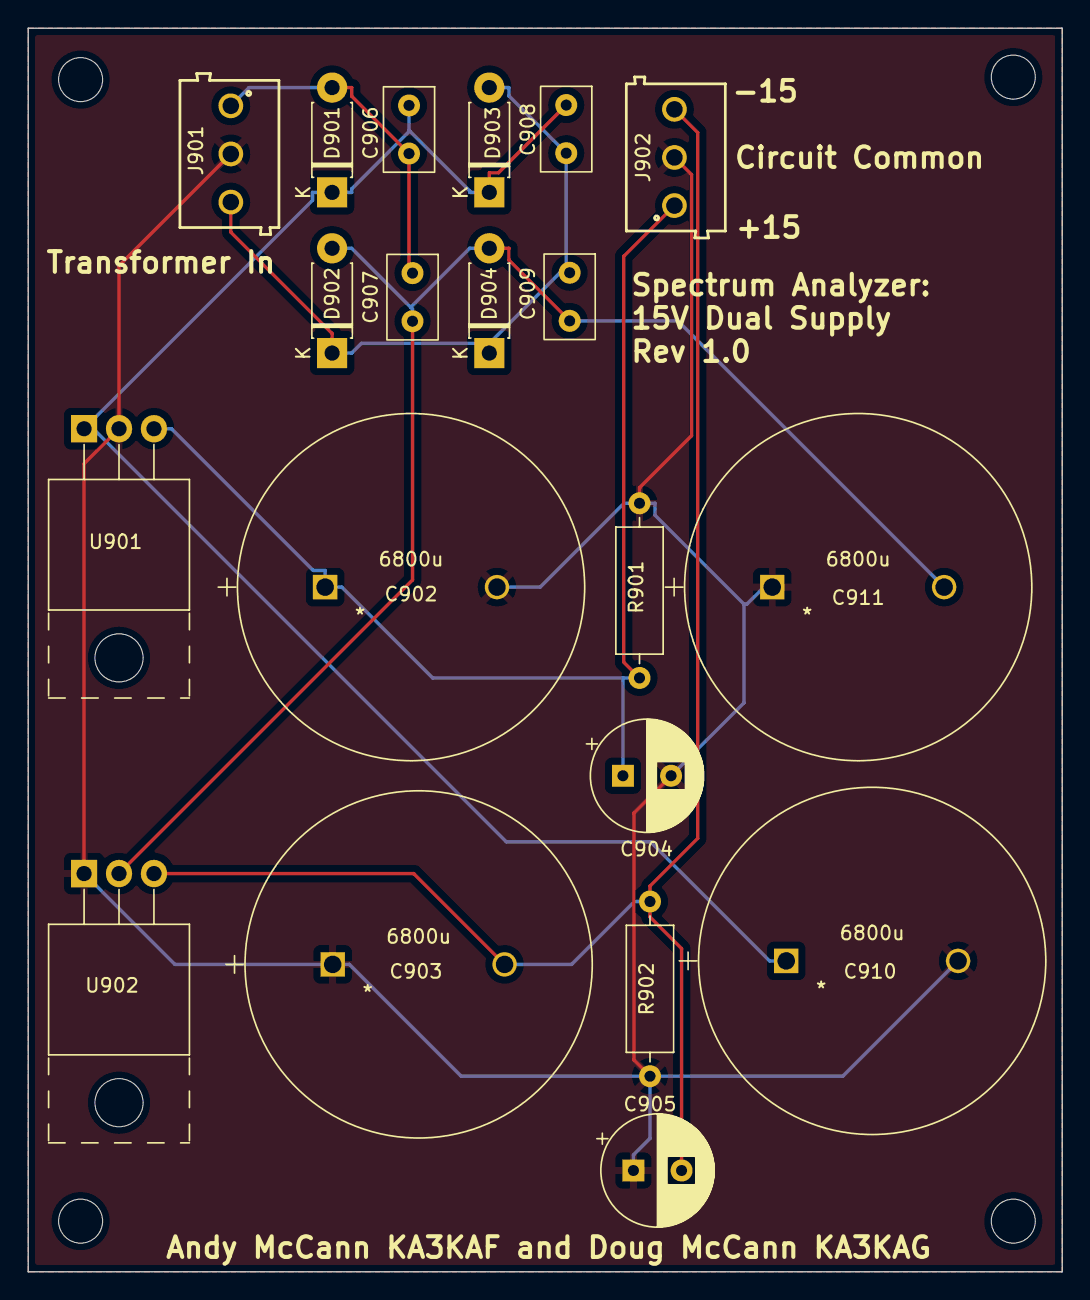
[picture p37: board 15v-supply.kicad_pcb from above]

Board: 2 copper layers, 75.2 x 90.4 mm, 24 parts (0 on the bottom side), 7 nets.

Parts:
C902, C903, C910, C911: 6800u; 6800u-UVR1H682MRD6
C904, C905: 6.8u; CP_Radial_D8.0mm_P3.50mm
C906, C907, C908, C909: 0.01u; C_Rect_L6.0mm_W3.5mm_P3.5mm_QYX1H103JTP3TA
D901, D902, D903, D904: 1n5060; D_DO-41_SOD81_P7.62mm_Horizontal
H901, H902, H903, H905: MountingHole; MountingHole_3.2mm_M3
J901, J902: 691103110003; terminal-block-691103110003
R901, R902: 2.2k; R_Axial_DIN0309_L9.0mm_D3.2mm_P12.70mm_Horizontal
U901: LM7815; TO-220-3_Horizontal_TabUp
U902: LM7915; TO-220-3_Horizontal_TabUp

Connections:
/7815 IN: C906.1, C908.1, C910.1, D901.1 (Cathode), D903.1 (Cathode), U901.1 (IN)
/7915 IN: C907.2, C909.2, C911.2, D902.2 (Anode), D904.2 (Anode), U902.2 (VI)
/+15 REGULATED: C902.1, C904.1, J902.1, R901.1, U901.3 (OUT)
/-15 REGULATED: C903.2, C905.2, J902.3, R902.2, U902.3 (VO)
/TRAN OUT1: C906.2, C907.1, D901.2 (Anode), J901.1
/TRAN OUT2: C908.2, C909.1, D902.1 (Cathode), D903.2 (Anode), D904.1 (Cathode), J901.3
GND: C902.2, C903.1, C904.2, C905.1, C910.2, C911.1, J901.2, J902.2, R901.2, R902.1, U901.2 (GND), U902.1 (GND)

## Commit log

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2022-05-09 Schematic update
    Improved ability to run sim
    [Timebase.kicad_sch]
2022-05-09 fixing master and main
    [untitled2.kicad_sch]
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2022-05-30 IF and log amp added
    [N_8_ADI.step, Q_8_ADI.step, Timebase.kicad_sch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]
2022-05-30 Improvements to overall schematics
    [W7ZOI Spectrum Analyzer.kicad_sch]
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2022-05-30 fixing schematics
    [W7ZOI Spectrum Analyzer.kicad_sch, if_log_amplifier.kicad_sch]
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2022-05-31 Resolution filters ltspice and kicad files
    [1590B.igs, 1590B.stp, Resolution Filters.kicad_sch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]
2022-06-01 corrected 10V power supply and component values in IF filter
    [W7ZOI Spectrum Analyzer.kicad_sch, if_log_amplifier.kicad_sch]
2022-06-01 updates to if amp section
    [Resolution Filters.kicad_sch]
2022-06-01 Reduced size of timebase pcb
    [Resolution Filters.kicad_sch, Timebase.FCStd, Timebase.kicad_sch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]
2022-06-01 fixed broken wire by R319
    [if_log_amplifier.kicad_sch]
2022-06-01 added missing wire in 10V regulator
    [if_log_amplifier.kicad_sch]
2022-06-05 added schematic for dual polarity supply
    [15v-supply.kicad_pcb, 15v-supply.kicad_sch]
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2022-06-05 changed schematic sheet notes
    [15v-supply.kicad_sch]
2022-06-05 added power flags, ERC checks pass
    [15v-supply.kicad_sch]
2022-06-06 updated schematic -- cannot pass erc
    [15v-supply.kicad_sch]
2022-06-07 updates to 15 v supply and if log amp boards
    [15v-supply.kicad_sch, W7ZOI Spectrum Analyzer.kicad_sch, W7ZOI_Spectrum_Analyzer_IFand_LogAmp.pro.kicad_pcb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]
2022-06-09 updates to the 15v-supply spice models
    [dem-kicad-spice-test.kicad_pcb, dem-kicad-spice-test.kicad_sch]
2022-06-12 Significant changes to timebase spice, 15v supply and resolution-filters
    [15v-power-supply.kicad_sch, 5-1634503-1.step, CUI-PJ-007.FCStd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]
2022-06-15 Changes to 15v supply including symbol annotation, BOM, footprints, and folder reorg
    [15v-supply.kicad_sch, 3386G001XXX.stp, AD603AQ.step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]
2022-06-15 more improvements to 15v-supply
    [15v-supply.kicad_pcb, 15v-supply.kicad_sch, 691103110003.step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]
2022-06-16 15v-supply routed and poured
    [15v-supply-B_Cu.dxf, 15v-supply-B_Mask.dxf, 15v-supply-B_Paste.dxf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]
2022-06-18 updated spice library path, edited silkscreen and schematic for rev0.0
    [15v-supply.kicad_pcb, 15v-supply.kicad_sch]
2022-06-18 if and log amp routing and 3d model
    [1590B.stp, 15v-power-supply.kicad_sch, 15v-supply.kicad_pcb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]
2022-06-19 Improvements to if and log amp
    [15v-supply-B_Cu.dxf, 15v-supply-B_Mask.dxf, 15v-supply-B_Paste.dxf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]
2022-06-19 changed 220p cap back to variable
    [if-and-log-amp.kicad_sch]
2022-06-19 cleanup of W7ZOI Spectrum Analyzer project files
    [1590B.igs, 1590B.stp, CUI_DEVICES_PJ-007.step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]
2022-06-19 further improvements on folder organization
    [15v-power-supply.kicad_sch, Resolution Filters.kicad_sch, Timebase.kicad_sch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]
2022-06-19 improvements to hierarchical schematic
    [15v-power-supply.kicad_sch, Timebase.kicad_sch, W7ZOI Spectrum Analyzer.kicad_sch]
2022-06-21 updates to 15v supply and if and log amp boards so boards can be sent to fab
    [15v-supply-F_Silkscreen.dxf, 15v-supply-board.FCStd, 15v-supply.kicad_pcb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]
2022-06-23 resolution filter with crystal filter added
    [resolution-filters.kicad_sch]
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2022-07-20 some improvements to timebase and if log amp
    [if-and-log-amp.kicad_sch, timebase.kicad_pcb, timebase.kicad_sch]
2022-07-20 Rev 1 Changes for if and log amp
    [DSS1NB32A102Q91A.stl, DSS1NB32A102Q91A.stp, if-and-log-amp.kicad_pcb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]
2022-07-20 minor changes to log amp board
    [if-and-log-amp.kicad_pcb, if-and-log-amp.kicad_sch]
2022-07-23 further improvements to if-log amp
    [IF-Log-Amp.xlsx, if-and-log-amp.kicad_pcb, if-and-log-amp.kicad_sch]
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2022-07-25 revised if and log amp schematic and board
    [691103110002.step, Download_STP_691103110002 (rev1).stp, if-and-log-amp.kicad_pcb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]
2022-07-29 resolution filters board layout
    [resolution-filters.kicad_pcb]
2022-07-30 resolution filter board layout
    [resolution-filters.kicad_pcb]
2022-07-31 updates to if log amp and resolution filter boards
    [33756-68028.step, 691103110002.step, 691103110002_1.step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]
2022-07-31 fix transformer issue
    [L_Tor_13x8x5_3a.stp, L_Tor_13x8x5_3a_cp.step, resolution-filters.kicad_pcb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]
2022-07-31 resolution filter improvement and bom
    [resolution filters.xlsx, resolution-filters-B_Silkscreen.dxf, resolution-filters-F_Silkscreen.dxf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]
2022-08-06 minor fixes to 2ndmixer-2ndlo
    [2ndmixer-2ndlo.kicad_sch]
2022-08-06 made 4 changes to schematic
    [2ndmixer-2ndlo.kicad_sch]
2022-08-06 minor changes to schematic
    [resolution-filters.kicad_sch]
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2022-08-15 Add amp to if-and-log-amp
    [if-and-log-amp.kicad_pcb, if-and-log-amp.kicad_sch]
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2022-08-15 add annotations to 2db-div schematic
    [2db-div.kicad_sch]
2022-08-20 improved if and log amp and second lo/mixer
    [15v-power-supply.kicad_sch, 15v-supply.kicad_sch, 2db-div.kicad_sch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]
2022-08-20 added some test points
    [2ndmixer-2ndlo.kicad_sch]
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2022-08-21 vco 1st mixer board
    [22-28-4028_MOL.step, 2ndmixer-2ndlo.kicad_sch, 691103110002_1.step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]
2022-08-21 2ndmixer-2ndlo bom and corrections
    [2ndmixer-2ndlo.kicad_pcb, 2ndmixer-2ndlo.kicad_sch, 2ndmixer-2ndlo.xlsx]
2022-08-21 minor fix to 2ndmixer-2ndlo
    [2ndmixer-2ndlo.kicad_sch, W7ZOI Spectrum Analyzer.kicad_sch]
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2022-08-24 update to 15v schematic and trying new theme
    [15v-supply.kicad_sch, 70mhz-lp-filter.xlsx, 70mhz-lpf.kicad_sch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]
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2022-08-25 2ndmixer-2ndlo pcb fix
    [2ndmixer-2ndlo.kicad_pcb]
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2022-12-11 Fix POS200 footprint and Terminal Block footprint of VCO 1st Mixer Board. Rev 1.
    [2ndmixer-2ndlo.kicad_sch, resolution-filters.kicad_pcb, resolution-filters.kicad_sch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]
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2022-12-27 qex 1998 article and changes to vco 1st mixer pcb
    [vco-1stmixer.kicad_pcb]
2023-01-08 Fixes to 2ndmixer-2ndlo and vco-1stmixer
    [2ndmixer-2ndlo.kicad_pcb, 2ndmixer-2ndlo.kicad_sch, 70mhz-lpf.kicad_pcb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]
2023-01-16 corrections to resolution-filters
    [resolution-filters.kicad_sch]
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2023-01-16 resolution-filters - one more fix
    [resolution-filters.kicad_sch]
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2023-03-11 Fix tuf1h symbol
    [2ndmixer-2ndlo.kicad_sch]
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2023-03-12 saved error reports
    [vco-1stmixer.xlsx]
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2023-07-08 self oscillator
    [2N4117A.STEP, 2ndmixer-2ndlo-F_Silkscreen.dxf, 691103110002_1.step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]
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2023-11-19 partial 2nd lo fixes
    [2ndmixer-2ndlo.kicad_pcb, 2ndmixer-2ndlo.kicad_sch]
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2023-11-30 further change to 2nd LO schematic and board
    [2ndmixer-2ndlo.kicad_pcb, 2ndmixer-2ndlo.kicad_sch]
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2023-12-21 Minor updates to 2nd db board
    primarily renaming nets
    [2db-div.kicad_pcb, 2db-div.kicad_sch]
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2024-01-07 correction to hierarchical schematic
    [if_log_amplifier.kicad_sch]
2024-01-07 adding 7mhz crystal oscillator
    [7mhz-crystal-oscillator.kicad_pcb, 7mhz-crystal-oscillator.kicad_sch, if-and-log-amp.kicad_sch]
2024-01-19 7mhz xtal oscillator
    [7mhz-crystal-oscillator.kicad_sch]
2024-01-21 crystal oscillator models
    [7mhz-crystal-oscillator.kicad_sch]
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2024-02-04 timebase rev 1 - fixes silkscreen
    [timebase.kicad_pcb]
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2024-02-11 if and log amp - add version 0 pcb to directory
    [6-22-if-and-log-amp.kicad_pcb, if-and-log-amp.kicad_pcb]
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

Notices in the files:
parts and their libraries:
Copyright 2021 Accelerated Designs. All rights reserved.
